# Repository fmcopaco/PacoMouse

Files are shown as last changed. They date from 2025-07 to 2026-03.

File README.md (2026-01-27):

# PacoMouse

Firmware for a throttle on the Arduino Nano or Wemos D1 Mini (ESP8266) platform. 
  * Versions for Loconet, Loconet over TCP/IP, Xpressnet, Xpressnet LAN, ECoS or Z21 protocols
  * Control of Locomotives
  * Control of accesories (turnouts, turntable, etc.)
  * CV and LNCV programming
  * Dispatch and phone lock feature
  * Locking of some features for guest or club use.
  * Automation
  * Games
  * Rotary encoder for loco speed and direction
  * Option for lever switch direction control
  * Keypad for easy numeric input
  * OLED in different sizes
  * Hardware test program included
  * Avaiable in different languages:

  Lang
  
---

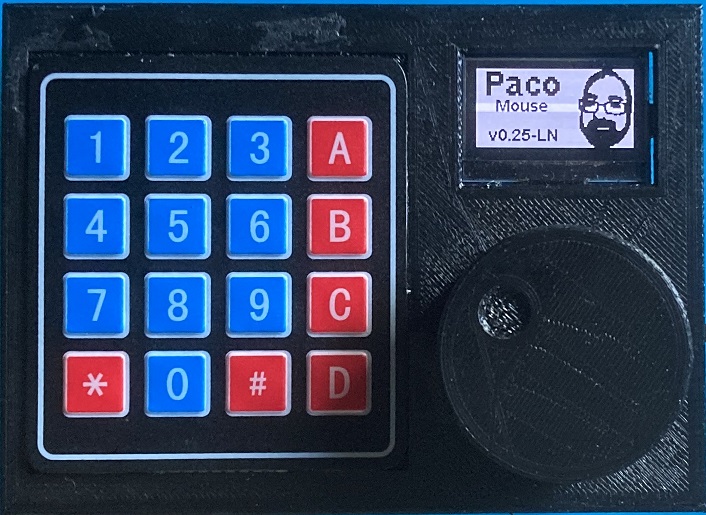
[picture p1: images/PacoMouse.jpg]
FirstVersion
  

  ## Videos

  PacoMouseRun (https://www.youtube.com/watch?v=anvKXDgOZIg)

  PacoMouseAutomation (https://www.youtube.com/watch?v=3rrbmPnA1nU)

  PacoMouseAutomation (https://www.youtube.com/watch?v=WS09ZdihYSQ)

  PacoMouseAutomation (https://www.youtube.com/watch?v=uLCelb744ps)

---

## Copyright
Copyright (c) 2022-2025 Paco Cañada, [The Pows](https://usuaris.tinet.cat/fmco/)   
All rights reserved.

---

## Documentation
- https://usuaris.tinet.cat/fmco/
- https://fmcopaco.github.io/
- Read the [manual](doc/PacoMouse_manual_v0.30.pdf) in the doc directory
- Step-by-step assembly of PacoMouse by [Isaac](https://www.iguadix.es/content/pacomouse-diy)

---

## License
Proprietary.  
Sources are only provided to compile and upload to the device.    
Modifiyng source code or forking/publishing this project ist not allowed.  
Commercial use is forbidden.  

---

## Used Libraries
  * ESP8266WiFi (LGPL)
  * WiFiUdp (LGPL)
  * Wire (LGPL)
  * Keypad (GNU)
  * Keypad_I2C (LGPL)
  * SSD1306Ascii (MIT)
  * SSD1306AsciiAvrI2c (MIT)
  * SSD1306AsciiWire (MIT)
  * LocoNet (LGPL)

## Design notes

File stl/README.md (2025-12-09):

# PacoMouse 3D files

STL files for PacoMouse

## PacoMouse Box

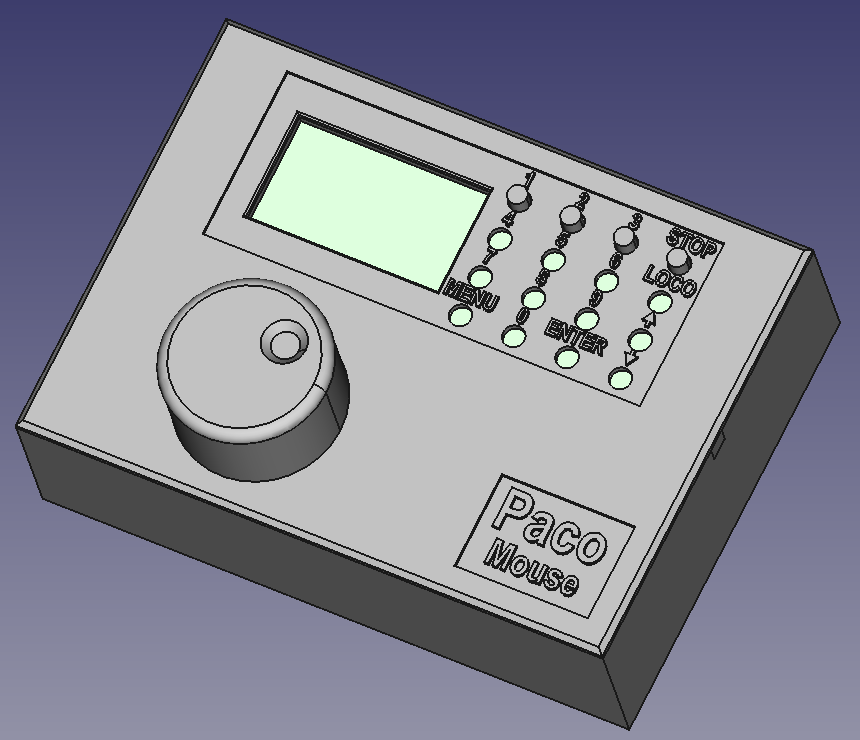
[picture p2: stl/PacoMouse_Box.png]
 

## PacoMouse Console

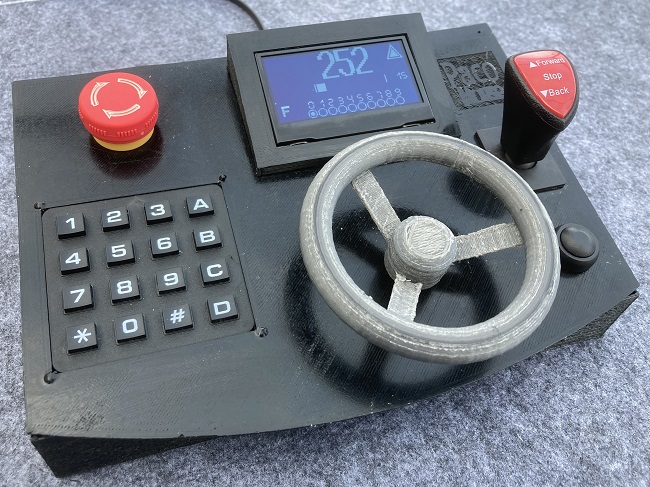
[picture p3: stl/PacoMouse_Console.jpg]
 
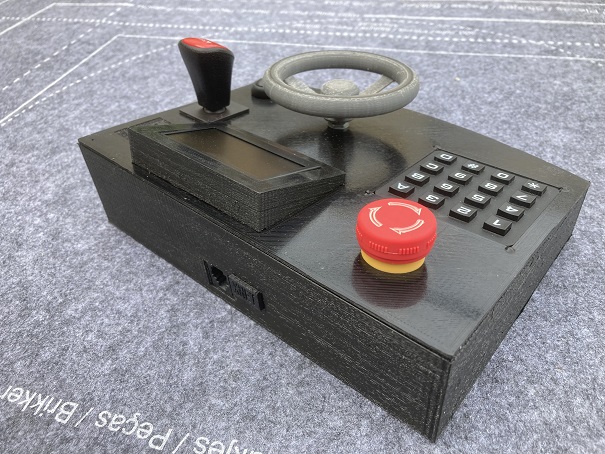
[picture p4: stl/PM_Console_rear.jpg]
 

## Other PacoMouse STL files

Isaac Guadix - https://www.iguadix.es/content/pacomouse-diy

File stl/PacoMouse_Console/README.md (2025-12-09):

# PacoMouse Console 3D files

## Bill of materials (BOM)

* Keypad 4x4
* Encoder EC11
* OLED (SSD1306, SH1106, SSD1309)
* PCB PacoMouse
* KCD4-604-6P (DPDT switch)
* Emergency switch 16mm
* Pushbutton 12mm
* 3 Screws M3x14mm
* 4 Screws M2x4mm
* 4 screws M2x6mm
* 4 Brass threaded insert M2x2
* 3 Brass threaded insert M3x4

## Wiring

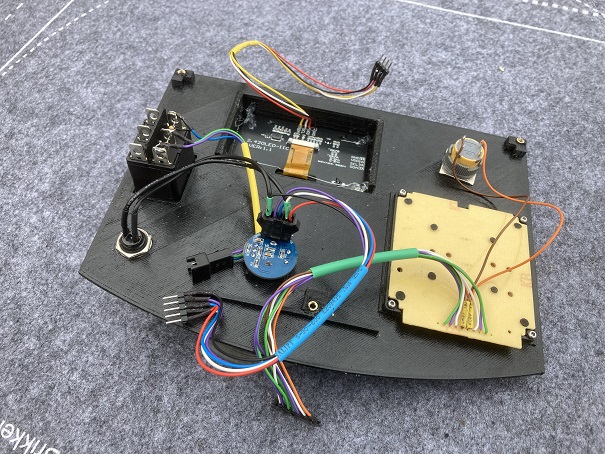
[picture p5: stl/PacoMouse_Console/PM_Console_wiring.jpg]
3dfile


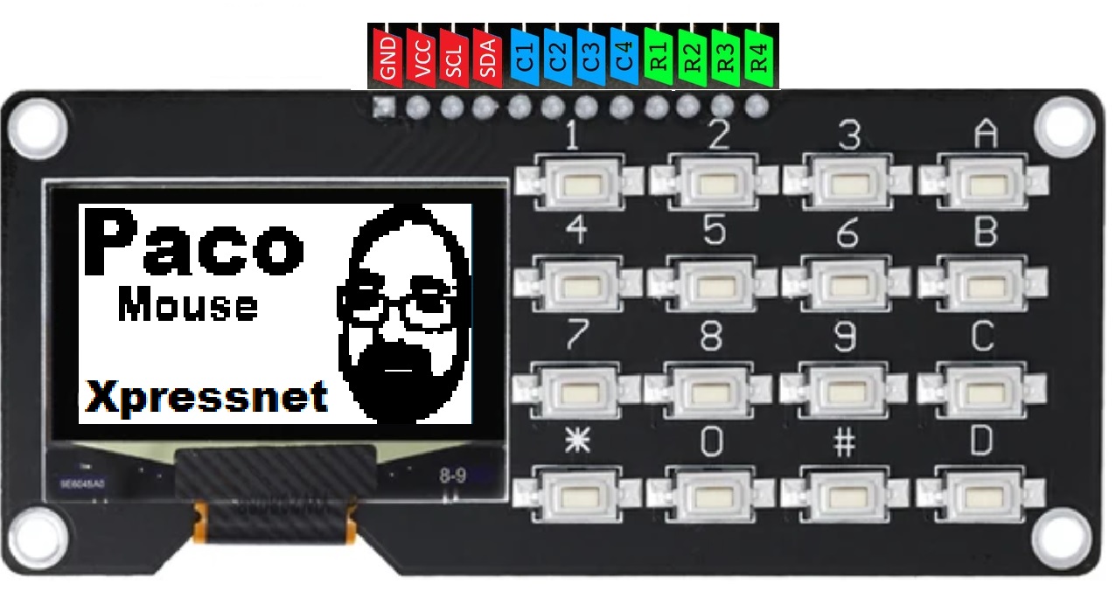
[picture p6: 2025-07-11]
images/oled_keypad4x4_pinout.jpg

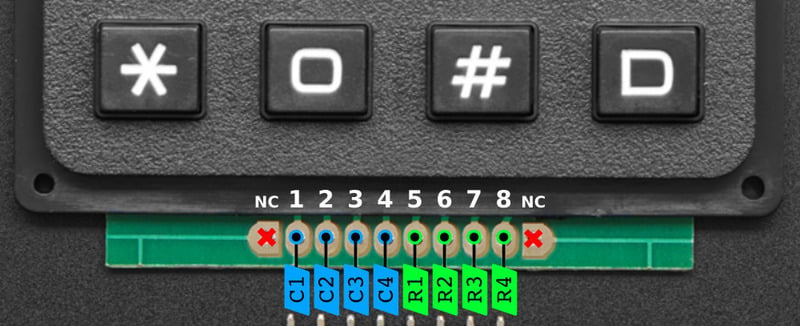
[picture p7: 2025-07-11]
images/keypad4x4_pinout.jpg

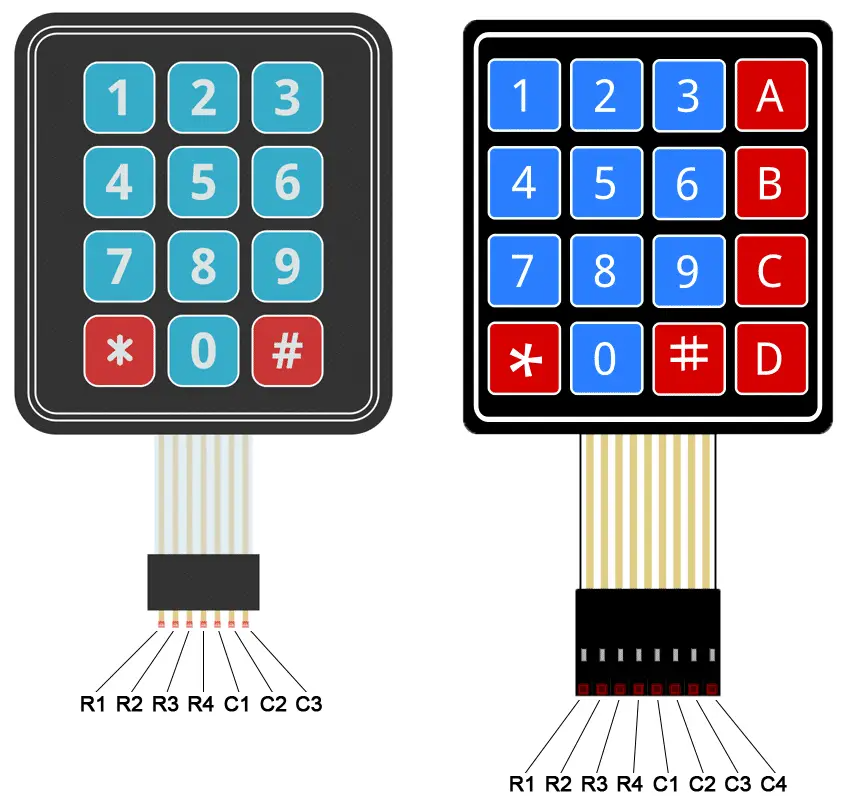
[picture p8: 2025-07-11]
images/keypad-pinout.png

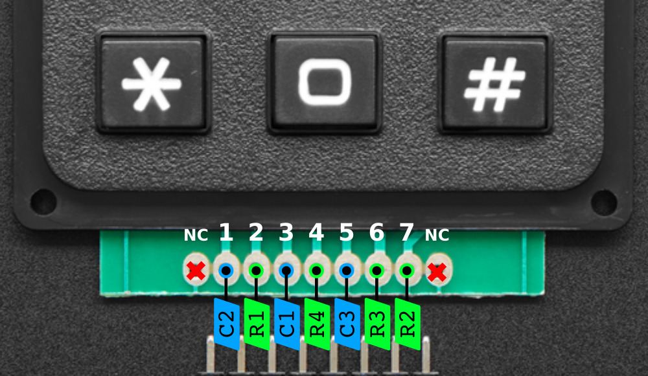
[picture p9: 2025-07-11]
images/keypad3x4_pinout.jpg

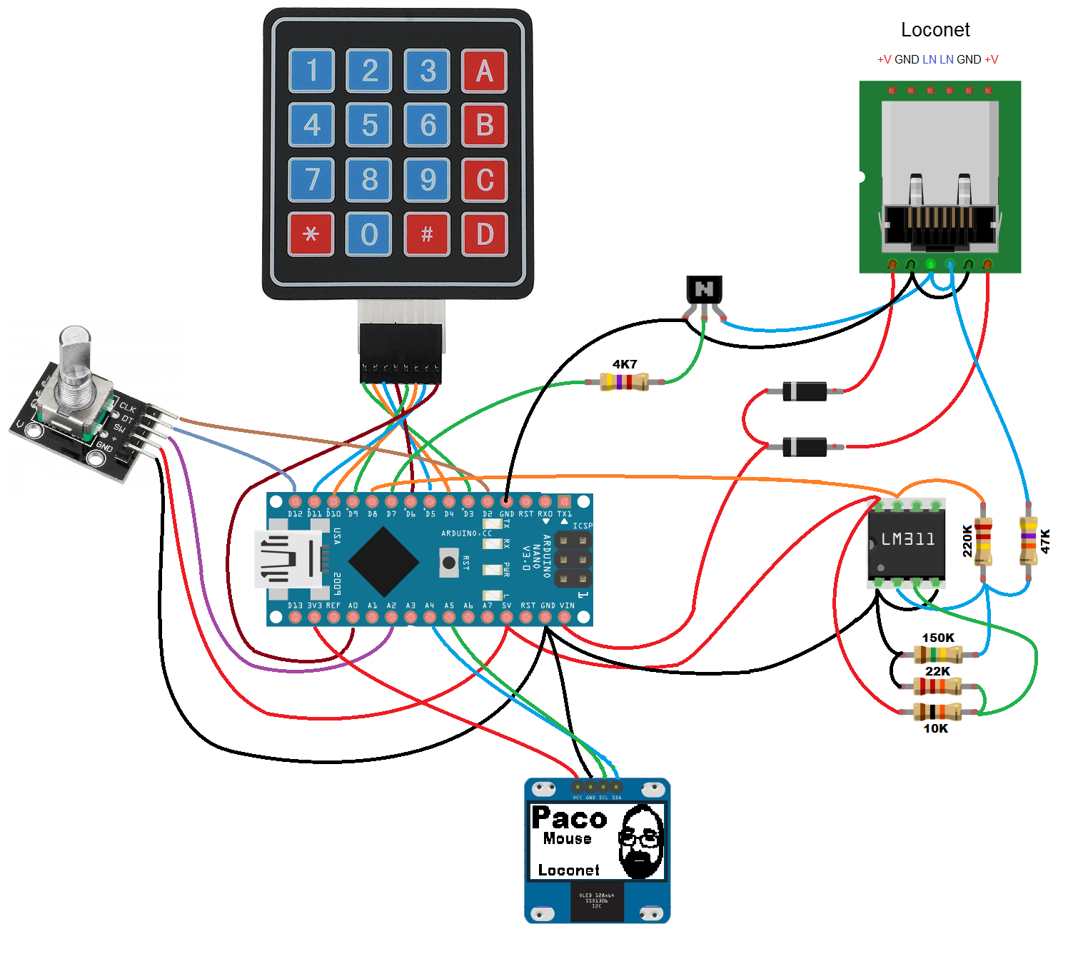
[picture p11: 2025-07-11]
images/PacoMouse_lnet_sch.png

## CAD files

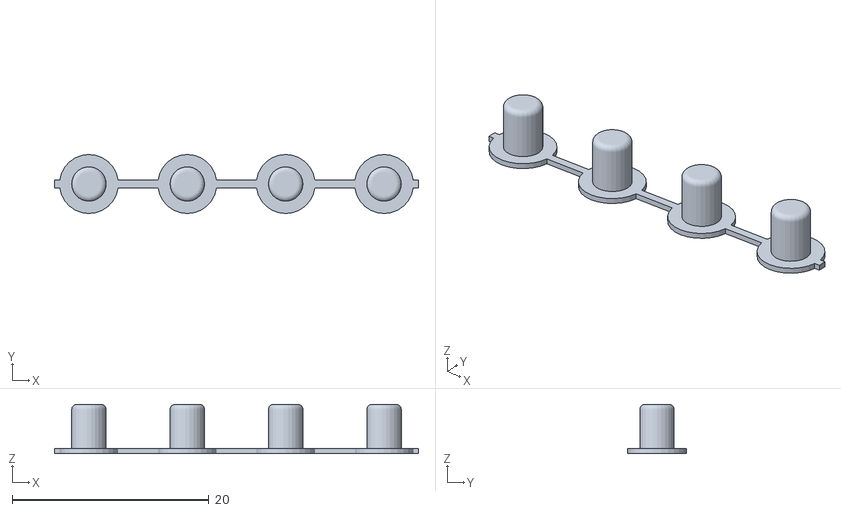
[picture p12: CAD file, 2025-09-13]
stl/PacoMouse_Box/PacoMouse_ConsoleLittle-Botones.stl
37.0 x 6.00 x 5.00

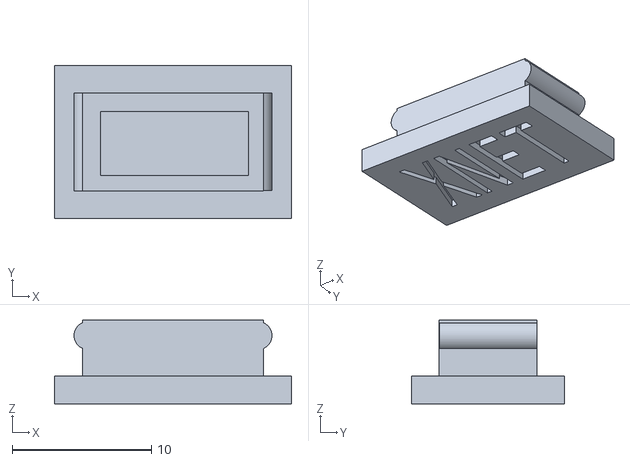
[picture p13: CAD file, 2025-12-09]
stl/PacoMouse_Console/Tapa XNET.stl
17.0 x 11.0 x 6.00

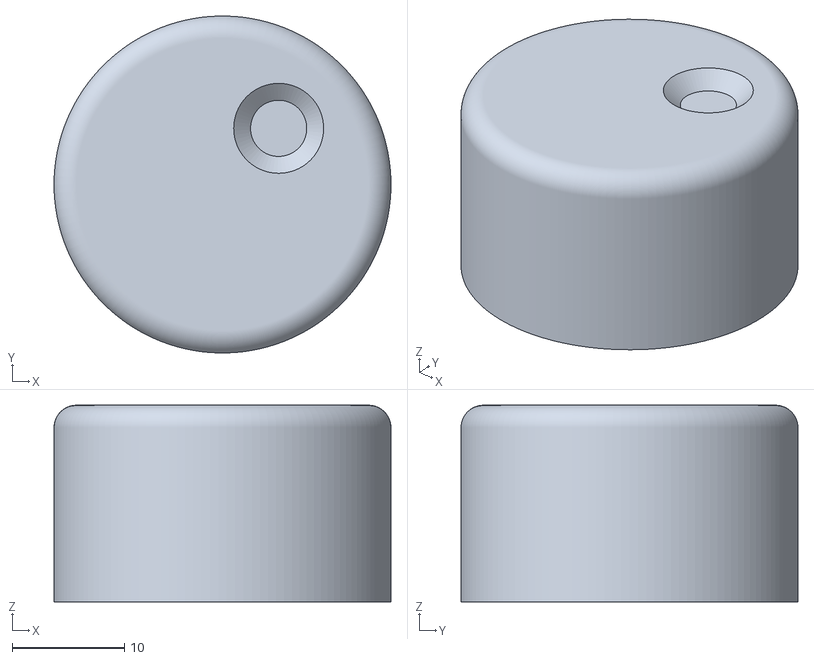
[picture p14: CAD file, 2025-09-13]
stl/PacoMouse_Box/PacoMouse_ConsoleLittle-Knob.stl
30.0 x 30.0 x 17.5

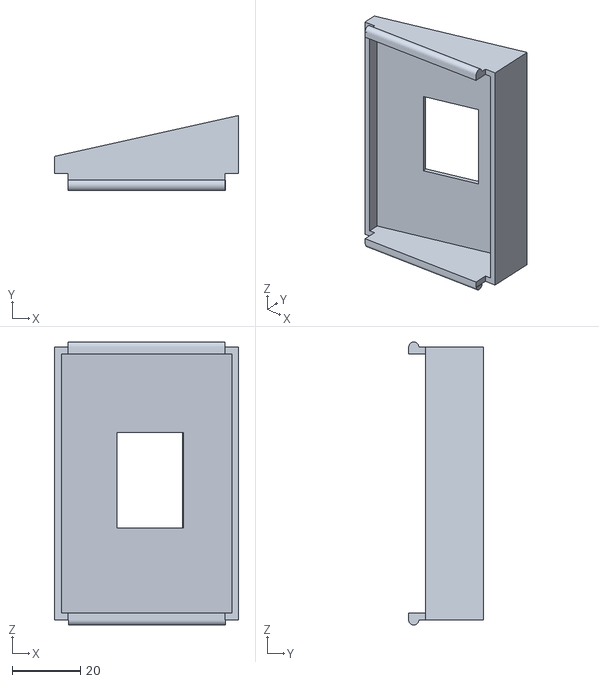
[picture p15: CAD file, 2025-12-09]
stl/PacoMouse_Console/PacoMouse OLED 096.stl
54.0 x 22.0 x 83.0

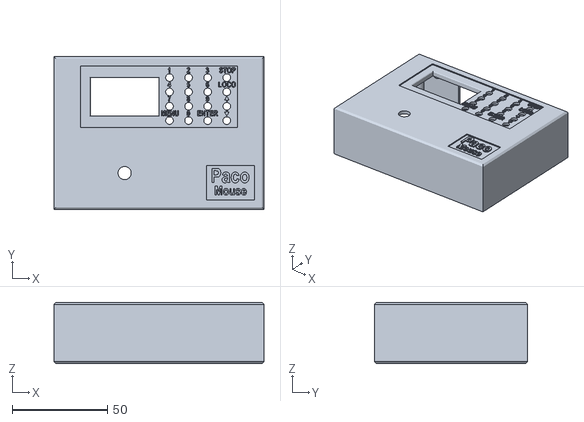
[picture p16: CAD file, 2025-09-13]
stl/PacoMouse_Box/PacoMouse_ConsoleLittle_v2-Top Cover.stl
110.0 x 80.0 x 32.0

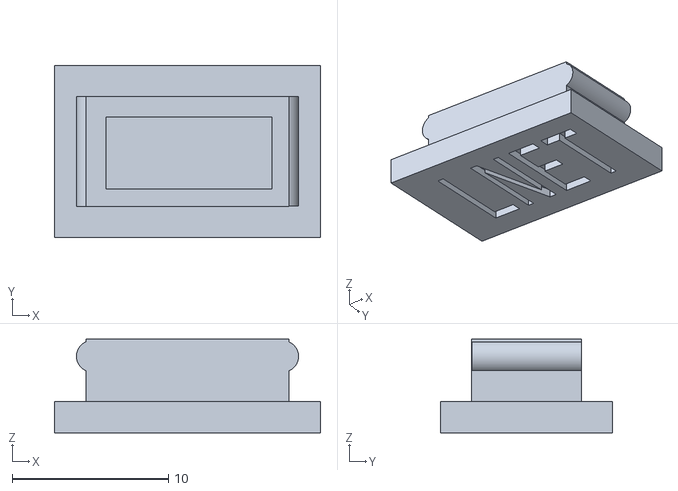
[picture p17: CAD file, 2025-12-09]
stl/PacoMouse_Console/Tapa LNET.stl
17.0 x 11.0 x 6.00

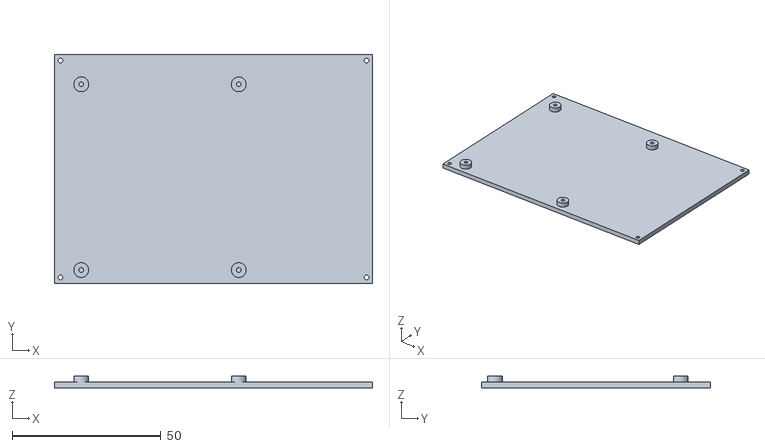
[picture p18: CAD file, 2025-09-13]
stl/PacoMouse_Box/PacoMouse_ConsoleLittle_v2-Bottom Cover.stl
107.0 x 77.0 x 4.00

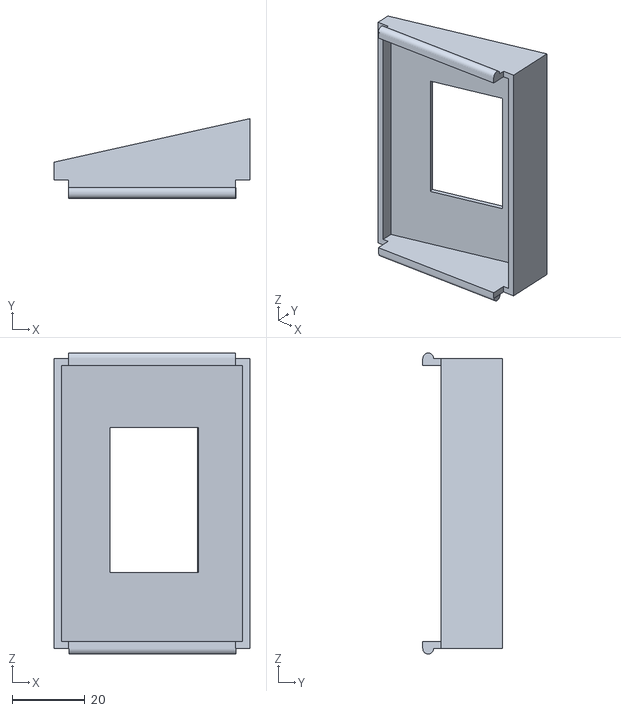
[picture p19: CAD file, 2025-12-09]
stl/PacoMouse_Console/PacoMouse OLED 13.stl
54.0 x 22.0 x 83.0

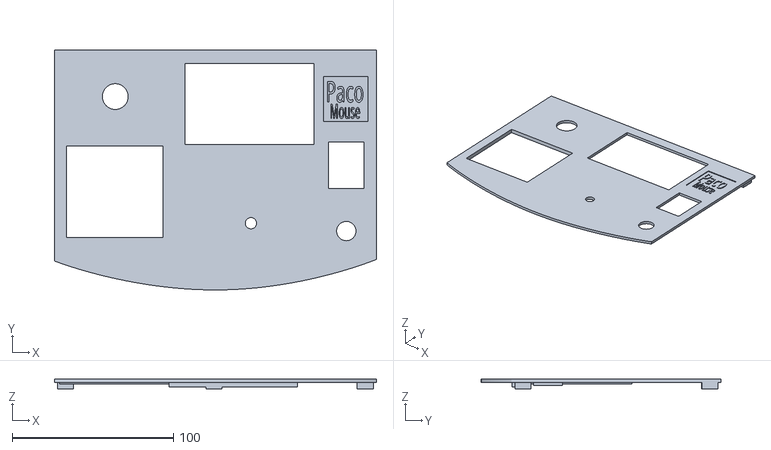
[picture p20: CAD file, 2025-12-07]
stl/PacoMouse_Console/PacoMouse Tapa v2.stl
199.9 x 148.9 x 6.00

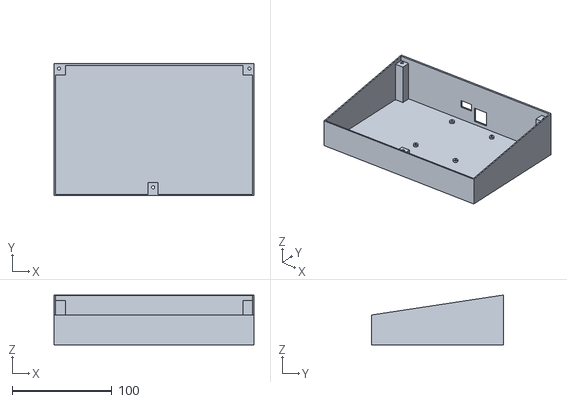
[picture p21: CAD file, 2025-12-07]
stl/PacoMouse_Console/PacoMouse Fondo.stl
200.0 x 131.9 x 50.0

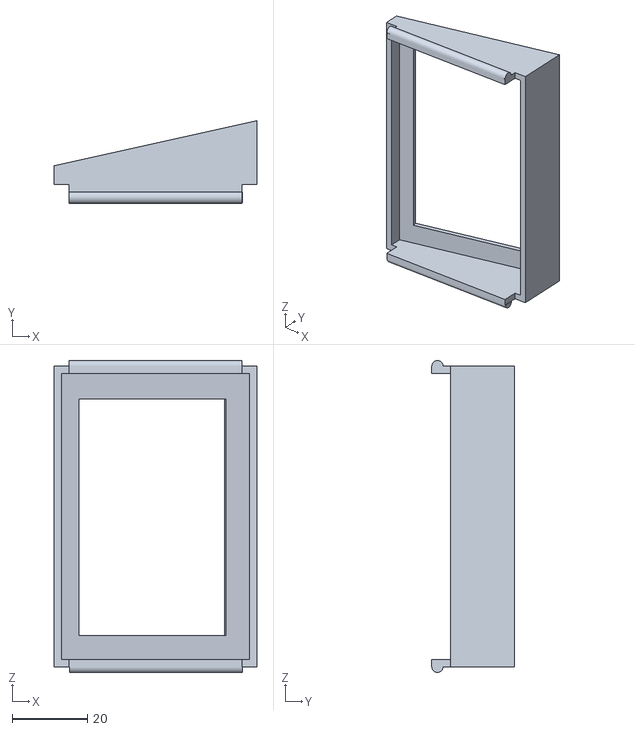
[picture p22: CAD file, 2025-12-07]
stl/PacoMouse_Console/PacoMouse OLED 242.stl
54.0 x 22.0 x 83.0

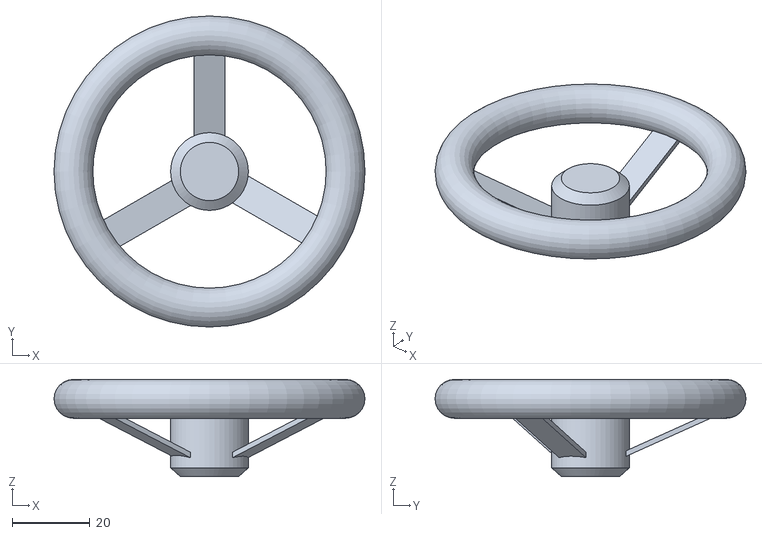
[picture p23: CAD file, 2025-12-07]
stl/PacoMouse_Console/Volante encoder.stl
80.0 x 80.0 x 25.0

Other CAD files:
stl/PacoMouse_Console/PacoMouse OLED 154.stl

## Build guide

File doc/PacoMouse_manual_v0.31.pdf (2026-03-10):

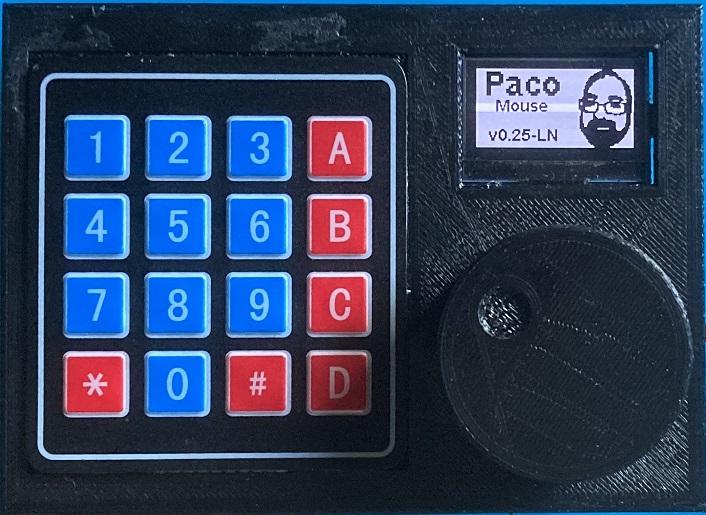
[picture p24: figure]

Paco Cañada | https://usuaris.tinet.cat/fmco/

# Manual de usuario del mando

# PacoMouse by Paco

Si eres de los impacientes o de los que nunca se leen el manual, ve directamente a la última página

v0.31 03/2026

Manual de usuario del mando | PacoMouse | 2

### Índice

El software usa librerías con diferentes licencias, siga todos sus términos incluidos en ellas. Loconet es una marca registrada de Digitrax, Inc. Xpressnet es una marca registrada de Lenz Elektronik GmbH. Z21 es una marca de Modelleisenbahn GmbH. Arduino es una marca registrada de Arduino S.r.l., ECoS es una marca de ESU electronic solutions ulm GmbH & Co. KG, Märklin es una marca registrada de Gebr. Märklin & Cie GmbH

## Introducción

PacoMouse surgió de la necesidad de tener un sencillo mando adicional para el control de locomotoras para un grupo modular como proyecto Do-It-Yourself (DIY). NO está permitida su comercialización.

Hay diferentes versiones de PacoMouse con conexión por bus Loconet o Xpressnet, o bien conexión WiFi con protocolo Z21, ECoS, Xpressnet o Loconet (LBServer o Binary). Monta la más adecuada para tu central:

Cable | WiFi
Central | Loconet | Xpressnet | Z21 | ECoS | Loconet | Xpressnet
Lenz LZV100, LZV200 | | ✓ | | | | (✓*)
DR5000, YD7001 | ✓ | ✓ | ✓ | | ✓ | ✓
Z21 (negra) | ✓ | ✓ | ✓ | | | (✓*)
z21, z21 start (blanca) | | ✓ | ✓
Multimaus | | ✓ | | | | (✓*)
Intellibox I, TwinCenter | ✓
Intellibox II | ✓
Intellibox 2neo | ✓ | | ✓ | | ✓
Daisy II WLAN | ✓ | | ✓ | | ✓
Digitrax | ✓
NanoX-S88 | | ✓ | | | | (✓*)
ECoS, ECoS2, CS1R | | | | ✓
Märklin CS1 (v2.0.4) | | | | ✓
JMRI | | | ✓ | | ✓

(✓*) Necesario un interface Lenz 23151 y un router WiFi

Basado en un Arduino Nano (también Uno o Pro Mini) para las versiones Loconet o Xpressnet por cable o bien un Wemos D1 mini (ESP8266) para las versiones Z21, Loconet, Xpressnet o ECoS por WiFi, dispone de un encoder rotativo tipo EC11 con pulsador, un teclado 3x4 o 4x4 y una pantalla OLED SSD1306, SH1106 o SSD1309 (tamaños 0.96”, 1.3”, 1.54” o 2.42”).

## 1. Instrucciones de seguridad

Este producto no es conveniente para niños menores de 14 años. Como puede ser ingerido por un niño menor de 3 años se debe mantener fuera de su alcance.

Un uso inadecuado puede implicar riesgo de lesiones debido a bordes afilados y puntas que pinchen.

Se recomienda la utilización de un soldador del tipo lápiz con una punta muy fina para evitar daños a los componentes.

## 2. Garantía

Toda la información para la construcción y uso del PacoMouse al ser un diseño "Hazlo tu mismo" (DIY -Do it Yourself) se proporciona "tal cual", sin garantía de ningún tipo, expresa o implícita, incluidos aquellos daños producidos por mala interpretación, montaje, uso o manipulación inadecuada.

## 3. Soporte y Ayuda

La información para la construcción y/o uso del mando PacoMouse se halla disponible en los sitios siguientes dónde es posible, sin estar asegurada ni tener compromiso alguno, obtener ayuda:

https://usuaris.tinet.cat/fmco
https://github.com/fmcopaco/PacoMouse
https://www.iguadix.es/content/pacomouse-diy

## 4. Antes del montaje

El firmware del PacoMouse se puede adaptar para cuatro tipos diferentes de montajes en función del tipo de interface que se monte.

Las versiones Loconet y Xpressnet por cable usan un Arduino Nano (también Uno o Pro Mini) mientras que las versiones Z21, Loconet, Xpressnet y ECoS por WiFi usan un Wemos D1 mini (ESP8266). En los Anexos de este documento encontrará los esquemas para montar cada una de las versiones.

Para su programación se usa el entorno Arduino IDE desde el cual es posible cargar el programa y las librerías necesarias así como adaptar el firmware de PacoMouse modificando el archivo config.h para nuestra placa. En los Anexos de este documento se describe como programar nuestro Arduino para personalizar un PacoMouse adaptado a nuestras necesidades.

## 5. Conexión

Al conectar el PacoMouse a la central mediante el interface correspondiente o dar tensión aparecerá la pantalla de bienvenida durante tres segundos indicando la versión (LN/LNW: Loconet, XPN/XPW: Xpressnet, ECS: ECoS o Z21).

Si anteriormente se había controlado una locomotora se pedirá información a la central sobre el estado actual de la misma y se mostrará la pantalla de Conducción, sino se mostrará la pantalla de Selección de Locomotora.

En las versiones con WiFi primero se intentará conectar a la red WiFi que el usuario haya configurado, sino se consigue conectar se buscarán las redes WiFi disponibles en la ubicación actual y se pedirá que se configure una y su password. Para conectarse a esta nueva red se debe apagar y volver a encender el PacoMouse.

## 6. Menú

En cualquier momento al pulsar la tecla 'MENU' ('*' en el teclado) se mostrará el menú de opciones de PacoMouse:

versión
Loconet

versión
Loconet WiFi

versión
Xpressnet / Z21/ ECoS

Conducir
Sel. Loco
Dispatch
Desvíos
Plataforma
Lanzadera
Prog. CV
Configurar

Conducir
Sel. Loco
Dispatch
Desvíos
Plataforma
Lanzadera
Automatizacion
Prog. CV
Configurar

Conducir
Sel. Loco
Desvíos
Plataforma
Lanzadera
Automatizacion
Prog. CV
Configurar

Girando en encoder rotativo podemos elegir una de las opciones del menú y al pulsar el botón se seleccionará la opción. También podemos usar las teclas '' y '' o bien 'MENU' para elegir la opción y la tecla 'ENTER' ('#' en el teclado) para seleccionarla.

## 6.1 Seleccionar Locomotora

Para seleccionar una locomotora entraremos su número mediante el teclado. El número máximo aceptado es 9999, si se supera se eliminará la primera cifra. Si el número es 0 se mostrará '?'. En la versión ECoS se limita a la lista de las locomotoras de la central por lo que no se puede introducir el número de locomotora, girando el encoder se mostrará el nombre de cada locomotora y su número.

Versión Xpressnet, Loconet, Z21 | Versión ECoS

Selecc. Loco
276
| BIG BOY 4013

78

Con la tecla 'ENTER' o pulsando el botón del encoder se seleccionará la locomotora visualizada y se mostrará la pantalla de Conducción.

La tecla 'LOCO' nos lleva directamente a esta opción del menú cuando se pulsa. Pulsándola de nuevo nos lleva a la opción de desvíos.

Stack de locomotoras

PacoMouse guarda las últimas locomotoras seleccionadas durante una sesión para acceder rápidamente a ellas sin tener que introducir en el teclado su número, para ello al girar el encoder o pulsar las teclas '' y '' se irán mostrando en orden de uso las direcciones de las locomotoras previamente seleccionadas.

Al desconectar el PacoMouse se perderá la lista de las locomotoras usadas de la sesión actual. En la versión ECoS al conectar se pide de nuevo la lista de las locomotoras a la central por lo que inicialmente el orden depende de ella.

## 6.2 Conducir

En la pantalla de conducción se muestra el número de locomotora y su sentido de conducción mediante una flecha ( adelante, atrás).

Mediante un barra horizontal se muestra la velocidad actual, a su lado se muestra el paso de velocidad. En la línea inferior se muestra, según se configure, el estado actual de las funciones de locomotora.

Si el Fast Clock esta activado en la central y se ha transmitido la hora actual, esta se mostrará en la esquina superior izquierda.

Opción BIG | Opción SMALL | Versión ECoS - Opción SMALL

Con el encoder rotatorio se podrá aumentar y disminuir la velocidad de la locomotora. Si se pulsa el botón del encoder estando la locomotora en marcha se detendrá la locomotora. Con la locomotora detenida pulsando el botón del encoder se cambia el sentido de marcha.

Si está activa la función lanzadera se mostrará . En las versiones Xpressnet, ECoS y Z21 si otro mando toma el control de nuestra locomotora se mostrará el símbolo

En la versiones Z21, Loconet WiFi, Xpressnet WiFi y ECoS si no se ha podido establecer conexión con la red WiFi se mostrará en la pantalla, si la batería esta baja se mostrará el símbolo

Con las teclas '' y '' (o la tecla 'ENTER' en el teclado 3x4) se podrá seleccionar las funciones mostradas según se haya establecido su tamaño:

BIG: F0-F4, F5-F8, F9-F12, F13-F16, F17-F20, F21-F24, F25-F28. Mediante el teclado numérico se podrá activar y desactivar las funciones, la tecla '0' siempre activa/desactiva la F0, las teclas '1' a '4' hacen lo mismo con las cuatro funciones restantes mostradas. Además, para un rápido acceso, si se está mostrando F0-F4 (o F0-F8 según se configure) las teclas '5' a '8' controlan las funciones F5 a F8. Con la tecla ‘9’ si esta activo el Fast Clock se podrá visualizar a mayor tamaño, y la dirección de locomotora a un tamaño menor, volviéndola a pulsar se volverá a mostrar a su tamaño original.

SMALL: F0-F9, F10-F19, F20-F28. Mediante el teclado numérico se podrá activar y desactivar las funciones con las teclas '0' a '9'. Cuando se muestra F2 (F20-F28) con la tecla ‘9’ si esta activo el Fast Clock se podrá visualizar a mayor tamaño, y la dirección de locomotora a un tamaño menor, volviéndola a pulsar se volverá a mostrar a su tamaño original.

La tecla 'STOP' al pulsarla deja sin tensión la salida de vías (Emergency Off).

### 6.3 Dispatch (Opción sólo para versiones Loconet)

En Loconet podemos despachar (Dispatch PUT) nuestra locomotora para que pueda tomar el control (Dispatch GET) un mando sin posibilidad de seleccionar locomotoras (Fred, etc.)

DISPATCH
GET Loco
PUT Loco 276
Estacion

Al despachar nuestra locomotora (PUT), esta se coloca en un slot especial de la central para que pueda tomar el control otro mando, por lo que seguidamente se mostrará la pantalla de Selección de locomotora para que podamos seleccionar otra locomotora.

Si no controlamos ninguna locomotora en lugar de 'PUT Loco' aparecerá 'Sel. Loco' para seleccionar una manualmente.

PacoMouse también puede tomar el control de una locomotora previamente despachada por otro mando mediante la opción 'GET Loco'

Mediante el encoder seleccionamos la opción y pulsando el botón del encoder se procede a despachar o tomar el control de una locomotora previamente despachada.

Si no hay locomotora disponible para tomar el control al escoger 'GET Loco' aparecerá la pantalla de espera.

?

PacoMouse dispone de un sistema único de simulación de bloqueo telefónico transferir trenes entre estaciones colaterales cada una equipada con un PacoMouse y haciendo uso de una dirección de accesorios asignada a cada mando y el Dispatch de Loconet.

Disponemos de un listín telefónico (vea 6.8 Configurar) con el número de teléfono (número de accesorio) de nuestra estación (nuestro PacoMouse) y de hasta cuatro estaciones colaterales.

Cuando deseemos transferir la locomotora que controlamos a la estación colateral seleccionamos la opción del menú Dispatch Estacion y nos aparecerá la lista de las cuatro estaciones colaterales de la que elegiremos a la que queremos llamar:

Estacion A
Estacion B
Estacion C
Estacion D

En nuestra pantalla se nos mostrará la llamada en curso. Con la tecla 'MENU' podemos cancelar la llamada.

En la pantalla del PacoMouse al que estamos llamando se mostrará la llamada entrante según su listín telefónico:

Con la tecla 'ENTER' podemos aceptar la llamada y con la tecla 'MENU' podemos rechazarla. En caso de aceptarla automáticamente se nos despachará la locomotora desde el otro PacoMouse y nos aparecerá la pantalla para controlarla:

El PacoMouse de la estación de origen mostrará la pantalla de Selección de locomotora una vez despachada:

Selecc. Loco
?

En caso de haber rechazado la llamada se nos mostrará el menú y en el PacoMouse de la estación de origen mostrará la advertencia de que no envíe el tren:

Si al realizar la llamada la estación de destino ya tiene el teléfono descolgado (su accesorio esta en VERDE ) por otra llamada se nos mostrará que no ha sido posible la comunicación, pulse la tecla 'MENU' para finalizar la llamada:

NOTA: Durante la llamada seguimos controlando la locomotora que tenemos seleccionada con el encoder. Podemos impedir que nos llamen descolgando el teléfono (moviendo el accesorio de nuestra estación a la

posición VERDE ) y volver a permitir las llamadas colgándolo (moviéndolo a posición ROJO ).

## 6.4 Desvíos

Para mover un desvío o accesorio digital introduciremos su número, en el icono de la derecha se mostrará su posición actual según informa la central. Con la tecla 'ENTER' cambiaremos su posición actual de recto a desviado o viceversa. También podemos cambiar el número de desvío con la tecla '' incrementándolo o con la tecla '' decrementándolo.

Selec. Desvío
23
PacoMouse | Loconet | Lenz | Roco

Mediante el encoder podremos continuar controlando la locomotora que tenemos seleccionada. Pulsando la tecla 'LOCO' desde la opción de selección de locomotoras nos lleva a esta opción para mover desvíos.

## 6.5 Plataforma

Con PacoMouse podemos controlar una plataforma giratoria digitalizada con un decodificador compatible con el 7686 de Märklin en la dirección base 209 (Keyboard 14) o 225 (Keyboard 15) o bien con el TurnControl 6915 de Fleischmann en la dirección base 200.

El control básico de la plataforma lo realizaremos desde esta pantalla:

Si usamos el decodificador 7886 o compatible, con la tecla '1' moveremos el puente a la siguiente vía de salida situada en sentido contrario a las agujas del reloj (CCW) y con la tecla '3' lo moveremos a la siguiente vía de salida en sentido horario (CW). Con la tecla '2' realizaremos el giro de 180º del puente.

Si usamos el decodificador 6915 o compatible, con la tecla '1' seleccionaremos el movimiento en sentido contrario a las agujas del reloj (CCW) y con la tecla '3' el sentido horario (CW). Con la tecla '2' realizaremos el giro de 180º del puente.

Con la tecla 'ENTER' pasaremos a la siguiente pantalla donde podremos escoger directamente la vía de destino del movimiento del puente:

2

Via destino

Mediante el teclado introduciremos el número de la vía de destino, y al pulsar 'ENTER' el puente se moverá hacia ella.

En la pantalla se mostrará brevemente el símbolo para indicar el inicio del movimiento del puente.

Si el numero de vía es cero o inválido para el decodificador de plataforma se mostrará un interrogante (?). Si en este momento se pulsa 'ENTER' se volverá a la pantalla de movimiento básico de la plataforma.

Mediante el encoder podremos continuar controlando la locomotora que tenemos seleccionada.

## 6.6 Lanzadera

Podemos dejar a PacoMouse que controle nuestra locomotora como un tren lanzadera entre dos estaciones si estas están dotadas de retrocontactos. Al llegar a una estación y activar su retrocontacto el tren se detendrá y tras un periodo de tiempo invertirá el sentido, tras otro periodo de tiempo igual reiniciará la marcha hacia la otra estación.

Con el encoder controlamos la velocidad y el sentido, las funciones las podemos cambiar desde la pantalla de conducción. El frenado en las estaciones lo hará según lo programado en sus CV.

Con la tecla 'ENTER' se podrán modificar los datos, pasando de uno a otro: La activación de la función lanzadera (con la tecla '1'), los dos retrocontactos y el periodo de tiempo (hasta 255 segundos). Con la tecla 'MENU' se saldrá del modo edición.

En las versiones Loconet se pueden seleccionar los retrocontactos 1 a 2048, en la Xpressnet los RS del 1.1 al 128.8, en la Z21 los retrocontactos R-BUS del 1.1 a 20.8 y en la ECoS los S88 de 1.1 al 32.16.

Si desea cambiar alguno de los valores, así como la activación de la función lanzadera, hágalo cuando la locomotora no esté activando ninguno de los contactos.

ATENCIÓN | Al cambiar de locomotora se desactivará la función lanzadera por lo que esta no se detendrá en las
| estaciones si esta está en marcha.

### 6.7 Automatización (Opción sólo para Xpressnet, Loconet WiFi, Z21 y ECoS)

PacoMouse puede ejecutar pequeñas acciones automáticas para automatizar nuestra maqueta mediante el menú Automatización. Si no hay definida ninguna automatización se mostrará la siguiente pantalla:

Automatizacion
0/ 0

En caso de que ya tengamos definida alguna se mostrará de la siguiente manera:

Automatizacion
2/ 6
IdaVuelta

Girando el encoder podemos mostrar todas las automatizaciones que tengamos definidas. Con la tecla '1' podemos arrancar la automatización mostrada (o detenerla), con la tecla '2' añadimos una nueva automatización y con la tecla '3' podemos editar la automatización mostrada.

Al pulsar la opción de añadir o editar la automatización se mostrará la siguiente pantalla para editar el nombre de la misma:

Nombre:

IdaVuelta

El nombre puede tener un máximo de 13 letras y no puede contener espacios. Con el encoder seleccionaremos el nuevo carácter a añadir y con su botón lo añadiremos. Si el carácter seleccionado es el espacio se borrará el último carácter introducido.

El icono | indica que se pueden editar las acciones que ejecutará esta automatización al pulsar la tecla '3'. Si la
automatización ya existía aparece el icono | y con el botón '1' podemos borrarla completamente después de
confirmarlo en la siguiente pantalla:

Borrar?

IdaVuelta

Con la tecla '2' la borramos definitivamente y con la tecla '3' cancelamos su eliminación.

Cuando se añade una nueva automatización, la única acción definida es la de fin de la automatización:

IdaVuelta
1/ 1

Con la tecla '2' podemos añadir más acciones a la automatización y con la tecla '3' cuando aparece el icono guardamos la automatización. Al pulsar la tecla ‘MENU’ se saldrá de la edición, si no se ha guardado la automatización se perderán todos los cambios realizados.

Las acciones que podemos añadir son las siguientes:

Acción | Descripción
10 10 10 | Mover el accesorio a posición desviado
10 10 10 | Mover el accesorio a posición recto
65.1 Esperar a que el contacto este libre 67.8 Esperar a que el contacto este ocupado 3 Seleccionar la locomotora
20% | Establecer velocidad de la locomotora
21 Desactivar función de la locomotora 0 Activar función de la locomotora
| Establecer el sentido de movimiento hacia adelante
| Establecer el sentido de movimiento hacia atrás
| Cambiar el sentido de movimiento
| Detener la locomotora (Stop Emergencia)
12.0s | Esperar un tiempo (max. 400s)
Ruta | Arrancar otra automatización
| Volver a empezar la automatización
| Fin de la automatización.

Cuando se añade o edita una acción con el encoder podemos seleccionar una de ellas, si la acción necesita un parámetro numérico podemos escribirlo con el teclado.

IdaVuelta
1/ 1
10

La acción necesita el nombre de otra automatización para ello pulse el encoder y ya podrá seleccionar el nombre de otra automatización ya definida.

IdaVuelta
1/ 1
Silbato_y_luz

Con la tecla ‘ENTER’ se saldrá de la edición de la acción y ahora se mostrará incluida en la secuencia:

IdaVuelta
1/ 2
10

Ahora con la tecla ‘3’ podemos editar la acción mostrada, con la tecla ‘2’ podemos añadir otra acción y con la tecla ‘1’ podemos borrar la acción mostrada después de confirmarlo en esta pantalla:

Borrar?

10

Con la tecla '2' la borramos definitivamente y con la tecla '3' cancelamos su eliminación.

No olvide ir hasta la acción | y guardar la automatización | para no perder los cambios.
La acción | reinicia la automatización, las acciones posteriores no se ejecutarán, úsela con
precaución para evitar colapsar el sistema con muchas acciones simultáneas. Para detener la
automatización en la pantalla principal de automatización en lugar del icono | aparece el icono | ,
pulsando la tecla ‘1’ se detendrá.

Tenga en cuenta cuando use la acción que la automatización indicada no se puede ejecutar si ya se está ejecutando. Su ejecución es independiente de la actual por lo que si tiene que esperar a que finalice use la acción si es necesario.

Las acciones relacionadas con la locomotora se aplicarán a la locomotora actualmente seleccionada en
PacoMouse. La acción | cambia la locomotora controlada por el mando. Estas acciones pueden
interferir en el funcionamiento de la función Lanzadera ( | ) si esta activada.

Las acciones sobre accesorios se introducen en una cola para ir enviándolas a la central pero no
ralentizan la ejecución de la automatización, use la acción | si es necesario.
Tenga en cuenta cuando introduzca direcciones de contacto | que algunos valores no son válidos
como la entrada 0 (o 9 en algunos sistemas), PacoMouse intenta corregir el error y muestra una dirección válida, escriba completamente la dirección de contacto si contiene algún dígito conflictivo.

## 6.8 Programación de CV

Podemos programar las CV de nuestros decodificadores tanto en vía de programación (lectura y escritura en modo Direct) como en vía principal (PoM, sólo escritura). En la versión Loconet también las LNCV. Además las principales CV se pueden modificar directamente desde el menú usando la vía de programación:

versiones
Loconet

versión
Xpressnet / Z21 / ECoS

Via Program.
Via Principal
Direcc. Loco
Vel. min.
Vel. media
Vel. max.
Acelerac.
Frenado
Configurac.
Fabricante
Prog. CV bits
LNCV

Via Program.
Via Principal
Direcc. Loco
Vel. min.
Vel. media
Vel. max.
Acelerac.
Frenado
Configurac.
Fabricante
Prog. CV bits

La opción de programar en vía de programación nos permite introducir por el teclado el número de CV a modificar:

Prog

CV 7

En la versión Xpressnet en función del tipo y versión de la central el número máximo de CV es el 256 o el 1024.

Al pulsar 'ENTER' se leerá el valor de la CV y se nos mostrará en pantalla. En la línea inferior se mostrarán los bits activados para ese valor al objeto de facilitar la interpretación de las CV que se usan por bits como la CV29. Si no se ha podido leer la CV se mostrará '???'

Prog

CV7: 36

- - 5 - - 2 - -
Si queremos modificar el valor, introduciremos el nuevo valor mediante el teclado y al pulsar 'ENTER' se escribirá en el decodificador. Si pulsamos 'MENU' podremos escoger otra CV sin modificar el valor de la actual.
Igualmente la opción de programar en vía principal nos permite modificar la CV que introduzcamos por teclado. Se nos muestra la locomotora sobre la que realizaremos la programación, si no es la correcta tendremos que seleccionarla en el menú de Selección de locomotora, podemos pulsar la tecla 'LOCO' para acceder directamente a la opción.

PoM Loco: 771
CV 65

Las principales CV se pueden modificar directamente desde el menú de programación. Al seleccionar la opción se leerá la CV desde la vía de programación y se mostrará su valor en pantalla.
Las principales CV son: La dirección (CV1, CV17, CV18), las velocidades mínima (CV2), media (CV6) y máxima (CV5), la aceleración (CV3), el frenado (CV4), la configuración (CV29) y el fabricante (CV8).

Para la CV8, una vez leída, se nos mostrará también el nombre del fabricante en caso de que sea uno de los más habituales:

Prog | Zimo
CV8: | 145
| 7- - 4 - - - 0

La opción de dirección de la locomotora leerá la dirección actual desde las CV1 o CV17 y CV18 según este programado como dirección corta o larga en la CV29. Además la introducirá en el stack.

Podemos introducir desde el teclado la nueva dirección y al pulsar 'ENTER' se programarán adecuadamente tanto las CV1, o CV17 y CV18 además de la CV29 según el caso por lo que no nos tendremos que preocupar de si es dirección corta o larga.

Prog Direcc. Loco

771

En la opción de programación de los bits de la CV al pulsar los dígitos 0 a 7 se modificarán los bits correspondientes de la CV, facilitando la programación de las CV tipo CV29 que se programan por bits.

NOTAS:

Tenga esto en cuenta si asigna una dirección comprendida entre 100 y 127:

- En los sistemas Loconet la dirección corta comprende las direcciones 1 a 127, mientras que en sistemas Xpressnet comprende las direcciones 1 a 99. En la Z21 se puede escoger en la configuración para que corresponda con lo establecido en la central. La versión de PacoMouse (Z21, Loconet o Xpressnet) tiene en cuenta estas características a la hora de programar las CV de dirección.
- Hay centrales como la Digikeijs DR5000 y la Z21 que permiten indicar el número mayor de dirección corta.
- El protocolo ECoS implementa la programación de CV a partir de la versión 4.1.0 y en vía principal a partir de la versión 4.2.3, en la Märklin CS1 no se pueden programar CV al no permitirlo el protocolo.

LNCV (Opción sólo para Loconet)

En la versión Loconet también se pueden programar las LNCV de los módulos. Primero se tiene que indicar el número de artículo (consulte su manual) y el número de módulo con las teclas numéricas y pulse 'ENTER'

LNCV

Art-num: 5088

Mod-num: 1

Algunos módulos tienen una función de descubrimiento con la que se informa de su número de artículo y módulo, para ello conecte solamente el módulo a programar en el bus e introduzca 65535 como número de artículo, al pulsar 'ENTER' si posee esta función aparecerá su número de artículo, al pulsar nuevamente 'ENTER' aparecerá el numero de módulo.

Ahora podrá programar las LNCV, primero introduzca su número según la que quiera programar (consulte el manual de su módulo) al pulsar 'ENTER' se leerá la LNCV seleccionada.

LNCV 5088-1

LNCV: 217

Si quiere modificar su valor, introduzca mediante el teclado numérico su nuevo valor y pulse 'ENTER', si no desea modificarlo pulse ‘'MENU' para volver a la selección de LNCV.

LNCV 5088-1
217
1000

Si no se ha podido modificar porque no está implementada la LNCV o es de sólo lectura se mostrará ? como valor de la LNCV. Una LNCV no implementada suele mostrar 65535 como valor al leerla.

ATENCIÓN: La LNCV0 contiene el número de módulo, si lo modifica vuelva a leerlo para comprobar que se ha escrito correctamente y el módulo salga correctamente del modo programación.

Si escoge un número de artículo y módulo que no existe o no está conectado al bus las respuestas no serán inmediatas, tardarán unos dos segundos en mostrarse por lo que debe descartarse el valor mostrado ya que es un valor aleatorio.

## 6.9 Configurar

En el apartado Configurar se muestra un menú con las diferentes opciones que el usuario puede escoger para adaptar PacoMouse a sus preferencias:

El cursor muestra si la opción se puede escoger y '>' en caso contrario. Para escoger la opción pulse el botón del encoder o bien la tecla 'ENTER' para salir sin modificar pulse la tecla 'MENU'

versión Loconet WiFi | versión Xpressnet WiFi | versión Z21 | versión ECoS

OPCIONES:
CONTRASTE
20
MODO STOP

Velocidad 0

Stop Emerg.

Maniobras
TIPO CENTRAL

IB II / DR5000

Uhlenbrock

Digitrax
WIFI
SSID
Password
IP
SERVIDOR
Puerto

Binary

LBServer
PLATAFORMA

7686 KB14

7686 KB15

F6915
RELOJ
Ajustar

Pulso Sinc.
BLOQUEAR

Sel. Loco

Desvios

Prog.CV
JUEGO

### 3 en raya

Snake
Flappy Bird
Paku Paku
Pong
LISTIN TELF.
PacoMouse
Estaciones

OPCIONES:
CONTRASTE
20
MODO STOP

Velocidad 0

Stop Emerg.

Maniobras
WIFI
SSID
Password
IP
PLATAFORMA

7686 KB14

7686 KB15

F6915

Dir. Roco
RELOJ
Ajustar
BLOQUEAR

Sel. Loco

Desvios

Prog.CV
JUEGO

### 3 en raya

Snake
Flappy Bird
Paku Paku
Pong

OPCIONES:
CONTRASTE
20
MODO STOP

Velocidad 0

Stop Emerg.

Maniobras
WIFI
SSID
Password
IP
DIR. CORTA

### 1 a 99

### 1 a 127

PLATAFORMA

7686 KB14

7686 KB15

F6915

Dir. Roco
RELOJ
Ajustar
BLOQUEAR

Sel. Loco

Desvios

Prog.CV
JUEGO

### 3 en raya

Snake
Flappy Bird
Paku Paku
Pong

OPCIONES:
CONTRASTE
20
MODO STOP

Velocidad 0

Stop Emerg.

Maniobras
WIFI
SSID
Password
IP
PLATAFORMA

7686 KB14

7686 KB15

F6915
BLOQUEAR

Sel. Loco

Desvios

Prog.CV
JUEGO

### 3 en raya

Snake
Flappy Bird
Paku Paku
Pong

versión Loconet | versión Xpressnet

OPCIONES:
CONTRASTE
20
MODO STOP

Velocidad 0

Stop Emerg.

Maniobras
TIPO CENTRAL

IB II / DR5000

Uhlenbrock

Digitrax
PLATAFORMA

7686 KB14

7686 KB15

F6915
BLOQUEAR

Sel. Loco

Desvios

Prog.CV
LISTIN TELF.
PacoMouse
Estaciones

OPCIONES:
CONTRASTE
20
MODO STOP

Velocidad 0

Stop Emerg.

Maniobras
DIR. XPRESSNET
8
PLATAFORMA

7686 KB14

7686 KB15

F6915

Dir. Roco
BLOQUEAR

Sel. Loco

Desvios

Prog.CV

CONTRASTE

El contraste se puede escoger girando el encoder entre un valor de 0 y 255 (0 y 100 para el SSD1309 debido a su alto consumo). El contraste irá variando según el valor escogido.

MODO STOP

En la conducción de locomotoras cuando se pulsa el botón del encoder si esta está en movimiento se detiene. Se puede escoger si lo hará según lo programado en su CV de frenado al enviar velocidad 0 o hará una parada de emergencia.

Se puede activar el modo maniobras en el que se puede disminuir la velocidad hasta el paso 1 con el encoder. Para detener la locomotora hay que pulsar el botón del encoder. De esta forma se tiene un control más exacto de las paradas cuando se hacen maniobras.

TIPO CENTRAL (Opción sólo para versiones Loconet)

Para las funciones F9 a F28 las órdenes a enviar por Loconet son diferentes según el tipo de central al que se esté conectado. Aquí se puede indicar el tipo de central.

DIR.XPRESSNET (Opción sólo para Xpressnet)

Cada mando Xpressnet necesita una dirección única de bus para una correcta comunicación. Escoja una entre 1 y 31 que no utilice otro mando.

WIFI (Opción sólo para Z21, Loconet WiFi, Xpressnet WiFi y ECoS)

Podemos seleccionar el SSID de la WiFi de nuestra central desde una lista, el Password y su dirección IP (por defecto es la 192.168.0.111).

En la opción SSID con el encoder podemos seleccionar entre los diferentes elementos y con su botón o la tecla 'ENTER' seleccionar esa red.

En la opción Password con el encoder seleccionaremos el nuevo carácter a añadir y con su botón lo añadiremos. Si el carácter seleccionado es el espacio se borrará el último carácter introducido. Con la tecla 'ENTER' guardaremos el nuevo Password.

En la opción IP con el encoder seleccionaremos el valor de cada uno de los cuatro grupos de números entre 0 y 255, con su botón pasaremos al siguiente grupo y con la tecla 'ENTER' guardaremos la nueva IP.

Los cambios se tendrán en cuenta la próxima vez que se reinicie PacoMouse.

SERVIDOR (Opción sólo para versión Loconet WiFi)

Podemos seleccionar el tipo de servidor para el protocolo Loconet over TCP/IP entre LBServer o Binary. Debemos seleccionar correctamente el Puerto para establecer la comunicación, los puertos por defecto suelen ser los mostrados en la tabla pero compruébelo en la configuración de su servidor.

Central | LBServer Port | Binary Port
DR5000 | 5550 | 5550 | Puerto
| 1234 | 5560 | 1234 YD7010
Intellibox2neo | 1234
Daisy II WLAN | 1234
JMRI | 1234

DIR. CORTA (Opción sólo para Z21)

Al programar la dirección de la locomotora en las CV se puede elegir la máxima dirección que es considerada como corta para que se corresponda con la establecida en la Z21.

PLATAFORMA

Se puede escoger si la plataforma giratoria está digitalizada con un decodificador compatible con el 7686 de Märklin en la dirección base 209 (Keyboard 14) o 225 (Keyboard 15) o bien con el TurnControl 6915 de Fleischmann en la dirección base 200.

En las versiones Xpressnet y Z21, se puede marcar la opción 'Dir. Roco' para corregir el desplazamiento de 4 direcciones en sistemas Roco al usar la plataforma.

RELOJ (Opción sólo para Z21, Loconet WiFi y Xpressnet WiFi)

Si el Fast Clock esta soportado en la central con la opción Ajustar se puede establecer tanto la hora como el ratio de aceleración (1:1 corresponde con el tiempo real).

En Loconet se puede activar la opción ‘Pulso Sinc.’ para que PacoMouse envie periódicamente el pulso de sincronización para todos los relojes. Solo debe haber un dispositivo del bus Loconet que envíe este pulso.

BLOQUEAR

En caso de que estemos en un Club o dejemos el PacoMouse a un invitado se pueden bloquear algunas opciones para evitar situaciones indeseadas.

El bloqueo de la Selección de Locomotora evita que nuestro invitado pueda escoger otra locomotora por error. También bloquea la opción Dispatch de la versión Loconet.

El bloqueo de Desvíos evita que se puedan cambiar la posición de los desvíos, también bloquea el movimiento de la Plataforma Giratoria.

El bloqueo de Programación de CV evita que se puedan modificar las CV. Es especialmente útil cuando la central no posee una vía de programación separada ya que todas las locomotoras en la vía podrían recibir la misma programación.

ATENCIÓN

La activación de cualquiera de estos bloqueos desactiva la tecla 'STOP' para evitar dejar sin tensión la vía en toda la maqueta del Club.
También desactiva la posible modificación del resto de opciones de Configuración por lo que si se desean cambiar han de desactivarse las tres opciones de bloqueo antes de modificar cualquier otra opción.

JUEGO (Opción sólo para Z21, Loconet WiFi, Xpressnet WiFi y ECoS)

En las versiones ECoS, Loconet WiFi y Z21, ya que hay suficiente espacio de programa, se han incluido unos entretenimientos. El popular juego Snake de los primeros teléfonos móviles, el 3 en raya, el Flappy Bird, el Pong y el Paku Paku.

En el Snake, pulsando el encoder comenzará el juego y con el mismo encoder podremos guiar a la serpiente a encontrar su comida y evitar que se electrocute con la valla. Cuando haya crecido lo suficiente se pasará a otro nivel con velocidad más rápida.

En el 3 en raya jugamos con las | y PacoMouse con las | . Con el encoder movemos el | para seleccionar la
casilla y pulsándolo pondremos nuestra | . PacoMouse tras pensar su jugada pondrá su | , no lo subestimes.
Con cada nuevo tablero hay cambio de jugador inicial.

En el Flappy Bird pulsando el encoder hacemos que vuele más alto, al soltarlo descenderá planeando. El objetivo es pasar por el mayor número de pilares sin chocar con ellos, cuantos más pilares pases más rápido volarás. En la pantalla inicial se indica la puntuación más alta obtenida en esta serie de partidas.

El Paku Paku es una versión del Pacman unidimensional en el que tiene que ir comiendo puntos mientras huye del enemigo, cuando se come el punto grande tiene un tiempo en el que es más poderoso que el enemigo y se lo puede comer. Paku puede huir por un extremo y aparecer en el otro mientras que los enemigos no pueden pasar. Cuando se come todos los puntos se aumenta un nivel y la velocidad. Paku cambia de dirección pulsando el botón del encoder.

En el Pong jugamos contra PacoMouse. Con el encoder movemos la raqueta derecha. Quien llegue a 11 puntos gana.

Snake | 3 en raya | Flappy Bird | Paku Paku | Pong

LISTIN TELEF. (Opción sólo para Loconet)

Lista de las direcciones de accesorios asignadas a las estaciones colaterales y la estación donde está ubicado el PacoMouse para el Dispatch de locomotoras como si fuera un bloqueo telefónico.

Estacion A
Estacion B
Estacion C
Estacion D

Se puede elegir con el encoder entre los números 701 y 799 para cuatro estaciones y la nuestra, o bien dejarla sin asignar (se muestra 7??).

Estacion A

7??

Si nuestra dirección esta sin asignar no podremos transferir trenes desde nuestro mando o recibirlos con este sistema único de PacoMouse de simulación de bloqueo telefónico.

NOTA: No seleccionar los números ya usados por otros accesorios de la maqueta.

## Anexo I: Esquemas

### Esquema Arduino Nano (Interface Loconet)

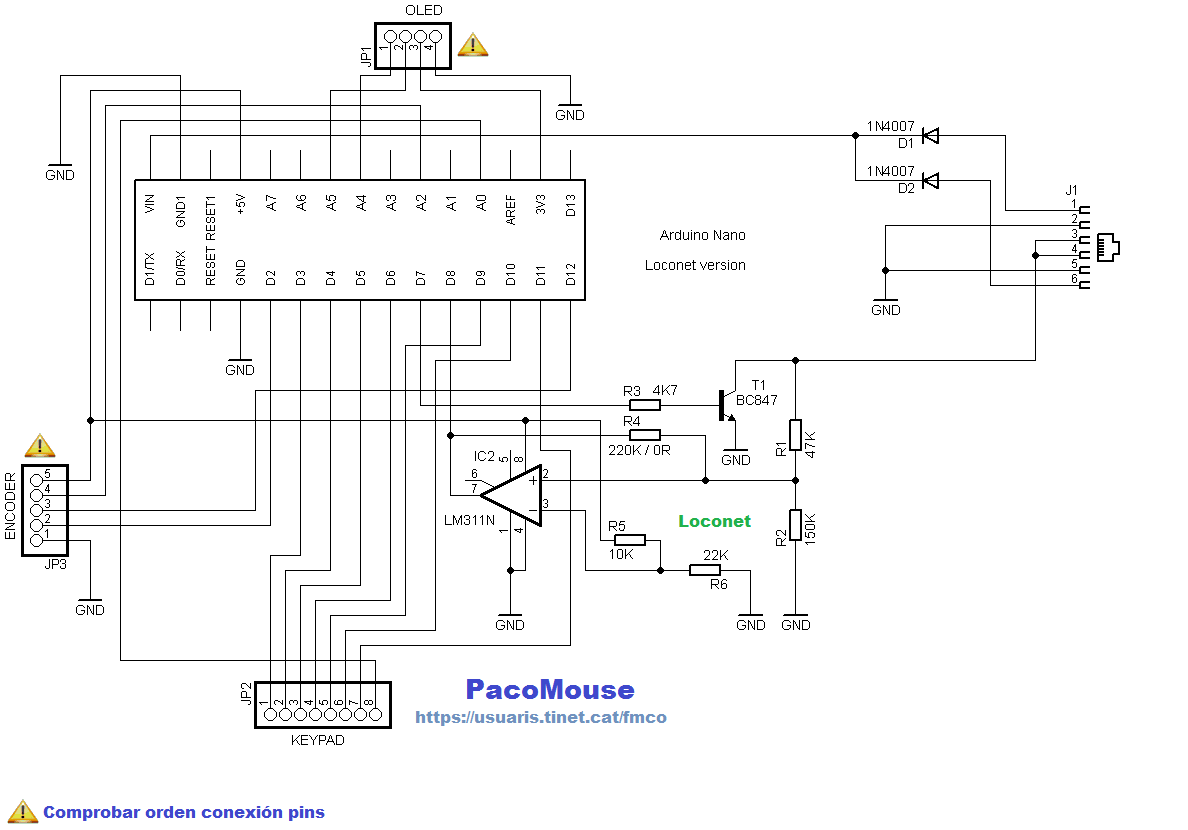
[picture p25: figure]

OLED | Arduino
GND | GND
VCC | 3V3
SCL | A5
SDA | A4
ENCODER | Arduino
GND | GND | GND
S1 | CLK | D12
S2 | DT | D2
Key | SW | A2
5V | + | +5V

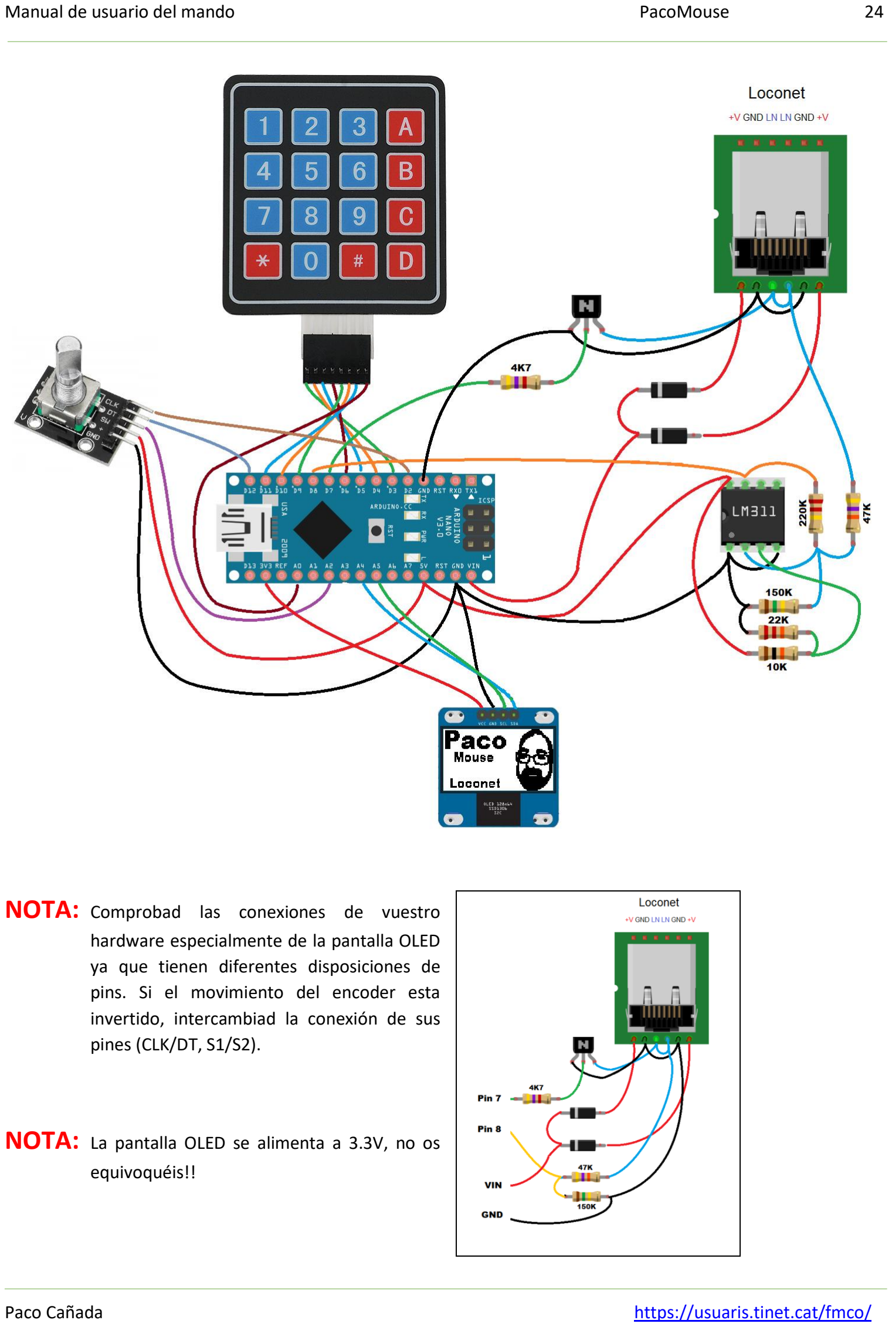
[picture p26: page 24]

NOTA: Comprobad las conexiones de vuestro

hardware especialmente de la pantalla OLED ya que tienen diferentes disposiciones de pins. Si el movimiento del encoder esta invertido, intercambiad la conexión de sus pines (CLK/DT, S1/S2).

NOTA: La pantalla OLED se alimenta a 3.3V, no os

equivoquéis!!

Versión interface Loconet simple

Esquema Arduino Nano (Interface Xpressnet)

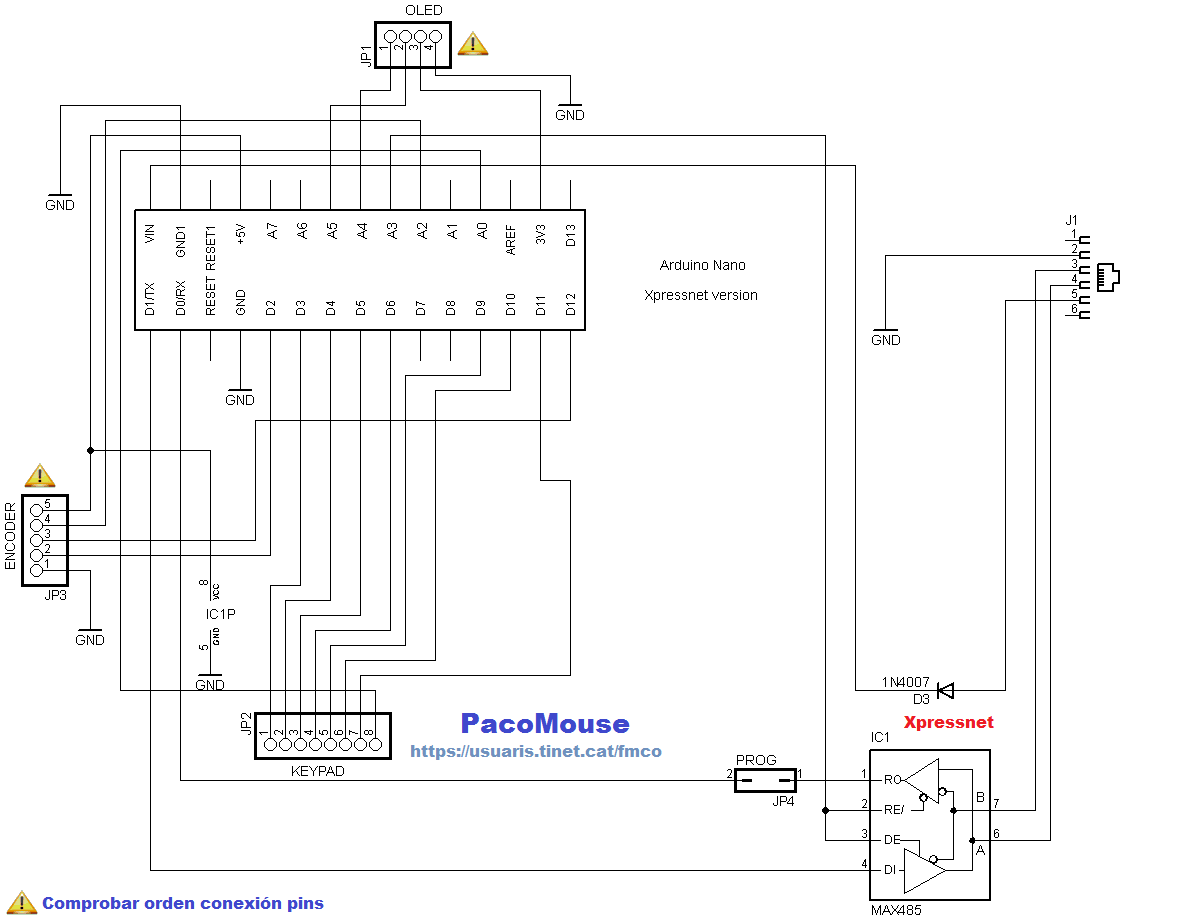
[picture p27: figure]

OLED | Arduino
GND | GND
VCC | 3V3
SCL | A5
SDA | A4
ENCODER | Arduino
GND | GND | GND
S1 | CLK | D12
S2 | DT | D2
Key | SW | A2
5V | + | +5V

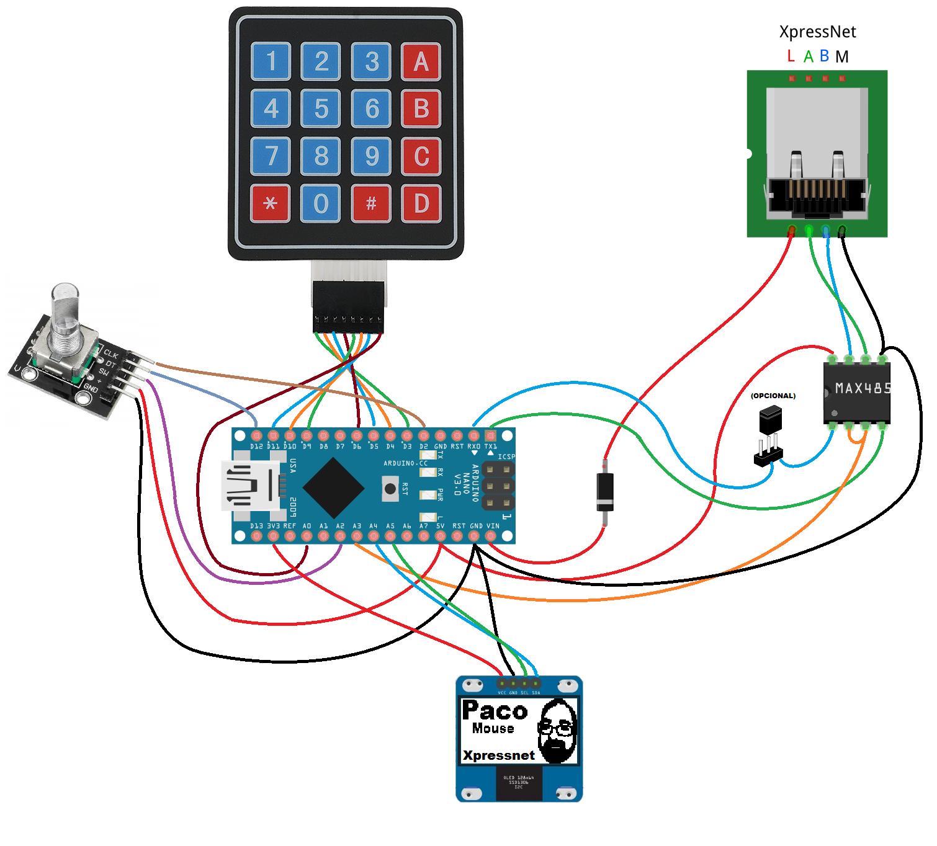
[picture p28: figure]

NOTA: Comprobad las conexiones de vuestro hardware especialmente de la pantalla OLED ya que tienen

diferentes disposiciones de pins. Si el movimiento del encoder esta invertido, intercambiad la conexión de sus pines (CLK/DT, S1/S2).

NOTA: La pantalla OLED se alimenta a 3.3V, no os equivoquéis!!

### Esquema Placa PacoMouse con Arduino Nano (Interface Loconet o Xpressnet)

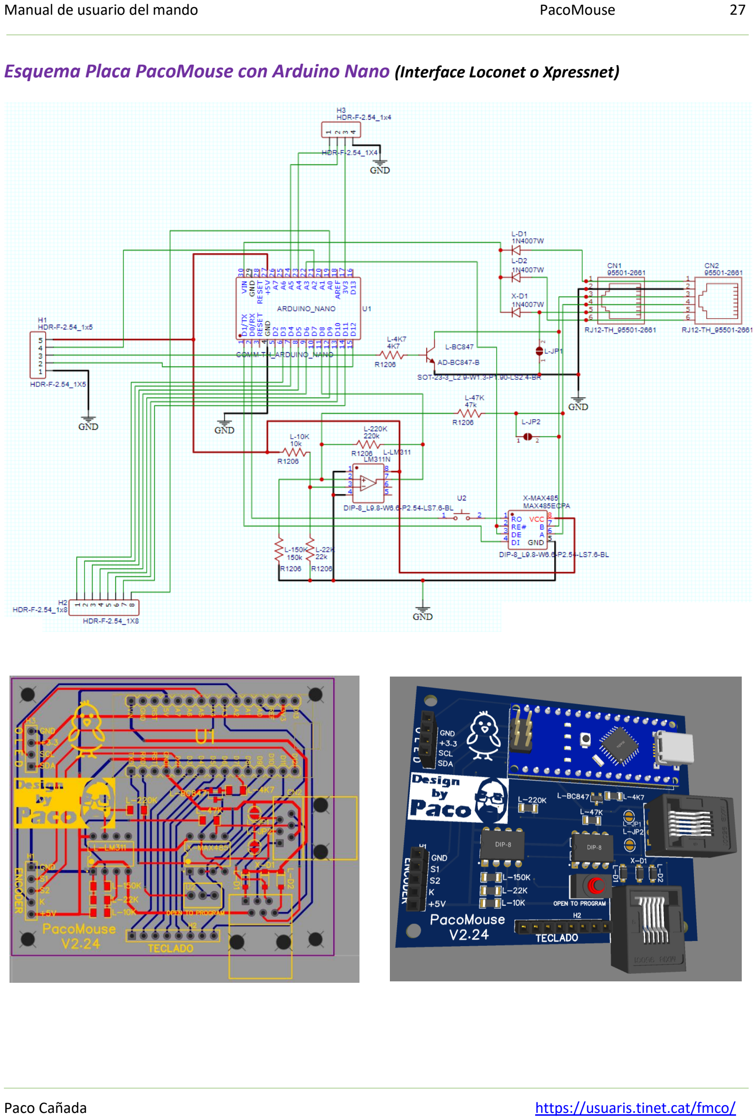
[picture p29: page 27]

### Conexión de componentes

Estas son las conexiones del Arduino Nano con los diferentes elementos por defecto tal como están en el archivo config.h

Arduino Nano | OLED | Teclado Keypad | Teclado Touchpad | Encoder | Observaciones
TX | | | | | Xpressnet: MAX485 pin 1
RX | | | | | Xpressnet: MAX485 pin 4
D2 | | | | S2/DT
D3 | | FILA1
D4 | | FILA2
D5 | | FILA3
D6 | | FILA4
D7 | | | | | Loconet: Resistencia del BC547
D8 | | | | | Loconet: LM311 pin 7
D9 | | COL1 | SDO
D10 | | COL2 | SCL
D11 | | COL3 | GND | | Touchpad: Opción POWER_TOUCH
D12 | | | | S1/CLK
D13
A0 | | COL4 | VCC | | Teclado 3x4: Sin conexión Touchpad: Opción POWER_TOUCH
A1 | | | | | Interruptor dirección opcional
A2 | | | | Key/SW
A3 | | | | | Xpressnet: MAX485 pin 2 y 3
A4 | SDA
A5 | SCL
5V | | | | VCC
3V3 | VDD
GND | GND | | | GND

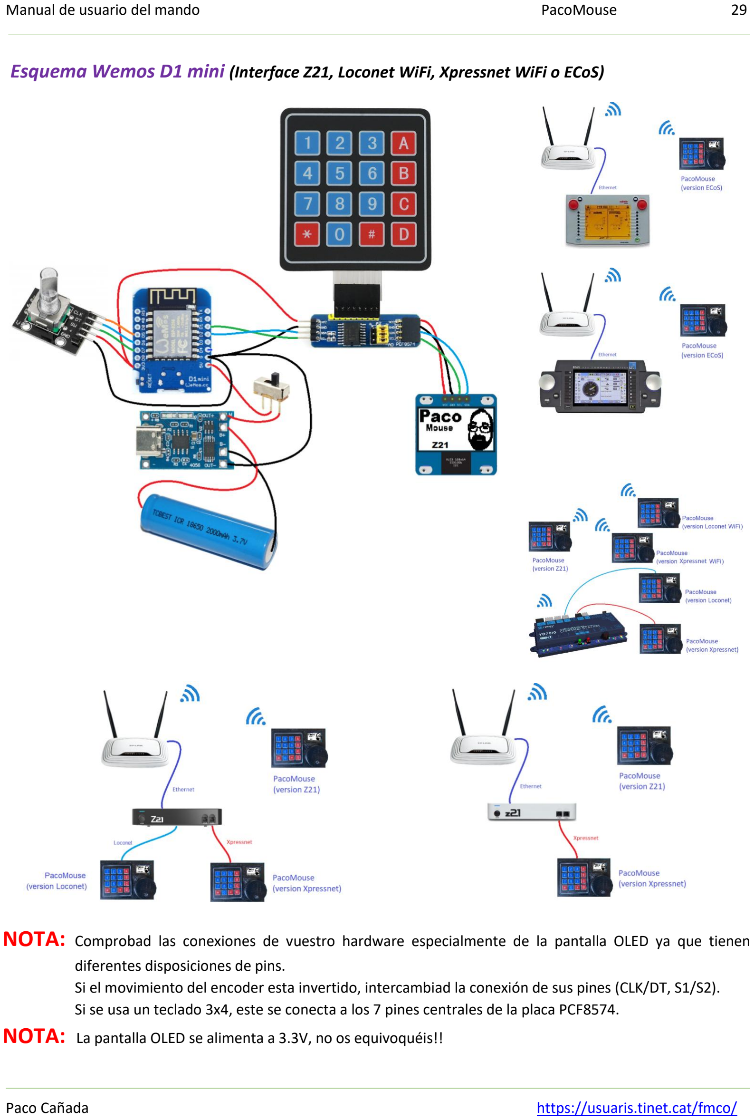
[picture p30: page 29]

Esquema Wemos D1 mini (Interface Z21, Loconet WiFi, Xpressnet WiFi o ECoS)

NOTA: Comprobad las conexiones de vuestro hardware especialmente de la pantalla OLED ya que tienen

diferentes disposiciones de pins.
Si el movimiento del encoder esta invertido, intercambiad la conexión de sus pines (CLK/DT, S1/S2). Si se usa un teclado 3x4, este se conecta a los 7 pines centrales de la placa PCF8574.
NOTA: La pantalla OLED se alimenta a 3.3V, no os equivoquéis!!

Estas son las conexiones del Wemos D1 mini con los diferentes elementos por defecto tal como están en el archivo config.h

Wemos D1 mini | PCF8574 | OLED | Encoder | Teclado Keypad | Teclado Touchpad | Batería / Cargador | Observaciones

TX
RX
D0
D1 | SCL | SCL
D2 | SDA | SDA
D3 | | | | | SCL
D4 | | | | | SDO
D5 | | | S2/DT
D6 | | | S1/CLK
D7 | | | Key/SW
D8
A0 | | | | | | | Interruptor dirección opcional
5V | | | | | | Positivo +
3V3 | VCC | VDD | VCC | | VCC
GND | GND | GND | GND | | GND | Masa
| INT
| 7 | | | FILA1
| 6 | | | FILA2
| 5 | | | FILA3
| 4 | | | FILA4
| 3 | | | COL1
| 2 | | | COL2
| 1 | | | COL3
| 0 | | | COL4 | | | Teclado 3x4: Sin conexión
OLED | Wemos D1 mini
GND | GND
VCC | 3V3
SCL | D1
SDA | D2
ENCODER | Wemos D1 mini
GND | GND | GND
S1 | CLK | D6
S2 | DT | D5
Key | SW | D7
5V | + | 3V3

## Anexo II: Lista de componentes

## Versión PacoMouse

Loconet* | Xpressnet* | WiFi*
Arduino Nano/Pro mini (ATmega328) | X | X
Wemos D1 mini (ESP8266) | | | X
Pantalla OLED: SSD1306 (0.96") SH1106 (1.3") SSD1309 (1.54/2.42”) **** | X* | X* | X*
Teclado: Matricial 3x4 Matricial 4x4 Touchpad TTP229 | X* | X* | X*
PCF8574 | | | X*
Encoder EC11 con pulsador | X | X | X
Transistor: BC547 | X
Resistencias: 150K/47K/4K7 22K/10K/220K | X X**
Diodo: 1N4007 | X (x2) | X
LM311 | X**
RJ12 | X | X
MAX485 | | X
Puente/Jumper | | X***
Cargador batería TP4056 | | | X
Batería 18650 | | | X
Interruptor | | | X
(*) | En el archivo config.h podemos modificar varias opciones de acuerdo al hardware
| que se monte.
(**) | Componentes adicionales para un interface clásico Loconet.
(***) | Para programar el Arduino sin tener que desmontarlo o desmontar el MAX485.
(****) | El consumo de esta pantalla OLED es bastante elevado. (ver Anexo IV)

### Placa PacoMouse

## Versión PacoMouse

Loconet* | Xpressnet* | Serigrafía
Arduino Nano (ATmega328) | X | X | U1
Pantalla OLED: SSD1306 (0.96") SH1106 (1.3") SSD1309 (1.54”/2.42”) *** | X* | X* | H3
Teclado: Matricial 3x4 Matricial 4x4 Touchpad TTP229 | X* | X* | H2
Encoder EC11 con pulsador | X | X | H1
Transistor: BC847 | X | | L-BC847
Resistencias: 150K 22K 10K 220K 4K7 47K | X X X X X X | | L-150K L-22K L-10K L-220K L-4K7 L-47K
Diodo: 1N4007 1N4007 1N4007 | X X | X | L-D1 L-D2 X-D1
LM311 | X | | L-LM311
RJ12 | X | X | CN1
MAX485 | | X | X-MAX485
Puente/Jumper JP1 JP2 U2 | X X | X** | L-JP1 L-JP2 X-H3
(*) | En el archivo config.h podemos modificar varias opciones de acuerdo al hardware
que se monte.
(**) | Para programar el Arduino sin tener que desmontarlo o desmontar el MAX485.
(***) | El consumo de esta pantalla OLED es bastante elevado. (ver Anexo IV)
NOTA: | La placa permite el montaje tanto de la versión Loconet como de la Xpressnet. Monte sólo
los componentes necesarios para la versión escogida.

## Anexo III: Programación con Arduino IDE

### Programa

Se puede usar tanto en un Arduino Nano como un Arduino Nano o un Arduino Pro Mini.

Desde el mismo Arduino IDE (https://www.arduino.cc/en/Main/Software) se carga el programa en la placa Arduino, a través de la conexión USB del mismo.

Previamente tenemos que instalar las librerías SSD1306Ascii.h (v1.3.5) y Keypad.h (v3.1.1) con la opción Programa -> Incluir Librería -> Gestionar Librerías

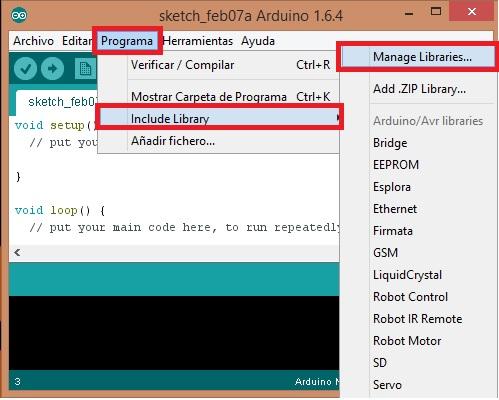
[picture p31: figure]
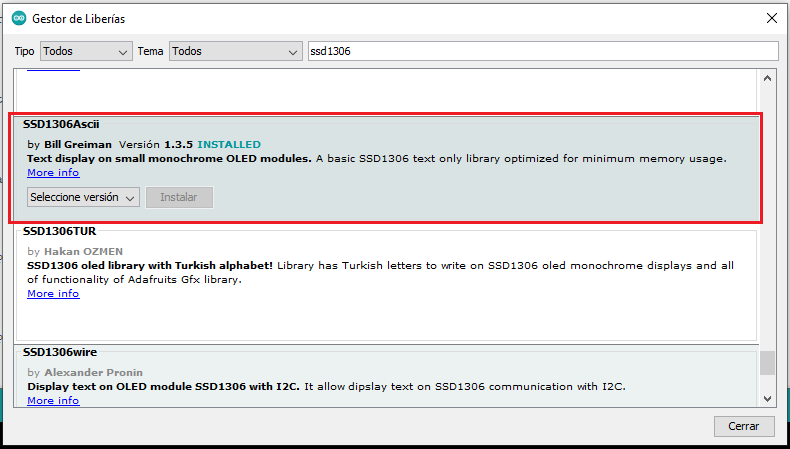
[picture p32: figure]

Para la versiones Z21, Loconet WiFi y ECoS es necesario instalar adicionalmente la librería Keypad_I2C.h (v3.0.0) descargando el archivo .zip desde https://github.com/joeyoung/arduino_keypads y luego usando la opción Programa -> Incluir Librería -> Añadir biblioteca .ZIP...

También es necesario instalar el Arduino Core para el chip ESP8266. En | Archivo > Preferencias en donde
pone Gestor | de | URLs | Adicionales | de | Tarjetas copiamos | el | siguiente | enlace:
http://arduino.esp8266.com/stable/package_esp8266com_index.json

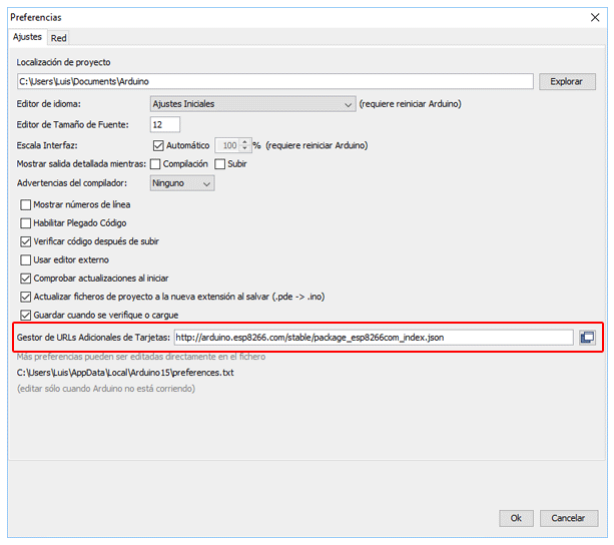
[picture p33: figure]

Ir a Herramientas > Placa: “Arduino UNO” > Gestor de Tarjetas…

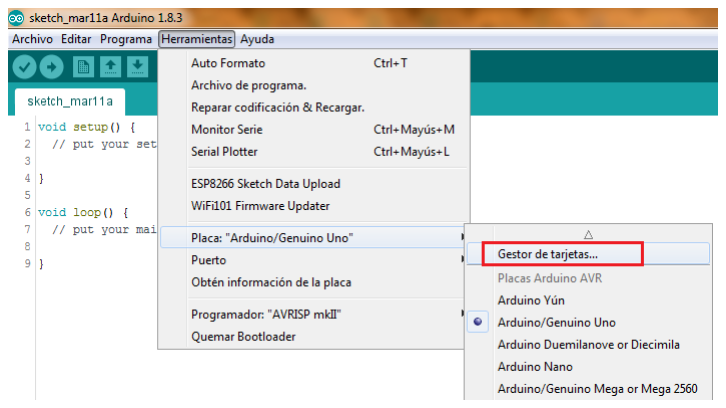
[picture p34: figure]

En el gestor de tarjetas buscar “esp” e instalar el ESP8266 by ESP8266 Community (v3.0.2)

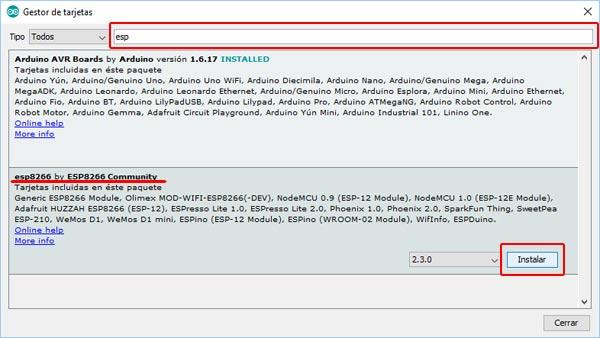
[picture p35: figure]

### Configuración

Hay una serie de configuraciones que se pueden escoger cuando se programa el PacoMouse desde Arduino IDE en función de lo que tengamos montado.

En el archivo config.h podemos modificar varias opciones para adaptar el código a nuestra versión de PacoMouse que hayamos montado.

ATENCIÓN: Modifique únicamente este archivo (config.h) y sólo en la sección de código que empieza con:

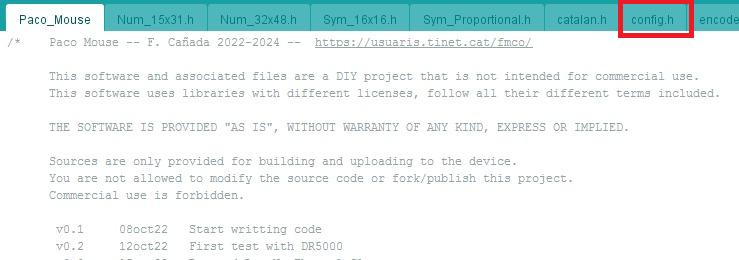
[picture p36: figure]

//////////////////////////////////////////////////////////// // ***** USER OPTIONS ***** ////////////////////////////////////////////////////////////
y finaliza con:

//////////////////////////////////////////////////////////// // ***** END OF USER OPTIONS ***** ////////////////////////////////////////////////////////////

A continuación se indican para cada opción los valores que se pueden modificar en color rojo y los posibles valores en color violeta:

NOTA: | Para descomentar una línea, eliminar los caracteres // al inicio de la misma.

Cuando haya adaptado las opciones a su PacoMouse ya podrá pasar al capítulo siguiente para programar su Arduino.

Este software y los archivos asociados son un proyecto de bricolaje que no está diseñado para uso comercial.

EL SOFTWARE SE PROPORCIONA "TAL CUAL", SIN GARANTÍA DE NINGÚN TIPO, EXPRESA O IMPLÍCITA.

Las fuentes solo se proporcionan para compilar y cargar en el dispositivo.
No se permite modificar ni derivar/publicar el código fuente de este proyecto.

EL USO COMERCIAL ESTÁ PROHIBIDO.

This software and associated files are a DIY project that is not intended for commercial use.

THE SOFTWARE IS PROVIDED "AS IS", WITHOUT WARRANTY OF ANY KIND, EXPRESS OR IMPLIED.

Sources are only provided for building and uploading to the device.
You are not allowed to modify or fork/publish the source code of this project.

COMMERCIAL USE IS FORBIDDEN.

### Opciones comunes

IDIOMA

Se puede escoger el idioma en que queremos que aparezcan los diferentes menús:

// Seleccione el idioma de los menús: ENGLISH / SPANISH / CATALAN / PORTUGUESE / GERMAN / FRENCH / ITALIAN / NEDERLANDS / CZECH
#define LANGUAGE | SPANISH

SENSIBILIDAD ENCODER

Se puede escoger una sensibilidad mayor en el movimiento del encoder para cuando se tienen que alcanzar valores altos (como en la velocidad o selección del contraste) aunque esto puede dificultar el control preciso cuando nos movemos por los menús.

// Descomentar la siguiente linea para mayor sensibilidad del encoder. No recomendado
//#define SENSITIVE | 1

LOCOMOTORAS EN EL STACK

PacoMouse guarda las últimas locomotoras seleccionadas durante una sesión para acceder rápidamente a ellas sin tener que introducir en el teclado su número, aquí podemos seleccionar cuantas podrá guardar en su stack. En la versión ECoS se ha de escoger un número suficiente para albergar todas las locomotoras definidas en la ECoS.

// Max. locomotoras guardadas en stack
#define LOCOS_IN_STACK | 24

PASO ACTUAL DE VELOCIDAD

Se puede seleccionar si se desea mostrar el paso actual al lado de la barra de velocidad (izquierda o derecha) o no.

// Mostrar pasos de velocidad: LEFT/RIGHT/NONE
#define SHOW_STEPS | LEFT

PRESENTACIÓN DE FUNCIONES

Se puede seleccionar si se desea mostrar las funciones a un tamaño grande o pequeño:

// Seleccione tamaño de las funciones a mostrar: BIG/SMALL
#define FUNC_SIZE | BIG

ICONO DE DESVIO

Se puede seleccionar el tipo de icono que se muestra para los desvíos:

ONLY_TURN | TURN_SIGNAL | BUTTON_IB
// Selecciona iconos estado desvio: ONLY_TURN/TURN_SIGNAL/BUTTON_IB
#define TURNOUT_ICON | ONLY_TURN

### Opciones de pantalla OLED

DIRECCION DE LA PANTALLA OLED

PacoMouse muestra la información en una pantalla OLED que se conecta por el bus I2C. Estas pantallas tienen una dirección de bus (0x3C o bien 0x3D) que en algunas se puede modificar cambiando una resistencia de lugar.

NOTA: En algunas pantallas la serigrafía indica una dirección con un valor diferente al que hay que poner en config.h (vea imagen)

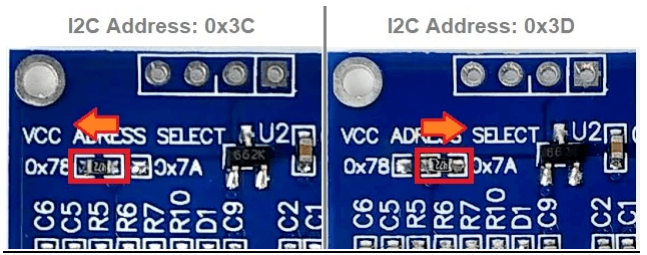
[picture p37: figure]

// Direccion I2C del display OLED - 0x3D: Adafruit I2C OLED, 0x3C: Clone I2C OLED)
#define I2C_ADDRESS_OLED | 0x3C | // Pantalla principal

TIPO DE PANTALLA OLED

Las pantallas OLED usan un controlador específico para manejar la pantalla, este suele ser el SSD1306 en pantallas de 0.96" (tipo Adafruit), el SH1106 en las de 1.3" o el SSD1309 en las de 1.54” y 2.42”. La librería SSD1306Ascii.h soporta los dos primeros controladores de forma nativa pero hemos de indicar en el config.h que tipo lleva nuestra pantalla para una correcta visualización:

// Seleccione el chip controlador del display 128x64 OLED: | SSD1306/SH1106/SSD1309
#define OLED_CHIP | SSD1306

### Opciones de interface

INTERFACE

Dependiendo de la versión de interface que hayamos montado en PacoMouse el programa se compilará para usar uno u otro tipo de interface y procesador. Si hemos montado el interface Loconet o el Xpressnet en PacoMouse debemos usar un Arduino Nano (Uno o Pro Mini), si por el contrario hemos montado la versión WiFi para ECoS, Loconet, Xpressnet o Z21 debemos usar un Wemos D1 mini con el ESP8266. Seleccionar el tipo de versión que hemos montado, Xpressnet (XNET), Loconet (LNET), Z21 o ECOS:

// Selecione la version hardware de: XNET/LNET/Z21/ECOS
#define HW_VERSION | ECOS

### Opciones de teclado

TIPO TECLADO (3x4 o 4x4)

Podemos montar un teclado de 3x4 o uno de 4x4, esta es la distribución de las teclas:

1 | 2 | 3 | 1 | 2 | 3 | STOP
4 | 5 | 6 | 4 | 5 | 6 | LOCO
7 | 8 | 9 | 7 | 8 | 9 |
MENU | 0 | ENTER | MENU | 0 | ENTER |

En el teclado de 3x4 no están disponibles algunas teclas como la de 'STOP' que al pulsarla deja sin tensión las vías por lo que es más adecuado instalarlo si PacoMouse se va a usar como mando adicional o cuando la central tiene su propio botón de STOP.

// Descomentar la siguiente linea si se usa un teclado 4x4
//#define USE_KEYPAD_4x4 | | 1

EXPANSOR I2C PARA TECLADO

El ESP8266 (Wemos D1 mini) no dispone de suficientes pines para controlar el teclado, OLED y encoder por lo que se necesita un expansor I2C con el chip PCF8574 para conectar el teclado. Es necesario indicar la dirección de bus I2C según se haya configurado los puentes en la placa expansora.

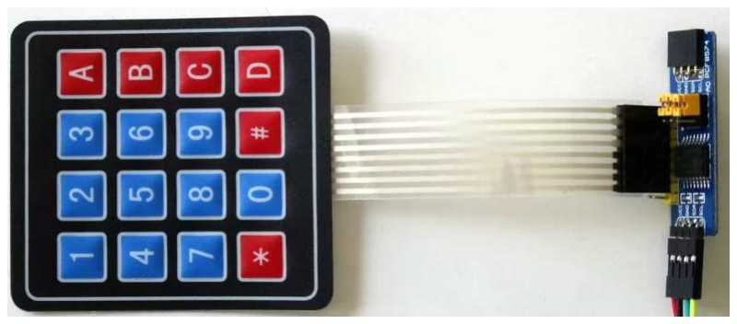
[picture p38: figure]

// Direccion I2C del PCF8574 para el keypad (0x20..0x27)
#define I2C_ADDRESS_KEYPAD | 0x20 | // PCF8574 keypad

TECLADO TÁCTIL

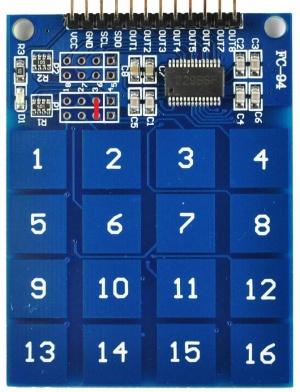
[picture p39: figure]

En lugar de un teclado matricial (keypad) es posible conectar a PacoMouse un teclado táctil (touchpad) con el chip TTP229BSF como el de la figura:

Solo se utilizan las conexiones VCC, GND, SCL y SDO.

IMPORTANTE:

La alimentación VCC se conecta a 5V para Arduino Nano y a 3V3 para Wemos D1 mini.

Soldar un puente de hilo en TP2 como se indica en la imagen (en rojo)

En las versiones con Wemos D1 mini ya no es necesario montar el PCF8574.

### Conexión

Conecte el teclado táctil de la siguiente manera:

TTP229 | Arduino Nano | Wemos D1 mini
VCC | 5V | 3V3
GND | GND | GND
SCL | 10 | D3
SDO | 9 | D4

Si usa la placa PacoMouse es posible alimentar el TTP229 desde los pines del conector de teclado en este caso conéctelos así y active la opción POWER_TOUCH en el archivo config.h:

TTP229 | Arduino Nano (Placa PacoMouse)
VCC | A0
GND | 11
SCL | 10
SDO | 9

No se olvide de soldar un puente de hilo en TP2 ya que sino sólo se reconocerán 8 teclas:

### Configuración

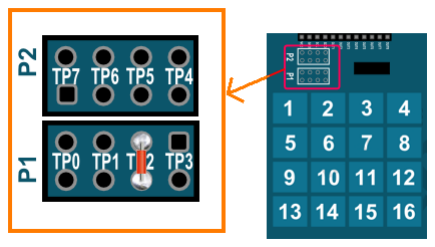
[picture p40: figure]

En el archivo config.h seleccione TOUCHPAD como tipo de teclado:

// Seleccione el tipo de teclado: KEYPAD/TOUCHPAD
#define KEYPAD_TYPE | TOUCHPAD

Aunque tiene menos sensibilidad también se puede usar el teclado táctil por la parte de atrás, descomente la siguiente línea en config.h para esta disposición o déjela comentada para uso frontal:

// Descomentar la siguiente linea si se usa el touchpad TTP229 por detrás:
//#define REAR_TOUCH

1
Si usa la placa PacoMouse y ha conectado la alimentación del TTP229 a los pines del conector de teclado descomente la línea en config.h:

// Descomentar la siguiente linea para alimentar el touchpad desde pines (solo placa PacoMouse) //#define POWER_TOUCH

### Opciones de cambio de dirección

BOTÓN DEL ENCODER

Si se pulsa el botón del encoder estando la locomotora en marcha se detendrá la locomotora. Con la locomotora detenida pulsando el botón del encoder se cambia el sentido de marcha.

INTERRUPTOR DE DIRECCIÓN

Mediante el interruptor de tres posiciones (ON-OFF-ON) podemos seleccionar la dirección de marcha al situarlo en una de las posiciones de los extremos. Moviendo el interruptor a la posición central o pulsando el botón del encoder estando la locomotora en marcha se detendrá la locomotora. Estando el interruptor en la posición central el encoder no cambiará la velocidad.

### Conexión

En caso de usar la opción de interruptor de dirección necesitará un interruptor de tres oposiciones estables (ON-OFF-ON) y dos resistencias de 10K. Conéctelo de la siguiente manera:

SWITCH | Arduino Nano | Wemos D1 mini
VCC | 5V | 3V3
DIR | A1 | A0
GND | GND | GND

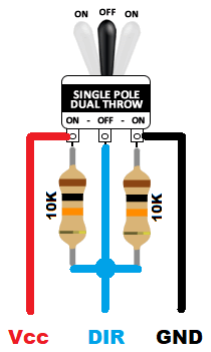
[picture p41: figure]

### Configuración

En el archivo config.h seleccione el tipo de control de dirección que desea usar:

BUTTON_ENC para usar el botón del encoder como cambio de dirección.

SWITCH_3P para usar el interruptor de tres posiciones como cambio de dirección.

// Selecion tipo cambio direccion - Select change direction type: BUTTON_ENC/SWITCH_3P
#define CHANGE_DIR | SWITCH_3P

### Programación del Arduino

Una vez hemos abierto el sketch y actualizado las opciones en el archivo config.h según nuestras preferencias y hardware, en el Arduino IDE comprobamos que hemos seleccionado la placa Arduino que tenemos y el puerto al que está conectada. Quizás necesitemos instalar algún driver previamente para que nos aparezca listado el puerto al que está conectado.

Versión
Loconet / Xpressnet

Versión
Z21 / Loconet WiFi / Xpressnet WiFi /ECoS

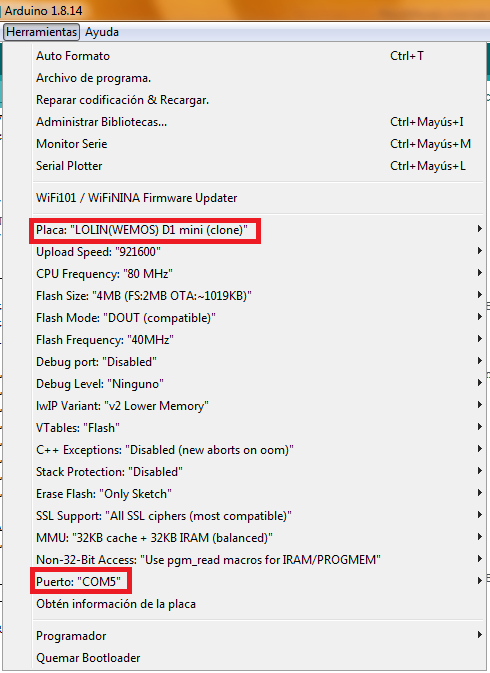
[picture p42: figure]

Dependiendo de la placa Arduino Nano que useis hay que escoger entre ‘ATmega328P’ y ‘ATmega328P (Old Bootloader)’ al programar.

Para cargar el programa pulsaremos sobre el botón de ‘Subir’ programa.

Tras compilar el programa, si todo va bien nos informará de que ha sido subido.

## Anexo IV: Programa de prueba del hardware

Se ha incluido un pequeño programa de test como ayuda para la configuración y detección de problemas del montaje de PacoMouse en la carpeta PacoMouse_HW_Test.

Después de instalar las librerías en el Arduino IDE indicadas en el anexo anterior, suba el programa PacoMouse_HW_Test.ino a su Arduino Nano (con la versión Xpressnet, no colocar el jumper) o Wemos D1, y sin tocar nada más y con sólo el cable USB conectado abra el Monitor Serie del Arduino IDE seleccionado 115200 baudios, aparecerá el siguiente mensaje:

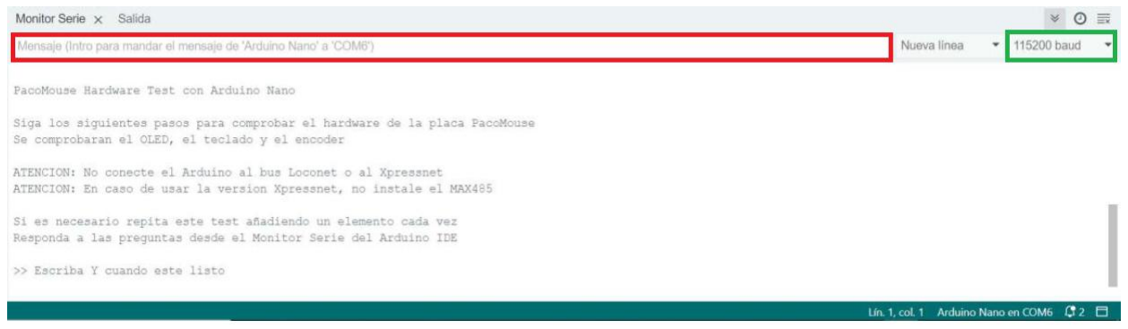
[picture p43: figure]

Ahora siga las instrucciones del Monitor Serie respondiendo Y o N en el recuadro rojo y siga los pasos que se indican para comprobar su montaje.

Se irá comprobando el montaje correcto de la pantalla OLED, el teclado y el encoder y le irá preguntando sobre el resultado de las pruebas.

Visualización correcta (responda Y) | Visualización incorrecta (responda N)

Finalmente le mostrará un resumen de los test e indicaciones para configurar adecuadamente el archivo config.h para su hardware. Ahora ya puede cambiar las diferentes opciones en el config.h y subir el programa de PacoMouse según se explica en el anexo anterior.

Si es la primera vez que programa su PacoMouse o tiene instalada una versión anterior a la v0.28 es conveniente que responda Y a la pregunta de si quiere restaurar la EEPROM a los valores por defecto.

Si es necesario, cambie en las opciones de usuario el tipo de teclado que ha instalado KEYPAD o TOUCHPAD y del idioma ENGLISH o SPANISH antes de subir el programa de test:

////////////////////////////////////////////////////////////
// ***** USER OPTIONS ***** ////////////////////////////////////////////////////////////

// Seleccione el tipo de teclado - Select the type of keypad: KEYPAD/TOUCHPAD
#define KEYPAD_TYPE | KEYPAD

// Seleccione el idioma de los menus - Select menu language: ENGLISH/SPANISH
#define LANGUAGE | SPANISH

## Anexo V: Ejemplos de automatización

PacoMouse puede realizar acciones automáticamente desde el menú Automatización, aquí hay algunos ejemplos:

ARRANQUE DE LOCOMOTORA DE VAPOR

Las locomotoras de vapor tienen todo un proceso para arrancar lo que nos obliga a ir activando funciones con cierto retraso entre ellas para que quede un efecto realista, en este ejemplo se enciende la luz de la locomotora (F0), después de 2 segundos se activan el sonido (F1) y las paladas (F8), tras 6 segundos se oye el silbato (F2) durante 2 segundos y luego se detienen las paladas y el silbato, y la locomotora arranca al 20% de velocidad. Si no
se incluye la acción | se podrá usar para cualquier locomotora que tengamos seleccionada en PacoMouse.
LocoVapor | 0 | 2.0s | 1 | 8 | 6.0s | 2 | 2.0s
| 2 | 8 | 20%

RUTA DE ESTACIÓN A ESTACIÓN

Para establecer una ruta se han de mover los desvíos a la posición correcta, hacerlo desde el menú de desvíos nos obliga a recordar los números de cada desvío para moverlos. Lo podemos automatizar y además darle un nombre significativo para facilitar su uso. Vamos a establecer la ruta de la estación 1 vía 2 a la estación 2 vía 1 moviendo los desvíos de salida 5 y 7 de la estación 1 y el desvío 21 entrada a la estación 2, finalmente pondremos la señal 10 de salida en verde después de un tiempo para simular el tiempo necesario para que los guardagujas hagan su trabajo.

E1V2->E2V1 | 5 | 7 | 21 | 3.0s | 10

FUNCION LANZADERA CON PARADA INTERMEDIA

Aunque en el menú Lanzadera tenemos esta opción entre dos puntos muy bien implementada echamos de menos la función de realizar una o varias paradas intermedias, con el menú Automatización lo podemos implementar:

Lanzadera | 65.1 | 0% | 10.0s | 10.0s | 50% | 65.2
0% | 6.0s | 50% | 65.3 | 0% | 10.0s
10.0s | 50% | 65.2 | 0% | 6.0s | 50%

Para iniciar la automatización dirigiremos la locomotora a la estación con el contacto 65.1 cuando esté funcionando la automatización, al dar ocupación automáticamente se detendrá, esperará 10 segundos cambiará de sentido y tras 10 segundos se dirigirá a la estación intermedia con el contacto 65.2, cuando llegue detendrá la locomotora y tras 6 segundos arrancará de nuevo hacia la estación con el contacto 65.3, allí parará y tras 10 segundos cambiará de sentido y tras 10 segundos se dirigirá de nuevo a la estación intermedia donde se detendrá 6 segundos antes de continuar, luego la secuencia se reiniciará de nuevo así que cuando llegue a la primera estación, se repetirá la secuencia.

Podemos ampliar el número de paradas intermedias añadiendo acciones, incluso cambiando algún desvío para cambiar la ruta, esto lleva a tener automatizaciones muy largas aunque también se puede realizar con automatizaciones más cortas ya que como hemos visto se repiten acciones.

Aquí tenemos dos paradas intermedias y dos paradas de fin de línea, cuando se llega a una parada de final de línea se ejecutan el frenado, cambio de sentido y arranque, y al llegar a una parada intermedia se detiene durante un tiempo. También se establece la ruta para pasar una vez por la parada intermedia con el contacto 65.2 en un sentido y por la parada intermedia con el contacto 65.4 en el otro sentido.

FinalLinea | 0% | 10.0s | | 10.0s | 50%
EstMedio | 0% | 6.0s | 50%
Lanzadera | 65.1 | FinalLinea | 1 | 2 | 65.2 | EstMedio | 65.3
| FinalLinea | 1 | 2 | 65.4 | EstMedio

Cuando se arranca una automatización dentro de otra esta se ejecuta de forma independiente por lo que no se espera a que finalice, así que en este ejemplo cuando se active el contacto 65.1 se verá que enseguida se mueven los desvíos 1 y 2 por lo que si no es el efecto deseado puede incluir un tiempo de espera antes de mover los desvíos.

También podemos usar conjuntamente el menú Lanzadera con una acción para detener la locomotora en una estación intermedia, esto tiene la ventaja de que podemos hacer que no pare en la estación intermedia simplemente parando la automatización.

StopMedio | 65.2 | 0% | 6.0s | 50% | 4.0s

El tiempo después de arrancar es necesario añadirlo para que el tren tenga tiempo de salir del contacto de la estación.

## Anexo VI: Consejos

CONFIGURACIÓN Y PRUEBA DEL HARDWARE

Se ha incluido un pequeño programa de test como ayuda para la configuración y detección de problemas del montaje de PacoMouse. Suba el programa PacoMouse_HW_Test.ino a su Arduino Nano o Wemos D1, abra el Monitor Serie del Arduino IDE seleccionado 115200 baudios (con la versión Xpressnet, no colocar el jumper) y siga las instrucciones del Monitor Serie para comprobar su montaje.

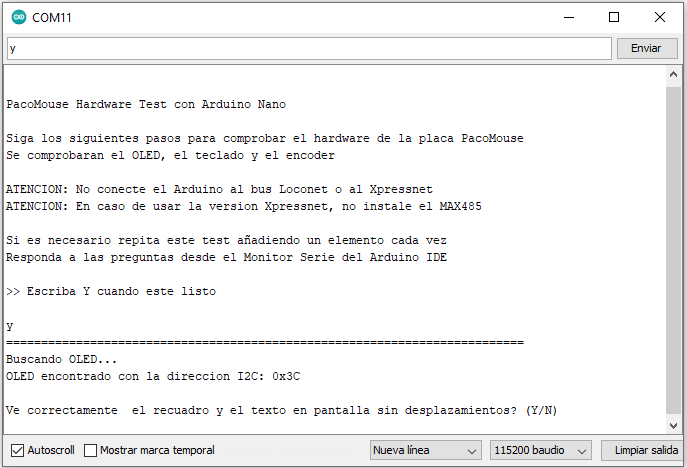
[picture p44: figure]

AL CONECTAR POR PRIMERA VEZ

PacoMouse guarda las diferentes opciones escogidas por el usuario en la memoria EEPROM del controlador. La primera vez que se conecte PacoMouse la memoria EEPROM contendrá valores indeterminados por lo que es posible que algunas opciones no estén disponibles o no sean las preferidas por el usuario. Para solucionarlo pulse la tecla 'MENU' ('*' en el teclado) y seleccione Configuración, adapte las diferentes opciones según sus necesidades. También puede subir el programa de test PacoMouse_HW_Test.ino y seleccionar restaurar la memoria EEPROM a valores por defecto.

CONSUMOS DE LA PANTALLA OLED

Las pantallas OLED usan un controlador específico para manejar la pantalla, este suele ser el SSD1306 en pantallas de 0.96" (tipo Adafruit), el SH1106 en las de 1.3" o el SSD1309 en las de 1.54” y 2.42”. A mayor tamaño, mayor consumo, lo que puede hacer que el bus empleado (Loconet/Xpressnet) no asuma ese consumo para varios mandos por lo que se tendría que prever la conexión en conectores autoalimentados para el bus. En las versiones Z21 y ECoS impacta directamente en la duración de la batería. Bajando el contraste se reduce algo el consumo.

Tipo pantalla | Consumo medio (Contraste: 20) | Consumo medio (Contraste: 100) | Consumo máximo
SSD1306 (0.96") | 4 mA | 5 mA | 15 mA
SH1106 (1.3") | 6 mA | 8 mA | 24 mA
SSD1309 (1.54”) | 18 mA | 26 mA | 75 mA
SSD1309 (2.42”) | 28 mA | 35 mA | 104 mA

ENCODER

Los encoder de bajo precio suelen ser bastante erráticos, el mejor es el modelo que ya incorpora resistencias y condensadores para evitar los rebotes. Se puede mejorar aún más su funcionamiento añadiendo un par de condensadores de 100nF directamente en los pines del encoder. (Entre GND y la salida)

IDIOMA

Si entre las opciones de idioma en el archivo config.h de PacoMouse no aparece el suyo o contiene errores puede usar uno de los existentes como plantilla para adaptarlo. Cada idioma tiene un archivo con extensión .h donde se encuentran todos los textos que se pueden mostrar. Tenga en cuenta que se usa la fuente Arial_bold_14 de la librería SSD1306Ascii por lo que solo están disponibles los caracteres ASCII del 32 al 127. Cambie únicamente los textos entre “ y no sobrepase la longitud máxima de 14 caracteres. Envíe una copia a Paco (https://usuaris.tinet.cat/fmco) para su inclusión en una nueva versión.

FAST CLOCK

El Fast Clock se muestra si esta activado en la central. En la versión Xpressnet sólo esta soportado si se conecta a una LZV200 v4 o a la Z21 con FW1.43. En la versión Z21 sólo cuando se conecta a una Z21 con FW1.43. En la versión Loconet se muestra si la central soporta el Fast Clock en el slot 123 (Intellibox II, DR5000, etc.). En la versión ECoS no está soportado.

ESTADO ACCESORIOS DEL LISTIN TELEFONICO

La central Fleischmann Twin Center v1.100 no guarda el estado de los accesorios a no ser que estén dados de alta por lo que el funcionamiento del listín telefónico del menú Dispatch puede verse afectado. Hay que dar de alta todos los números del listín telefónico de cada PacoMouse. Para ello entre en la configuración de la Twin Center pulsando menu y luego mode, busque con la flecha la opción Acess.Setting, entre en la opción y seleccione Virtual Addrs y de de alta todos los accesorios del listín telefónico.

Por ejemplo, para el número 701:

VAdd DAdd Out DF

.701 | 175 | 2 | D

DAdd = VAdd / 4

Out = VAdd - (DAdd * 4) + 1

RECIBIR LLAMADAS DESDE TWIN CENTER

La central Fleischmann Twin Center v1.100 no guarda el estado de los accesorios ni se muestra el cambio en la pantalla sino están dados de alta en la central por lo que no se puede llamar de PacoMouse a TwinCenter o a otro PacoMouse con la opción de llamadas del menú Dispatch.

No obstante se podrían recibir llamadas desde TwinCenter pero de forma manual, es un proceso a ciegas ya que no hay notificación de que se haya aceptado o rechazado la llamada.

Teléfono PacoMouse: | 701
Teléfono Estación A: | 702

Twin Center controla loco 276.

Transferir locomotora 276 de Twin Center a PacoMouse mediante llamada y aceptarla.

TWIN CENTER | PacoMouse
Acción usuario | Descripción | Acción usuario | Acción automática
Accesorio 702 VERDE | Descolgar teléfono estación A
Accesorio 701 VERDE | Llamar a PacoMouse
ENTER (Aceptar llamada) | Accesorio 702 ROJO

?

#lok C #lok | Dispatch PUT locomotora 276

Accesorio 701 ROJO | Finalizar llamada
Dispatch GET

Rechazar llamada

TWIN CENTER | PacoMouse
Acción usuario | Descripción | Acción usuario | Acción automática
Accesorio 702 VERDE | Descolgar teléfono estación A
Accesorio 701 VERDE | Llamar a PacoMouse
MENU (Rechazar llamada) | Accesorio 701 ROJO
Conducir
Sel. Loco
Dispatch
Desvíos
Accesorio 702 ROJO | Colgar teléfono estación A

CONEXIÓN AL LOKMAUS2

La versión Xpressnet de PacoMouse por cable también se puede usar junto a la central Roco Lokmaus2 con el booster 10761 o 10764.

Tenga en cuenta que debido a las limitaciones de la central solo se podrán seleccionar las locomotoras 1 a 99, las funciones F0 a F4, los accesorios 1 a 256 y la programación de CV se verá limitada a las CV1 a CV256 en vía de programación no siendo posible su lectura.

El Lokmaus2 se ha de conectar a la conexión Master y el PacoMouse a la conexión Slave.

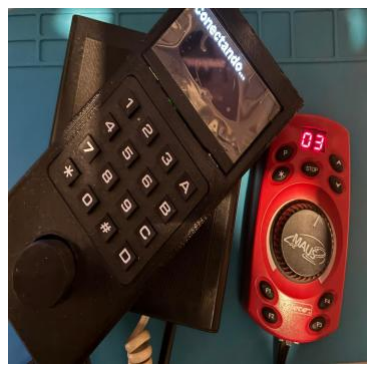
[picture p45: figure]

Si al conectar el PacoMouse sólo aparece en la pantalla ‘Conectando..’
puede deberse a que el Lokmaus2 no está explorando todos los dispositivos
Xpressnet del bus, para corregirlo siga estos pasos:
- Desconecte el Lokmaus2 y el PacoMouse.
- | Pulse la tecla | del Lokmaus2 mientras lo vuelve a conectar en
| el conector Master.
- Aparecerá la opción C0 en la pantalla.
- | Con las flechas | seleccione la opción C8 en la pantalla del
| Lokmaus2.
- | Pulse la tecla | del Lokmaus2
- | Con las flechas | seleccione el valor 28 en la pantalla del
| Lokmaus2.
- | Pulse la tecla | del Lokmaus2 y aparecerá C8 de nuevo en la
pantalla del Lokmaus2.
- Desconecte el Lokmaus2
- Vuelva a conectar el Lokmaus2 en el conector Master.
- Ahora ya puede conectar el PacoMouse en el conector Slave.

Si lo desea o nota que el Lokmaus2 responde más lento puede cambiar la dirección Xpressnet de PacoMouse en el menú Configuración – Dir. Xpressnet a un valor entre 1 y 5 y retornar la opción C8 del Lokmaus2 al valor 05 original.

CONEXIÓN AL MULTIMAUS

La versión Xpressnet de PacoMouse por cable también se puede usar junto a la central Roco Multimaus con el booster 10761 o 10764.

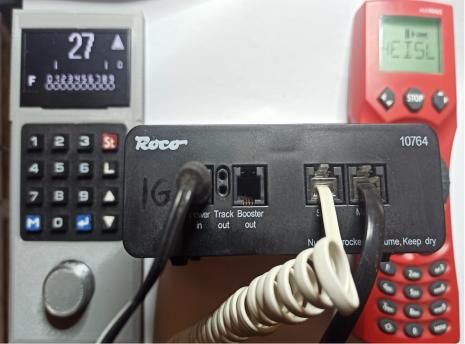
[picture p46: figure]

El Multimaus se ha de conectar a la conexión Master y el
PacoMouse a la conexión Slave.

Tenga en cuenta que debido a las limitaciones de la central la programación de CV se verá limitada a en vía de programación no siendo posible su lectura.

Anexo VII: Para los impacientes (RTFM: Read The Fucking Manual – Lea El Jodido Manual)

Si has empezado el manual por aquí seguramente has montado el PacoMouse, le has cargado el programa, lo has enchufado a tu central y no funciona como esperas. Aquí hay respuestas a alguna de tus preguntas, esta explicado en el manual pero aquí te lo resumo. Leer el Anexo VI: Consejos también sería conveniente.

SOLO FUNCIONAN ALGUNOS MENÚS

Parece que funciona pero algunas teclas no van y solo puedo entrar en algunos menús, como el de Conducción y el de Configuración.

Pulsa la tecla 'MENU' ('*' en el teclado) y selecciona Configuración, con el encoder busca la opción BLOQUEAR y pulsa el encoder, ahora selecciona una de las opciones marcadas con el encoder y desmárcala pulsando el encoder. Repite hasta tener las tres opciones desmarcadas.

NO ME DEJA CAMBIAR LAS OPCIONES EN LA CONFIGURACION

Comprueba que no esté activada ninguna opción de BLOQUEAR, si es así sigue paso a paso la pregunta anterior. El cursor grande te indica que la opción la puedes seleccionar, si sale el cursor pequeño selecciona primero su apartado que está en mayúsculas y ya tendrás el cursor grande para cambiar la opción.

LA VELOCIDAD NO BAJA A CERO Y LA LOCOMOTORA SIGUE A MARCHA MUY LENTA

Pulsando el encoder se detendrá, si se pulsa nuevamente se cambia de dirección. Estás en modo maniobras.

Pulsa la tecla 'MENU' ('*' en el teclado) y selecciona Configuración, con el encoder busca la opción MODO STOP y pulsa el encoder, ahora selecciona la opción Maniobras y desmárcala pulsando el encoder.

EL ENCODER FUNCIONA AL REVES

Hay muchos tipos de encoder y puede que no estén cableados igual, intercambia los cables S1/CLK y S2/DT.

LAS TECLAS NO ESTAN EN SU SITIO

Hay muchos tipos de teclado y puede que no estén cableados igual, PacoMouse está pensado para este orden de pines:

Pin teclado | Teclas | Pin Arduino
R1: Fila 1 | 1 2 3 A | D3
R2: Fila 2 | 4 5 6 B | D4
R3: Fila 3 | 7 8 9 C | D5
R4: Fila 4 | * 0 # D | D6
C1: Columna 1 | 1 4 7 * | D9
C2: Columna 2 | 2 5 8 0 | D10
C3: Columna 3 | 3 6 9 # | D11
C4: Columna 4 | A B C D | A0

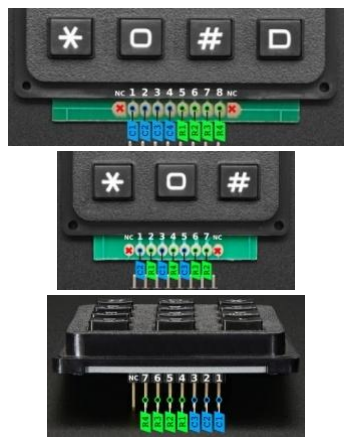
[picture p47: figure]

Cablea tu teclado para este orden de pines, puedes ayudarte del programa PacoMouse_HW_Test.ino que está en la carpeta del proyecto o modifica la definición de pines en el archivo config.h si sabes lo que estás haciendo.

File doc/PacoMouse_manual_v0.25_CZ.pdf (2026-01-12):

Návod k použití ovladače
PacoMouse od Paco

v0.25 05/2024

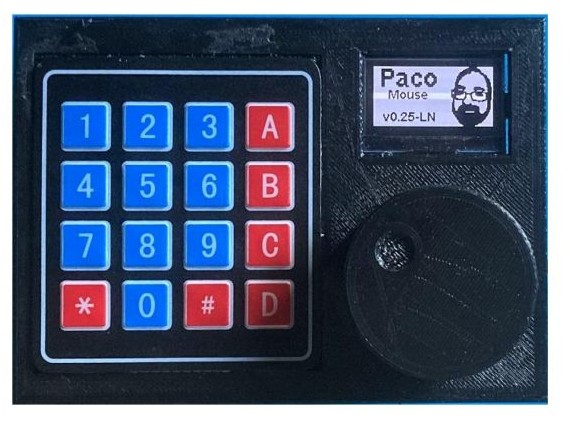
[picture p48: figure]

Pokud patříte k těm netrpělivým nebo k těm, kteří manuál nikdy nečetli, přejděte přímo na poslední stránku

Paco Canada https://usuaris.tinet.cat/fmco/

Index

Software používá knihovny s různými licencemi, dodržujte všechny jejich podmínky v nich obsažené. Loconet je registrovaná ochranná známka společnosti Digitrax, Inc. Xpressnet je registrovaná ochranná známka společnosti Lenz Elektronik GmbH. Z21 je značka Modelleisenbahn GmbH. Arduino je registrovaná ochranná známka společnosti Arduino Srl

Úvod

PacoMouse vznikl z potřeby mít jednoduchý přídavný ovladač pro ovládání lokomotiv pro modulární skupinu jako projekt udělej-si-sám (DIY). Jeho komercializace NENÍ povolena .

Existují různé verze PacoMouse s připojením na sběrnici Loconet, Xpressnet nebo připojení WiFi s protokolem Z21. Sestavte si ten nejvhodnější pro vaši centrálu:

Centrála | Loconet | Xpressnet | Z21
Lenz LZV100, LZV200 | | X
DR5000, YD7001 | X | X | X
Z21 (černá) | X | X | X
z21, z21 start (bílá) | | X | X
Multimaus | | X
Intellibox I, TwinCenter | X
Intellibox II | X
Digitrax | X
NanoX-S88 | | X

Ovladač je založen na Arduinu Nano (také Uno nebo Pro Mini) pro verzi Loconet nebo XpressNet nebo Wemos D1 mini (esp8266) pro verzi Z21, má rotační kodér EC11 s tlačítkem, 3x4 nebo 4x4 klávesnici a displej OLED SSD1306, SH1106 nebo SSD1309 (velikosti 0,96”, 1,3” nebo 2,42”).

### 1. Bezpečnostní pokyny

Tento výrobek není vhodný pro děti do 14 let. Protože jej může spolknout dítě mladší 3 let, měl by být uchováván mimo dosah.
Nesprávné použití může představovat riziko zranění v důsledku ostrých hran a výstupků. Doporučuje se používat tužkovou páječku s velmi jemným hrotem, aby nedošlo k poškození součástek.

### 2. Záruka

Všechny informace pro konstrukci a použití myši PacoMouse , protože se jedná o návrh „Udělej si sám“ (DIY) a je poskytován „tak jak je“, jsou bez záruky jakéhokoli druhu, výslovné nebo předpokládané, včetně škod způsobených nesprávnou interpretací, montáží, použitím nebo nesprávným zacházením.

### 3. Podpora a nápověda

Informace pro konstrukci a/nebo použití ovladače PacoMouse jsou k dispozici na následujících místech, kde je možné bez záruky nebo závazku získat pomoc:

https://usuaris.tinet.cat/fmco

### 4. Před montáží

Firmware PacoMouse lze přizpůsobit pro tři různé typy připojovaného rozhraní.

Verze Loconet a Xpressnet používají Arduino Nano (také Uno nebo Pro Mini), zatímco verze Z21 používá Wemos D1 mini (ESP8266). V přílohách tohoto dokumentu naleznete schémata pro sestavení každé z verzí.

Pro programování je použito prostředí Arduino IDE, ze kterého je možné načíst program a potřebné knihovny i přizpůsobit firmware PacoMouse úpravou souboru config.h pro naši desku.

Přílohy k tomuto dokumentu popisují, jak naprogramovat naše Arduino tak, aby přizpůsobilo myš PacoMouse našim potřebám.

### 5. Připojení

Když připojíte PacoMouse k řídící jednotce přes odpovídající rozhraní nebo zapnete napájení, na tři sekundy se objeví uvítací obrazovka s uvedením verze (Loconet, Xpressnet nebo Z21).

Pokud již byla lokomotiva dříve řízena, bude z řídicí centrály požadována informace o jejím aktuálním stavu a zobrazí se obrazovka „Jízdy“, v opačném případě se zobrazí obrazovka „Výběru lokomotivy“ .

Ve verzi Z21 se nejprve pokusí připojit k WiFi síti, kterou si uživatel nastavil, pokud se připojení nepodaří, vyhledá dostupné WiFi sítě v aktuálním umístění a po výběru vás požádá o konfiguraci a heslo. Chcete-li se připojit k této nové síti, musíte myš PacoMouse vypnout a znovu zapnout .

### 6. Menu

Kdykoli stisknutím klávesy 'MENU' ('*' na klávesnici) zobrazíte nabídku možností PacoMouse
verze | verze
Loconet | Xpressnet / Z21
Jízda | Jízda
Vybrat lokomotivu | Vybrat lokomotivu
Odeslání | Výhybky
Výhybky | Točna
Točna | Kyvadlová doprava
Kyvadlová doprava | Prog. CV
Prog. CV | Konfigurace
Konfigurace

Otáčením otočného kodéru můžeme zvolit jednu z možností nabídky a stisknutím tlačítka volbu vybereme. Můžeme také použít klávesy „C“ (↑) a „D“ (↓) nebo „MENU“ pro výběr možnosti a klávesu „ENTER“ ( na klávesnici „#“ ).

### 6.1 Výběr Lokomotivy

Pro výběr lokomotivy zadáme její číslo pomocí klávesnice. Maximální povolený počet je 9999, pokud je překročen, první číslice bude odstraněna. Pokud je číslo 0, zobrazí se '?'

Pomocí tlačítka 'ENTER' nebo stisknutím tlačítka kodéru se vybere zobrazené číslo lokomotivy a zobrazí se obrazovka „Jízdy“ (Řízení).

Klávesa 'LOCO' nás po stisknutí přenese přímo do této možnosti nabídky.

Uložení lokomotivy

PacoMouse ukládá lokomotivy vybrané během poslední relace, aby k nim bylo možné rychle přistupovat, aniž byste museli zadávat jejich číslo na klávesnici, otočením kodéru nebo stisknutím kláves „C“ (↑) a „D“ (↓) zobrazíte adresy dříve vybraných lokomotiv v pořadí použití.

Odpojením PacoMouse ztratíte seznam lokomotiv v aktuální relaci.

Návod k použití ovladače
https://usuaris.tinet.cat/fmco/

### 6.2 Jízda

Na obrazovce řízení (jízdy) se zobrazuje číslo lokomotivy a pomocí šipky (vpřed ▲, vzad ▼) její směr jízdy.

Vodorovný pruh ukazuje aktuální rychlost, vedle něj je zobrazen rychlostní krok. Spodní řádek zobrazuje aktuální stav funkcí lokomotivy, podle toho, jak bylo nakonfigurováno.

Pokud jsou v centrále aktivovány rychlé hodiny a byl přenesen aktuální čas, zobrazí se v levém horním rohu.

Otočným kodérem lze rychlost lokomotivy zvýšit a snížit. Stisknutím tlačítka kodéru za jízdy lokomotivy se lokomotiva zastaví. Při zastavené lokomotivě se stisknutím tlačítka kodéru změní směr jízdy.

Pokud je aktivní funkce kyvadlové dopravy, zobrazí se . Pokud ve verzích Xpressnet a Z21 převezme řízení naší lokomotivy jiný ovladač, zobrazí se symbol

Pokud se ve verzi Z21 nepodařilo navázat připojení k WiFi síti, na obrazovce se
zobrazí , pokud je baterie slabá, zobrazí se symbol

Pomocí kláves „C“ (↑) a „D“ (↓) (nebo klávesy „ENTER“ na klávesnici 3x4) můžete vybrat funkce podle jejich zobrazené velikosti:

VELKÉ: F0-F4, F5-F8, F9-F12, F13-F16, F17-F20, F21-F24, F25-F28. Pomocí numerické klávesnice můžete aktivovat a deaktivovat funkce, klávesa „0“ vždy aktivuje/deaktivuje F0, klávesy „1“ až „4“ dělají totéž se čtyřmi zbývajícími zobrazenými funkcemi. Pokud se zobrazuje F0-F4 (nebo F0-F8 podle konfigurace), pro rychlý přístup klávesy „5“ až „8“ ovládají funkce F5 až F8. Pokud jsou „zrychlené hodiny“ aktivní, můžou být klávesou '9' zobrazeny ve větší velikosti a adresa lokomotivy v menší, dalším stiskem ji znovu zobrazíte v původní velikosti.

MALÉ: F0-F9, F10-F19, F20-F28. Pomocí numerické klávesnice můžete aktivovat a deaktivovat funkce pomocí kláves „0“ až „9“. Pokud je zobrazeno F2 (F20-F28), a jsou aktivní „zrychlené hodiny“, můžou být klávesou '9' zobrazeny ve větší velikosti a adresa lokomotivy v menší velikosti, opětovným stisknutím se opět zobrazí ve své původní velikosti.

Když stisknete tlačítko 'STOP' , výstup do kolejí je deaktivován (nouzově vypnutý).

### 6.3 Odeslání (volba pouze pro Loconet)

V Loconetu můžeme odeslat (Dispatch PUT) naši lokomotivu tak, aby řízení mohl převzít ovladač bez možnosti výběru lokomotiv (Fred atd.) příkazem převzít (Dispatch GET).

Při odeslání (PUT) je naše lokomotiva umístěna do speciálního slotu v centrální jednotce, aby mohl řízení převzít jiný příkaz, takže se nám zobrazí obrazovka „Výběr lokomotivy“, abychom mohli vybrat jinou lokomotivu.

Pokud není řízena žádná lokomotiva, místo 'PUT Loco' , se zobrazí 'Sel. Loco', ručně jednu vyberte.

Pomocí volby 'GET Loco' může PacoMouse také převzít kontrolu nad lokomotivou dříve odeslanou jiným příkazem.

Pomocí kodéru vybereme volbu a stisknutím tlačítka kodéru přistoupíme k odeslání nebo převzetí řízení již dříve odeslané lokomotivy.

Pokud není k dispozici žádná lokomotiva, pro kterou lze převzít řízení, volba 'GET Loco' vyvolá čekací obrazovku.

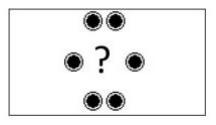
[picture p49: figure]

PacoMouse má jedinečný systém simulace telefonního zámku pro přesun vlaků mezi vedlejšími stanicemi, z nichž každá je vybavena PacoMouse a využívá adresy příslušenství přiřazené každému příkazu Dispatch Loconetu.

Máme telefonní seznam (viz 6.8 Konfigurace) s telefonním číslem (číslem příslušenství) naší stanice (naše PacoMouse) a až čtyřmi doplňkovými stanicemi.

Když chceme lokomotivu, kterou řídíme, přemístit do vedlejší stanice, vybereme v menu volbu Odeslat stanice. Objeví se seznam čtyř vedlejších stanic, ze kterých vybereme tu, kterou chceme volat:

Probíhající hovor se zobrazí na naší obrazovce. Pomocí tlačítka 'MENU' můžeme hovor zrušit.

Příchozí hovor se zobrazí na obrazovce myši PacoMouse, které voláme, podle telefonního seznamu:

Tlačítkem 'ENTER' můžeme hovor přijmout a tlačítkem 'MENU' jej můžeme odmítnout. Pokud jej přijmete, lokomotiva nám bude automaticky odeslána z druhé myši PacoMouse a objeví se obrazovka pro její ovládání:

Po odeslání zobrazí myš PacoMouse ve výchozí stanici obrazovku výběru lokomotivy:

Pokud jsme hovor odmítli, zobrazí se „Menu“ a myš PacoMouse na výchozí stanici zobrazí varování „zastavte vlak“:

Pokud má cílová stanice pro další hovor při volání již vyvěšený telefon (jeho příslušenství je ZELENÉ ), ukáže nám, že komunikace nebyla možná, pro ukončení hovoru stiskněte klávesu 'MENU'.

POZNÁMKA: V ovládání lokomotivy, kterou jsme zvolili, pokračujeme během hovoru enkodérem. Zabránit v tom, aby nám volali, můžeme zvednutím telefonu (přepnutím příslušenství naší stanice do ZELENÉ polohy) a hovory znovu povolit zavěšením (přepnutím do ČERVENÉ polohy).

### 6.4 Výhybky

Pro přesun výhybky nebo digitálního příslušenství zadáme jeho číslo, ikona vpravo ukáže jeho aktuální pozici, jak je hlášena centrální jednotkou. Klávesou 'ENTER' změníme jeho aktuální polohu z přímé na odbočku nebo naopak. Číslo výhybky můžeme také změnit pomocí tlačítka „C“ (↑), jeho zvýšením nebo pomocí tlačítka „D “ (↓) jeho snížením.

Pomocí kodéru můžeme pokračovat v ovládání lokomotivy, kterou jsme si vybrali.

### 6.5 Točna

S PacoMouse můžeme ovládat digitalizovanou točnu pomocí dekodéru kompatibilního s Märklin 7686 se základní adresou 209 (klávesnice 14) nebo 225 (klávesnice 15) nebo s Fleischmann TurnControl 6915 se základní adresou 200.

Základní ovládání točny provedeme z této obrazovky:

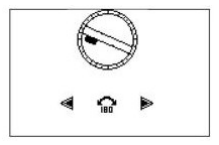
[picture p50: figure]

Pokud použijeme dekodér 7886 nebo kompatibilní, klávesou „1“ přesuneme most na další výjezdovou cestu umístěnou proti směru hodinových ručiček (CCW) a klávesou „3“ ji přesuneme na další výjezdovou cestu ve směru hodinových ručiček (CW). Pomocí klávesy '2' otočíme most o 180º.

Pokud použijeme dekodér 6915 nebo kompatibilní, klávesou '1' zvolíme pohyb proti směru hodinových ručiček (CCW) a klávesou '3' ve směru hodinových ručiček (CW). Pomocí klávesy '2' otočíme most o 180º.

Klávesou 'ENTER' přejdeme na další obrazovku, kde můžeme přímo zvolit cílový výjezd pro pohyb mostu:

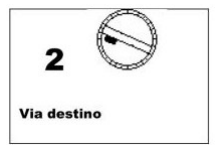
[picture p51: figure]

Pomocí klávesnice zadáme číslo cílového výjezdu a stisknutím 'ENTER' se most přesune směrem k němu.

Na obrazovce se krátce objeví symbol označující začátek pohybu mostu.

Pokud je číslo výjezdu pro dekodér točny nulové nebo neplatné, zobrazí se otazník (?). Pokud v tomto okamžiku stisknete 'ENTER', vrátíte se na základní obrazovku pohybu točny.

Pomocí enkodéru můžeme pokračovat v ovládání lokomotivy, kterou jsme si vybrali.

### 6.6 Kyvadlová doprava (Shuttle)

Můžeme nechat PacoMouse ovládat naši lokomotivu jako kyvadlový vlak mezi dvěma stanicemi, pokud jsou vybaveny hlášením zpětné vazby. Po dojezdu do stanice a aktivaci detektoru obsazení se vlak zastaví a po určité době změní směr, po další době se opět rozjede směrem ke druhé stanici.

Pomocí kodéru ovládáme rychlost a směr, funkce lze měnit z obrazovky jízdy. Brzdění na stanicích bude probíhat tak, jak je naprogramováno ve vašem CV.

Pomocí tlačítka 'ENTER' můžete měnit data, přecházet z jednoho do druhého: Aktivace funkce Shuttle (pomocí tlačítka '1'), dva kontakty zpětné vazby a časový interval (až 255 sekund). Stisknutím tlačítka 'MENU' ukončíte režim úprav.

Ve verzi Loconet si můžete vybrat detektory zpětné vazby od 1 do 2048, v Xpressnetu RS od 1.1 do 128.8 a ve verzi Z21 zpětnou vazbu R-BUS od 1.1 do 20.8.

Pokud chcete změnit některou z hodnot a také aktivovat funkci kyvadlové dopravy, udělejte to v době, kdy lokomotivou není aktivován žádný z kontaktů.

POZOR: Při výměně lokomotiv bude funkce kyvadlové dopravy deaktivována, takže pokud je v pohybu, ve stanici nezastaví.

### 6.7 Programování CV

CV našich dekodérů můžeme programovat jak na programovací koleji (čtení a zápis v režimu Direct), tak na hlavní koleji (PoM, pouze zápis). Ve verzi Loconet také LNCV.

Kromě toho lze hlavní CV upravovat přímo z nabídky pomocí programovací cesty:
verze LocoNet | verze XpressNet
Programovací kolej | Programovací kolej
Hlavní kolej (PoM) | Hlavní kolej (PoM)
Adresa lokomotivy | Adresa lokomotivy
Rychlost minimální | Rychlost minimální
Rychlost střední | Rychlost střední
Rychlost maximální | Rychlost maximální
Zrychlení | Zrychlení
Brzdění | Brzdění
Konfigurace | Konfigurace
Výrobce | Výrobce
LCNV

Možnost programování na programovací koleji nám umožňuje zadat číslo CV, které lze upravit pomocí klávesnice:

Ve verzi Xpressnet je v závislosti na typu a verzi centrály maximální číslo CV 256 nebo 1024.

Stisknutím tlačítka „ENTER“ se hodnota CV načte a zobrazí se na displeji. Aby se usnadnila interpretace CV, na spodním řádku se zobrazí bity, které jsou pro tuto hodnotu aktivní. Pokud CV nelze přečíst, zobrazí se '???' .

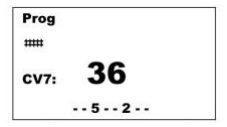
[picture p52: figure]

Pokud chceme hodnotu upravit, zadáme pomocí klávesnice novou hodnotu a stisknutím 'ENTER' ji zapíšeme do dekodéru. Pokud stiskneme 'MENU', můžeme si vybrat jiný CV bez úpravy hodnoty aktuálního. Stejně tak možnost programování na hlavní koleji nám umožňuje upravovat CV, které zadáváme pomocí klávesnice. Zobrazí se nám lokomotiva, kterou budeme programovat, pokud není správná, budeme ji muset vybrat v menu „Výběr lokomotivy“, pro přímý přístup k této volbě můžeme stisknout klávesu 'LOCO'.

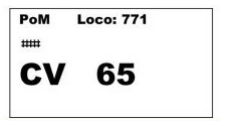
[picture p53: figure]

Základní CV lze upravit přímo z programovacího menu. Při výběru možnosti se CV načte z programovací koleje a jeho hodnota se zobrazí na displeji.
Základní CV jsou: Adresa (CV1, CV17, CV18), minimální (CV2), střední (CV6) a maximální (CV5) rychlost, zrychlení (CV3), brzdění (CV4), konfigurace (CV29) a výrobce (CV8) .

U CV8 se po přečtení zobrazí také jméno výrobce, pokud je jedním z nejběžnějších:

Volba adresy lokomotivy načte aktuální adresu z CV1 nebo CV17 a CV18 podle toho, zda je v CV29 naprogramována jako krátká nebo dlouhá adresa. Navíc bude zavedena do zásobníku.

Novou adresu můžeme zadat z klávesnice a stiskem 'ENTER' se správně naprogramují jak CV1, tak CV17 a CV18 i CV29, takže se nebudeme muset starat o to, zda se jedná o krátkou resp. dlouhou adresu.

Poznámka:
Mějte to na paměti, pokud přiřazujete adresy mezi 100 a 127:
- V systémech Loconet obsahuje krátká adresa adresy 1 až 127, zatímco v systémech Xpressnet obsahuje adresy 1 až 99. U Z21 lze v konfiguraci nastavit, aby odpovídala tomu, co je nastaveno v centrále. Verze PacoMouse (Z21, Loconet nebo Xpressnet) bere tyto vlastnosti v úvahu při programování konfiguračních CV.
- Existují řídící jednotky, jako je Digikeijs DR5000 a Z21, které umožňují zadat nejvyšší číslo krátké adresy.

LNCV (volba pouze pro Loconet)

Ve verzi Loconet lze také programovat LNCV modulů. Nejprve musíte zadat číslo výrobku (nahlédněte do manuálu) a číslo modulu pomocí číselných tlačítek a stisknout 'ENTER'

Některé moduly mají funkci zjišťování, pomocí které je hlášeno jejich číslo výrobku a modulu. Chcete-li to provést, připojte ke sběrnici pouze modul, který má být programován, a zadejte číslo výrobku 65535, pokud má tuto funkci, tak se po stisku 'ENTER' zobrazí číslo výrobku, když znovu stisknete 'ENTER', objeví se číslo modulu.

Nyní můžete programovat LNCV, nejprve zadejte číslo podle toho, které chcete programovat (viz manuál vašeho modulu), stisknutím 'ENTER' se vybrané LNCV načte.

Pokud chcete upravit jeho hodnotu, zadejte svou novou hodnotu pomocí numerické klávesnice a stiskněte 'ENTER', pokud ji nechcete měnit, stiskněte 'MENU' pro návrat do výběru LNCV.

Pokud jej nelze upravit, protože LNCV není implementováno nebo je pouze pro čtení, jako hodnota LNCV se zobrazí ?. Neimplementovaná LNCV obvykle při čtení zobrazuje hodnotu 65535.

POZOR: LNCV0 obsahuje číslo modulu, pokud jej upravíte, znovu si jej přečtěte, abyste ověřili, že bylo správně zapsáno. Modul správně opustí programovací režim.

Pokud zvolíte číslo výrobku a modulu, které neexistuje nebo není připojeno ke sběrnici, odpovědi nebudou okamžité, jejich zobrazení bude trvat asi dvě sekundy, takže zobrazenou hodnotu je třeba zahodit, protože se jedná o náhodnou hodnotu.

### 6.8 Konfigurace

V části konfigurace se zobrazí nabídka s různými možnostmi, které si uživatel může vybrat, aby přizpůsobil PacoMouse svým preferencím:

Verze Loconet | Verze Xpressnet | Verze Z21
Možnosti: | Možnosti: | Možnosti:
►Kontrast | ►Kontrast | ►Kontrast
20 | 20 | 20
STOP | STOP | STOP
- Rychlost 0 | ○ Rychlost 0 | ○ Rychlost 0
- Havarijní zastavení | ● Havarijní zastavení | ● Havarijní zastavení
□ Posun | □ Posun | □ Posun
Typ centrály | Adresa XpressNet | WiFi
- IB II/ DR5000 | 8 | SSID
- Uhlenbrock | Točna | Heslo
- Digitrax | ○ 7686KB14 | IP
Točna | ● 7686KB15 | Krátká adresa
- 7686KB14 | ○ F6915 | ● 1 až 99
- 7686KB15 | □ Adresa RoCo | ○ 1 až 127
- F6915 | Zámek | Točna
Zámek | □ Nastavení lokomotivy | ○ 7686KB14
□ Nastavení lokomotivy | □ Výhybky | ● 7686KB15
□ Výhybky | □ Prog. CV | ○ F6915
□ Prog. CV | Hry | □ Adresa RoCo
Telefonní seznam | Piškvorky | Zámek
PacoMouse | Had | □ Nastavení lokomotivy
Stanice | Flappy bird | □ Výhybky
| Paku paku | □ Prog. CV
| | Hry
| | Piškvorky
| | Had
| | Flappy bird
| | Paku paku

Kurzor ► ukazuje, že lze volbu vybrat, a kurzor '>', pokud ne. Chcete-li možnost vybrat, stiskněte tlačítko kodéru nebo klávesu 'ENTER', pro ukončení bez úprav stiskněte klávesu 'MENU'

KONTRAST

Kontrast lze zvolit otočením enkodéru mezi hodnotou 0 a 255 (0 a 100 u SSD1309 kvůli jeho vysoké spotřebě). Kontrast se bude lišit v závislosti na zvolené hodnotě.

REŽIM STOP

Když při jízdě stisknete tlačítko kodéru a lokomotiva je v pohybu, zastaví se. Můžete si vybrat, zda to udělá tak, jak má naprogramováno ve svém brzdícím CV při vyslání rychlosti 0, nebo nouzově zastaví.
Lze aktivovat režim posunu, ve kterém lze pomocí enkodéru rychlost snížit na krok 1. Pro zastavení lokomotivy musíte stisknout tlačítko kodéru. Tímto způsobem máte při provádění posunu přesnější kontrolu zastavení.

TYP CENTRÁLY (Volba pouze pro Loconet)

U funkcí F9 až F28 se příkazy, které má Loconet odeslat, liší podle typu centrály, ke které je ovladač připojen. Zde můžete určit typ centrály.

XPRESSNET ADRESA (volba pouze pro Xpressnet)

Každý ovladač Xpressnet vyžaduje pro správnou komunikaci jedinečnou adresu sběrnice. Vyberte adresu mezi 1 a 31, kterou nepoužívá jiný ovladač.

WIFI (volba pouze pro Z21)

Můžeme vybrat WiFi SSID naší centrály ze seznamu, heslo a jeho IP adresu (ve výchozím nastavení je 192.168.0.111).

Pomocí enkodéru můžeme ve volbě „SSID“ vybrat mezi různými prvky a tlačítkem nebo klávesou 'ENTER' vybrat zvolenou síť.

Ve volbě „Heslo“ vybereme nový znak k přidání pomocí enkodéru a jeho tlačítkem jej přidáme. Pokud je vybraným znakem mezera, vymažeme poslední zadaný znak. Pomocí klávesy 'ENTER' nové heslo uložíme.

Ve volbě IP vybereme enkodérem hodnotu každé ze čtyř skupin čísel mezi 0 a 255, jeho tlačítkem přejdeme na další skupinu a klávesou 'ENTER' novou IP uložíme.

Změny budou zohledněny při příštím restartu PacoMouse.

KRÁTKÁ ADRESA (Volba pouze pro Z21)

Při programování CV adresy lokomotivy můžete zvolit maximální adresu, která je považována za krátkou, aby odpovídala adrese stanovené v Z21.

TOČNA

Můžete si vybrat, zda je točna digitalizována pomocí dekodéru kompatibilního s Märklin 7686 na základní adrese 209 (klávesnice 14) nebo 225 (klávesnice 15) nebo pomocí Fleischmann TurnControl 6915 na základní adrese 200.

Ve verzích Xpressnet a Z21 můžete zkontrolovat 'adresy Roco' pro opravu posunu adres na systémech Roco při používání točny.

ZÁMEK (BLOKOVÁNÍ)

Aby se předešlo nechtěným situacím, pokud jsme v klubu, nebo necháváme PacoMouse hostům, lze některé možnosti zablokovat.

Zámek výběru lokomotivy zabrání našemu hostu, aby si omylem vybral jinou lokomotivu. Ve verzi Loconet blokuje také možnost „Dispatch“.

Zámek výhybky zabraňuje změně polohy výhybek a také blokuje pohyb točny.

Zámek programování CV zabraňuje úpravám CV. To je zvláště užitečné, když centrála nemá samostatnou programovací kolej, protože všechny lokomotivy na koleji mohou přijímat stejné programování.

POZOR: Aktivace kteréhokoli z těchto zámků deaktivuje klávesu 'STOP' , aby se zabránilo stavu trati bez napětí v celém kolejišti klubu.
Deaktivuje také možnou úpravu zbývajících možností konfigurace , takže pokud je chcete změnit, musíte před úpravou jakékoli jiné možnosti deaktivovat tyto tři možnosti zámku.

HRY (volba pouze pro Z21 a Xpressnet)

Protože je ve verzích Xpressnet a Z21 dostatek programového prostoru, byla přidána také nějaká zábava. Populární hra Snake z prvních mobilních telefonů, piškvorky, Flappy Bird a Paku Paku.

Ve hře Snake stisknutím enkodéru spustíte hru a stejným enkodérem můžeme navést hada, aby našel potravu a zabránil tomu, aby byl zasažen elektrickým proudem oplocení. Když dostatečně vyroste, přepne se na další úroveň s vyšší rychlostí.

V piškvorkách (3 v řadě) hrajeme s X a PacoMouse s ○. Pomocí enkodéru přesuneme kurzor ● pro výběr našeho kvadrantu a stisknutím vložíme X. PacoMouse poté, co se zamyslí nad svým tahem, umístí svoje ○, nepodceňujte ho. S každou novou šachovnicí dojde ke změně začínajícího hráče.

Ve Flappy Bird stisknutím enkodéru vyletíte výš, když jej uvolníte, budete klouzavě klesat. Cílem je proletět co největším počtem sloupů, aniž byste se s nimi srazily, čím více sloupů minete, tím rychleji poletíte. Nejvyšší skóre získané v této sérii her je uvedeno na úvodní obrazovce.

Paku Paku je verze jednorozměrného Pacmana, ve kterém musí jíst tečky při útěku před nepřítelem. Když sní velkou tečku, má časové období, ve kterém je silnější než nepřítel a může jej sníst. Paku může uprchnout na jednom konci a objevit se na druhém, zatímco nepřátelé projít nemohou.

Když sníte všechny body, zvýšíte jednu úroveň a rychlost. Paku změní směr stisknutím tlačítka kodéru.

Had | Piškvorky | Flappy Bird | Pacman

TELEFONNÍ SEZNAM (Volba pouze pro Loconet)

Seznam adres příslušenství přiřazených vedlejším stanicím a stanici, kde se PacoMouse nachází, jako by to byl telefonní zámek pro Lokomotivní dispečink .

Pomocí kodéru si můžete vybrat mezi čísly 701 a 799 pro čtyři stanice a naši, nebo jej nechat nepřiřazené (zobrazí se 7??).

Pokud naše adresa nebude přidělena, nebudeme moci z našeho velení vlaky odesílat ani je přijímat pomocí tohoto jedinečného systému simulace telefoního zámku PacoMouse .

POZNÁMKA: Nevybírejte čísla, která již používá jiné příslušenství na modelu.

Příloha I : Schémata

Schéma Arduino Nano (Loconet Interface)

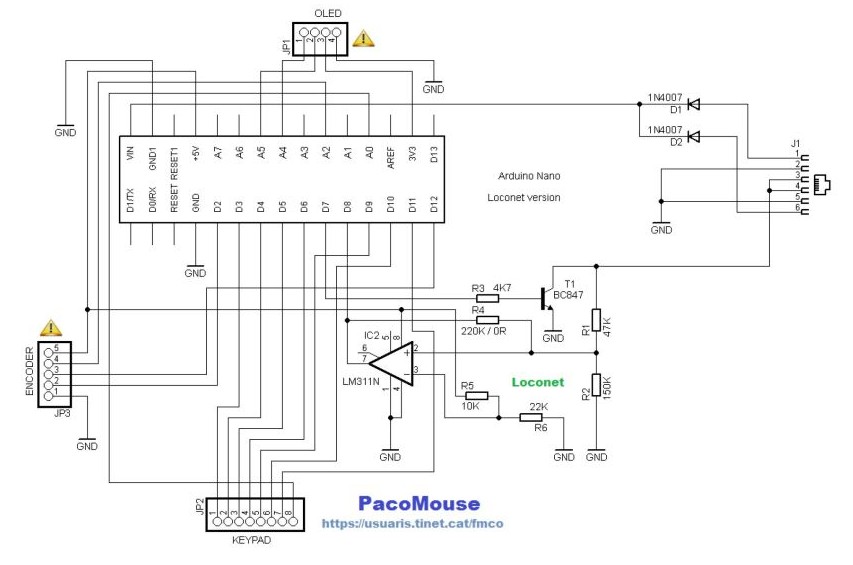
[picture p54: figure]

POZNÁMKA: Zkontrolujte připojení vašeho hardware, zejména OLED displeje, protože mají různé uspořádání pinů. Pokud je pohyb enkodéru obrácený, změňte připojení jeho pinů (CLK/DT, S1/S2).
POZNÁMKA: Displej OLED je napájena 3,3V, nenechte se mýlit!!

Schéma Arduino Nano (rozhraní Xpressnet)

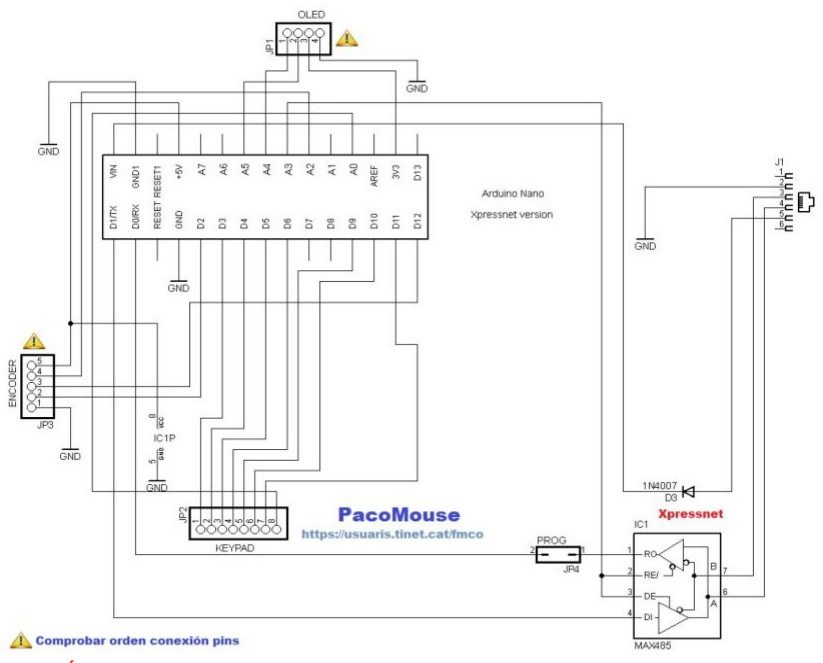
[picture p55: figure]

POZNÁMKA: Zkontrolujte připojení hardwaru, zejména OLED displeje, protože mají různé uspořádání pinů. Pokud je pohyb enkodéru obrácený, změňte připojení jeho pinů (CLK/DT, S1/S2).

POZNÁMKA: Displej OLED je napájen 3,3V, nenechte se mýlit!

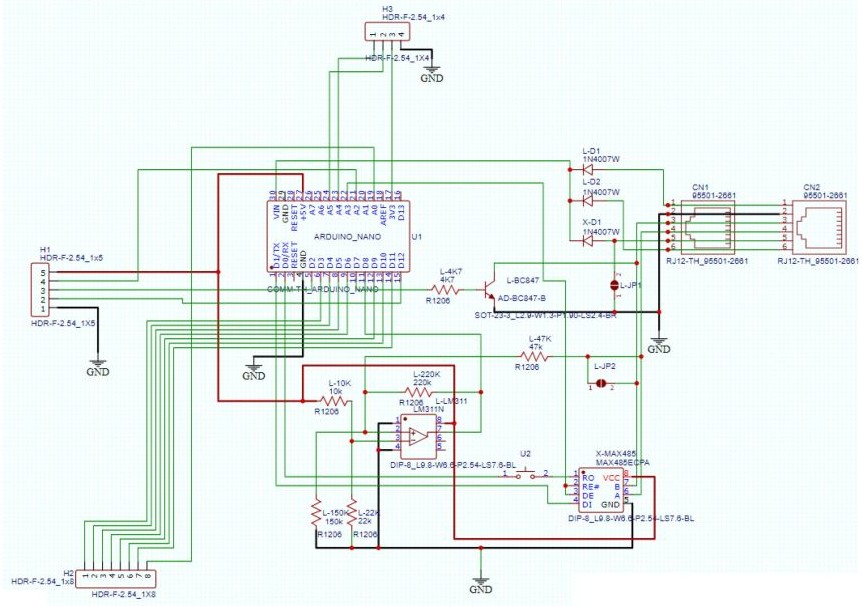
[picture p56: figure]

Schéma desky PacoMouse s Arduino Nano (rozhraní Loconet nebo Xpressnet)

Připojení komponent

Toto jsou připojení Arduino Nano s různými součástkami ve výchozím nastavení tak, jak jsou definovány v souboru config.h

Arduino Nano | OLED | Klávesnice | Encoder | Poznámka
TX | | | | XpressNet: MAX485 pin 1
RX | | | | XpressNet: MAX485 pin 4
D2 | | | S2/DT
D3 | | 1 řádek
D4 | | 2 řádek
D5 | | 3 řádek
D6 | | 4 řádek
D7 | | | | LocoNet: výstup přes rezistor na BC547
D8 | | | | LocoNet: vstup z LM311 pin 7
D9 | | 1 sloupec
D10 | | 2 sloupec
D11 | | 3 sloupec
D12 | | | S1/CLK
D13
A0 | | 4 sloupec | | U klávesnice 3x4: nepřipojen
A1
A2 | | | KEY/SW
A3 | | | | XpressNet: MAX485 pin 2 a 3
A4 | SDA
A5 | SCL
5V | | | VCC
3V3 | VDD
GND | GND | | GND

Schéma Wemos D1 mini (rozhraní Z21)

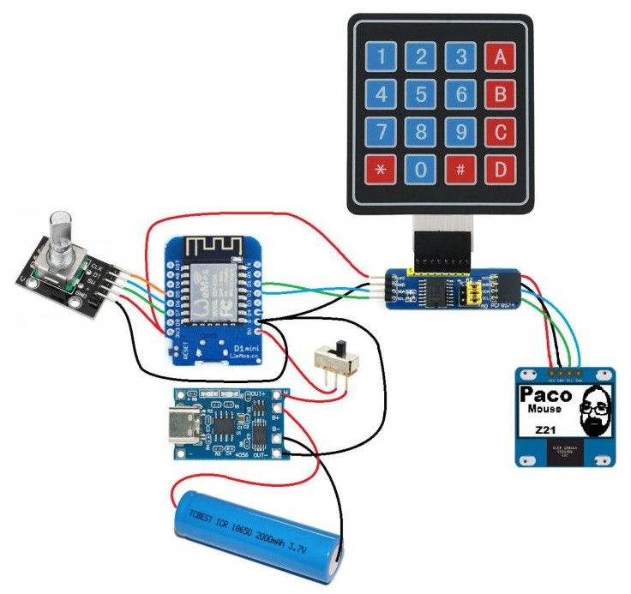
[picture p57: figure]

POZNÁMKA: Zkontrolujte připojení hardwaru, zejména OLED displeje, protože mají různé uspořádání pinů.

Pokud je pohyb enkodéru obrácený, zaměňte připojení jeho pinů (CLK/DT, S1/S2).

Pokud je použita klávesnice 3x4, připojuje se k 7 pinům ve středu desky PCF8574.

POZNÁMKA: Displej OLED je napájen 3,3V, nenechte se mýlit!

Toto jsou připojení Wemos D1 mini s různými součástkami ve výchozím nastavení tak, jak jsou definovány v souboru config.h

Wemos D1 Mini | PCF8574 | OLED | Klávesnice | Enkodér | Baterie/ nabíječka | Poznámka

TX
RX
D0
D1 | SCL | SCL
D2 | SDA | SDA
D3
D4
D5 | | | | S2/DT
D6 | | | | S1/CLK
D7 | | | | Key/SW
D8
A0
5V | | | | | +
3V3 | VCC | VDD | | VCC
GND | GND | GND | | GND | GND
| INT
| 7 1 řádek
| 6 2 řádek
| 5 3 řádek
| 4 4 řádek
| 3 1 sloupec
| 2 2 sloupec
| 1 3 sloupec
| 0 | | 4 sloupec | | | U klávesnice 3x4: nepřipojen

Příloha II: Seznam součástek

Verze PacoMouse | Loconet* | XpressNet* | Z21*
Arduino Nano/ProMini (ATmega328) | X | X
Wemos D1 mini (ESP8266) | | | X
OLED displej: SSD1306 (0.96“) / SH1106 (1.3“) / SSD1309 (2.42“)**** | X* | X* | X*
Klávesnice: maticová 3x4 / maticová 4x4 | X* | X* | X*
PCF8574 | | | X*
Enkodér EC11 s tlačítkem | X | X | X
Tranzistor: BC547 | X
Rezistory: 150K / 47K / 4K7 / 22K / 10K / 220K | X X**
Dioda: 1N4007 | X (2x) | X
LM311 | X**
RJ12 | X | X
MAX485 | | X
Propojka / jumper | | X***
Nabíječka baterií TP4056 | | | X
Baterie 18650 | | | X
Vypínač | | | X

(*) V souboru config.h můžeme (*) podle použitého hardware upravit několik možností (**) Další komponenty pro klasické rozhraní Loconet.
(***) Chcete-li naprogramovat Arduino, aniž byste jej museli rozebírat nebo odpojovat MAX485 (****) Spotřeba tohoto OLED displeje je poměrně vysoká. (viz příloha IV)

Deska PacoMouse

POZNÁMKA: Deska umožňuje montáž verze Loconet i Xpressnet. Osaďte pouze komponenty potřebné pro zvolenou verzi.

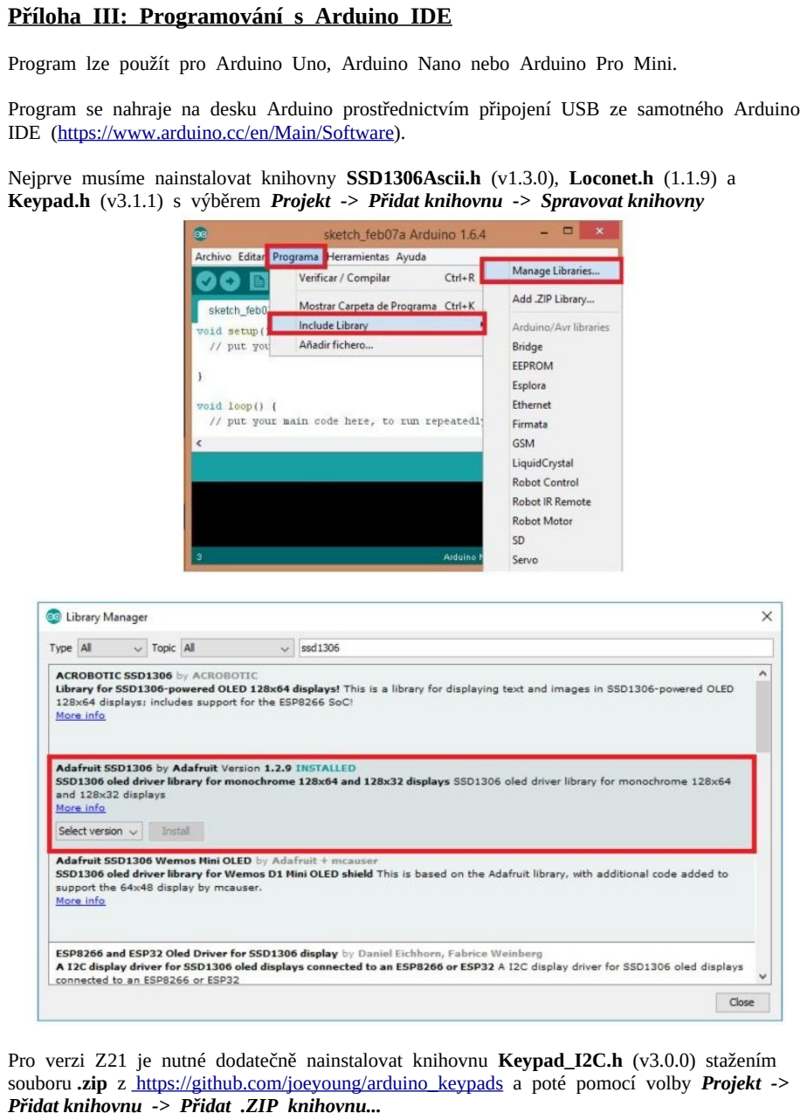
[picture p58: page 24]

Příloha III: Programování s Arduino IDE

Program lze použít pro Arduino Uno, Arduino Nano nebo Arduino Pro Mini.

Program se nahraje na desku Arduino prostřednictvím připojení USB ze samotného Arduino IDE (https://www.arduino.cc/en/Main/Software).

Nejprve musíme nainstalovat knihovny SSD1306Ascii.h (v1.3.0), Loconet.h (1.1.9) a Keypad.h (v3.1.1) s výběrem Projekt -> Přidat knihovnu -> Spravovat knihovny

Pro verzi Z21 je nutné dodatečně nainstalovat knihovnu Keypad_I2C.h (v3.0.0) stažením souboru .zip z https://github.com/joeyoung/arduino_keypads a poté pomocí volby Projekt -> Přidat knihovnu -> Přidat .ZIP knihovnu...

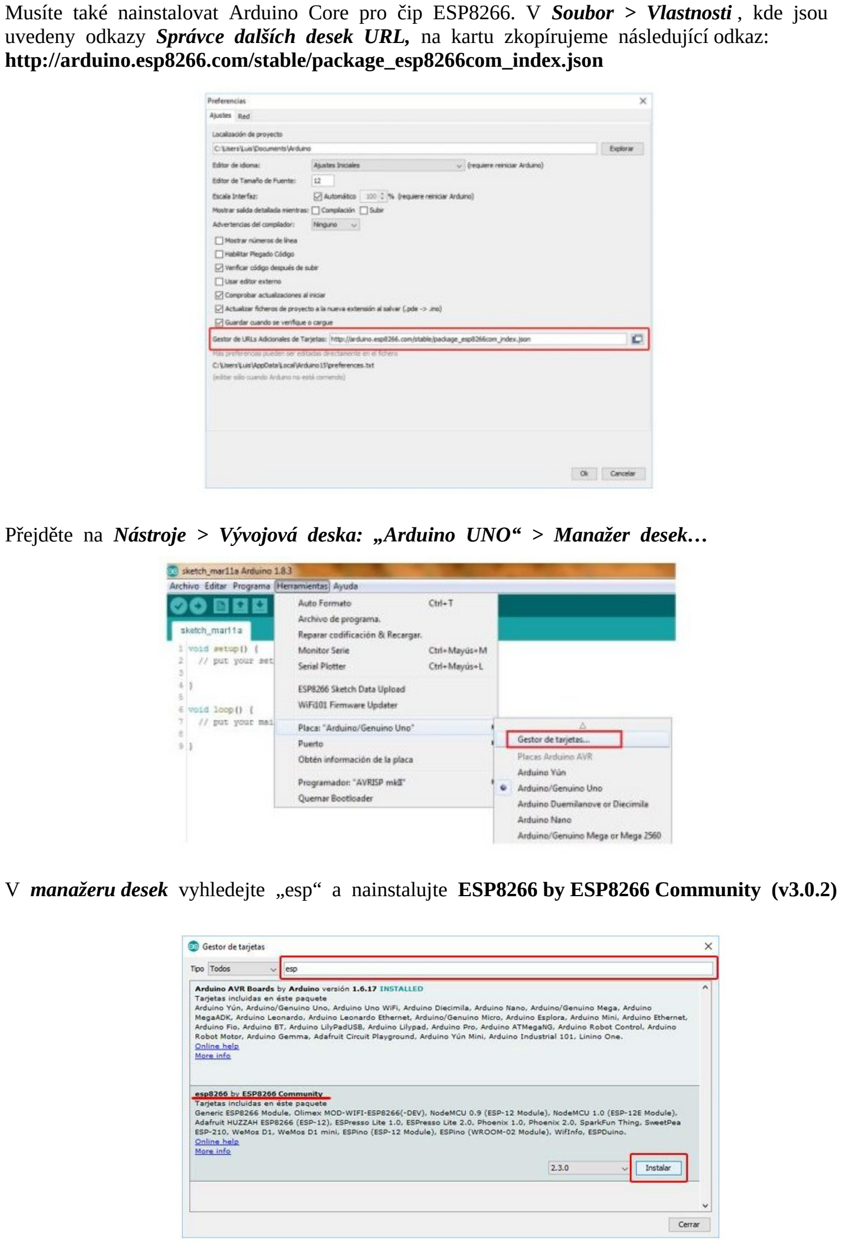
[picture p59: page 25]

Musíte také nainstalovat Arduino Core pro čip ESP8266. V Soubor > Vlastnosti , kde jsou uvedeny odkazy Správce dalších desek URL, na kartu zkopírujeme následující odkaz: http://arduino.esp8266.com/stable/package_esp8266com_index.json

Přejděte na Nástroje > Vývojová deska: „Arduino UNO“ > Manažer desek…

V manažeru desek vyhledejte „esp“ a nainstalujte ESP8266 by ESP8266 Community (v3.0.2)

Nastavení

Existuje řada konfigurací, které lze v závislosti na tom, co jsme nainstalovali, zvolit při programování PacoMouse v Arduino IDE.

V souboru config.h můžeme upravit několik možností pro přizpůsobení kódu naši verzi PacoMouse, kterou jsme sestavili.

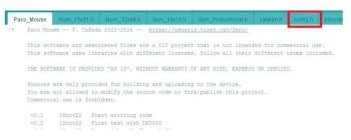
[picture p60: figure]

POZOR: Upravte pouze tento soubor (config.h)
a pouze v části kódu, která začíná:

//////////////////////////////////////////// //////////
// ***** USER OPTION ***** //////////////////////////////////////////// //////////
a končí:

//////////////////////////////////////////////////// //////////
// ***** END OF USER OPTION ***** //////////////////////////////////////////////////// //////////

Níže jsou pro každou možnost uvedeny hodnoty, které lze upravit červeně a možné hodnoty fialově:

POZNÁMKA: Chcete-li odkomentovat řádek, odstraňte znaky // na jeho začátku.

Jakmile přizpůsobíte možnosti vaší PacoMouse , můžete přejít k další kapitole a programovat vaše Arduino.

Tento software a související soubory jsou DIY projektem, který není určen pro komerční použití.

SOFTWARE JE POSKYTOVÁN „TAK, JAK JE“, BEZ ZÁRUKY JAKÉHOKOLI DRUHU, VÝSLOVNÉ NEBO PŘEDPOKLÁDANÉ.

Zdroje jsou poskytovány pouze pro kompilaci a nahrání do zařízení.
Nejste oprávněni upravovat nebo odvozovat/publikovat zdrojový kód tohoto projektu.

KOMERČNÍ POUŽITÍ JE ZAKÁZÁNO.

This software and associated files are a DIY project that is not intended for commercial use.

THE SOFTWARE IS PROVIDED "AS IS", WITHOUT WARRANTY OF ANY KIND, EXPRESS OR IMPLIED.

Sources are only provided for building and uploading to the device.
You are not allowed to modify or fork/publish the source code of this project.

COMMERCIAL USE IS FORBIDDEN.

Běžná nastavení

JAZYK

Můžete si vybrat jazyk, ve kterém se mají nabídky zobrazovat:

// Vyberte jazyk nabídky: ENGLISH/ SPANISH/ CATALAN/ PORTUGUESE/ GERMAN/ FRENCH/ ITALIAN/ NEDERLANDS
#define LANGUAGE | SPANISH

TYP KLÁVESNICE (3x4 nebo 4x4)

Můžeme osadit klávesnici 3x4 nebo 4x4, toto je rozložení kláves:

1 | 2 | 3 | 1 | 2 | 3 | STOP
4 | 5 | 6 | 4 | 5 | 6 | LOCO
7 | 8 | 9 | 7 | 8 | 9 | ↑
MENU | 0 | ENTER | MENU | 0 | ENTER | ↓

Na klávesnici 3x4 nejsou k dispozici některé klávesy, například klávesa 'STOP', která po stisknutí vypne napájení kolejí, takže pokud má být PacoMouse používána jako doplňkové ovládání, nebo když centrála má vlastní STOP tlačítko, je vhodnější ji nainstalovat.

// Pokud používáte klávesnici 4x4, odkomentujte následující řádek
//#define USE_KEYPAD_4x4

CITLIVOST ENKODÉRU

Můžete zvolit vyšší citlivost při pohybu enkodéru, když je třeba dosáhnout vysokých hodnot (jako je výběr rychlosti nebo kontrastu), i když to může ztížit přesné ovládání při pohybu v nabídkách.

// Pro větší citlivost kodéru odkomentujte následující řádek. Nedoporučeno
//#define SENSITIVE | 1

LOKOMOTIVY V ZÁSOBNÍKU

PacoMouse ukládá poslední lokomotivy vybrané během relace, abyste k nim měli rychlý přístup, aniž byste museli zadávat jejich číslo na klávesnici. Zde můžeme vybrat, kolik jich můžete uložit do svého zásobníku.

// Max. počet lokomotiv uložených v zásobníku
#define LOCOS_IN_STACK 24

AKTUÁLNÍ RYCHLOSTNÍ KROK

Můžete si vybrat, zda chcete zobrazit aktuální krok rychlosti vedle ukazatele (vlevo nebo vpravo) nebo Ne.

// Zobrazit rychlostní kroky: LEFT/RIGHT/NONE
#define SHOW_STEPS LEFT

ZOBRAZENÍ FUNKCÍ

Můžete si vybrat, zda chcete funkce zobrazit ve velké nebo malé velikosti: // Vyberte velikost funkcí, které se mají zobrazit: BIG/SMALL
#define FUNC_SIZE | BIG

IKONA VÝHYBKY

Pro zobrazení stavu výhybky si můžete vybrat typ ikony :
// Vybere ikony stavu výhybek: ONLY_TURN/TURN_SIGNAL/BUTTON_IB #define TURNOUT_ICON ONLY_TURN

Možnosti OLED displeje

ŘÍZENÍ OLED DISPLEJE

PacoMouse zobrazuje informace na OLED displeji, který je připojen přes I2C sběrnici. Tyto displeje mají adresu sběrnice (0x3C nebo 0x3D), kterou lze u některých změnit přesunutím odporu.

POZNÁMKA: Na některých displejích sítotisk ukazuje adresu s jinou hodnotou, než kterou je potřeba zadat do config.h (viz obrázek)

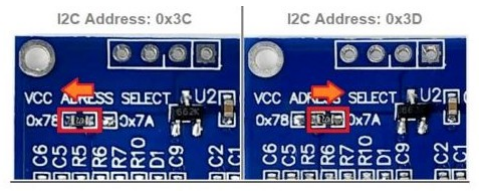
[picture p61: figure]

// I2C adresa OLED displeje (OLED I2C adresa - 0x3D: Adafruit I2C OLED, 0x3C: Clone I2C OLED)
#define I2C_ADDRESS_OLED | 0x3C | // výchozí adresa

TYP OLED DISPLEJE

Displeje OLED používají k provozu specifický řadič, obvykle je to SSD1306 na 0,96" displejích (typ Adafruit), SH1106 na 1,3" displejích nebo SSD1309 na 2,42" displejích. Knihovna SSD1306Ascii.h podporuje první dva ovladače nativně, ale pro správné zobrazení musíme v config.h uvést, jaký typ má náš displej. Různé možnosti by měly vypadat takto:

OLED s ovladačem SSD1306:
// Typ obrazovky 128x64 OLED. Odkomentujte jeden řádek podle vaší obrazovky
#define USE_SSD1306 | 1 | // OLED 0,96"

//#define USE_SH1106 | 1 | // OLED 1,3"
//#define USE_SSD1309 | 1 | // OLED 2,42"

OLED s ovladačem SH1106:
// Typ obrazovky 128x64 OLED. Odkomentujte jeden řádek podle vaší obrazovky
//#define USE_SSD1306 | 1 | // OLED 0,96"
#define USE_SH1106 | 1 | // OLED 1,3"

#define USE_SSD1309 | 1 | // OLED 2,42"

OLED s ovladačem SSD1309:
// Typ obrazovky 128x64 OLED. Odkomentujte jeden řádek podle vaší obrazovky
//#define USE_SSD1306 | 1 | // OLED 0,96"
//#define USE_SH1106 | 1 | // OLED 1,3"
#define USE_SSD1309 | 1 | // OLED 2,42"

Možnosti rozhraní

Rozhraní Loconet
Pokud jsme PacoMouse vyrobili s rozhraním Loconet s Arduino Nano (Uno nebo Pro Mini), musíme tuto možnost vybrat a odkomentovat pouze řádek odpovídající rozhraní Loconet. Není možné používat rozhraní Loconet a Xpressnet současně, ani vybrat Z21, protože používá jinou desku. Různé možnosti by měly vypadat takto:

// Odkomentujte jeden řádek podle použitého rozhraní
#define USE_LOCONET 1 | // Loconet - Arduino Nano

//#define USE_XPRESSNET | 1 | // Xpressnet - Arduino Nano
//#define USE_Z21 | 1 | // Z21 - ESP8266 Wemos D1 mini

Rozhraní Xpressnet
Pokud jsme PacoMouse vyrobili s rozhraním Xpressnet s Arduino Nano (Uno nebo Pro Mini), musíme tuto možnost vybrat a odkomentovat pouze řádek odpovídající rozhraní Xpressnet. Není možné používat rozhraní Loconet a Xpressnet současně, ani vybrat Z21, protože používá jinou desku.
//#define USE_LOCONET | 1 | // Loconet - Arduino Nano
#define USE_XPRESSNET | 1 | // Xpressnet - Arduino Nano

//#define USE_Z21 | 1 | // Z21 - ESP8266 Wemos D1 mini

Rozhraní Z21
Pokud místo Arduino Nano (Uno nebo Pro mini) používáme Wemos D1 mini s ESP8266, který má WiFi připojení pro PacoMouse, musíme tuto možnost vybrat a odkomentovat pouze řádek odpovídající rozhraní Z21. Není možné použít rozhraní Loconet a Xpressnet, protože používají jinou desku.
//#define USE_LOCONET | 1 | // Loconet - Arduino Nano
//#define USE_XPRESSNET | 1 | // Xpressnet - Arduino Nano
#define USE_Z21 | 1 | // Z21 - ESP8266 Wemos D1 mini

I2C EXPANDÉR PRO KLÁVESNICE
ESP8266 (Wemos D1 mini) nemá dostatek pinů pro ovládání klávesnice, OLED a enkodéru, proto je pro připojení klávesnice potřeba I2C expandér s čipem PCF8574. Je nutné uvést adresu I2C sběrnice v závislosti na tom, jak byly nakonfigurovány propojky na desce expandéru.

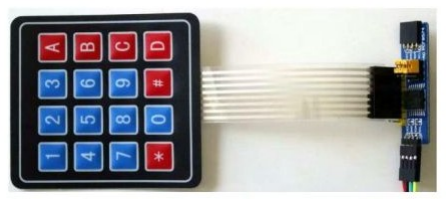
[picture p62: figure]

// I2C adresa PCF8574 pro klávesnici (0x20..0x27)
#define I2C_ADDRESS_KEYPAD | 0x20 | // Klávesnice PCF8574

Programování Arduina

Jakmile jsme otevřeli skicu a aktualizovali možnosti v souboru config.h podle našich preferencí a hardwaru, v Arduino IDE zkontrolujeme, že jsme vybrali desku Arduino, kterou máme, a port, ke kterému je připojena. Možná budeme muset nejdříve nainstalovat ovladač, aby se port, ke kterému je připojen, objevil v seznamu.

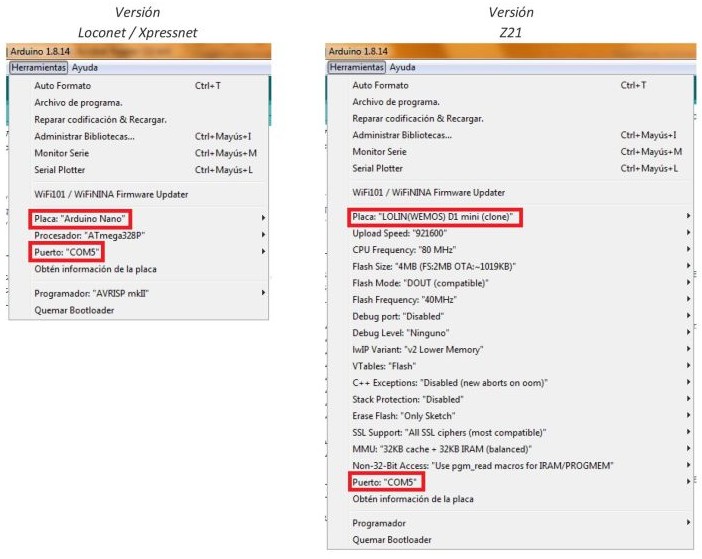
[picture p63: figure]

Pro načtení programu klikneme na tlačítko 'Nahrát' program.


Po zkompilování nám program, pokud vše proběhne v pořádku, oznámí, že byl nahrán.


Příloha IV: Tipy

HARDWAROVÁ KONFIGURACE A TESTOVÁNÍ

Byl přidán malý testovací program, který pomáhá konfigurovat a detekovat problémy se sestavou PacoMouse. Nahrajte program PacoMouse_HW_Test.ino do svého Arduino Nano nebo Wemos D1, otevřete sériový monitor Arduino IDE, vyberte rychlost 115200 baudů a podle výpisů sériového monitoru zkontrolujte jeho sestavení.


PŘI PRVNÍM PŘIPOJENÍ

PacoMouse ukládá různé možnosti zvolené uživatelem do paměti EEPROM ovladače. Při prvním připojení PacoMouse bude paměť EEPROM obsahovat blíže neurčené hodnoty, takže je možné, že některé možnosti nebudou dostupné nebo nebudou použity. Chcete-li to vyřešit, stiskněte klávesu 'MENU' ( na klávesnici '*' ) a vyberte Nastavení, upravte různé možnosti podle svých potřeb. Můžete také nahrát testovací program
PacoMouse_HW_Test.ino a vybrat obnovení paměti EEPROM na výchozí hodnoty.

SPOTŘEBA OLED DISPLEJE

Displeje OLED používají k provozu specifický řadič, obvykle je to SSD1306 na 0,96" displeji (typ Adafruit), SH1106 na 1,3" displeji nebo SSD1309 na 2,42" displeji. Čím větší velikost, tím větší spotřeba. Použitá sběrnice (Loconet/Xpressnet) nepředpokládá spotřebu pro větší množství ovládacích prvků, při vyšší spotřebě by muselo být zajištěno připojení samostatného napájení ke konektorům pro sběrnici. Ve verzi Z21 spotřeba přímo ovlivňuje výdrž baterie. Snížením kontrastu se spotřeba poněkud sníží.

Typ displeje | Průměrná spotřeba (Kontrast: 20) | Průměrná spotřeba (Kontrast: 100) | Maximální spotřeba
SSD1306 (0,96") | 4 mA | 5 mA | 15 mA
SH1106 (1,3") | 6 mA | 8 mA | 24 mA
SSD1309 (2,42") | 28 mA | 35 mA | 104 mA

ENKODÉR

Levné enkodéry bývají poměrně nevyzpytatelné, nejlepší je modul, který již obsahuje odpory a kondenzátory, aby nedocházelo k překmitům. Jeho spolehlivost můžete dále zlepšit přidáním dvojice 100nF kondenzátorů přímo na piny kodéru. (Mezi GND a výstupy)

JAZYK

Pokud se váš jazyk neobjeví mezi možnostmi jazyka v souboru config.h PacoMouse nebo obsahuje chyby, můžete použít jeden ze stávajících jako šablonu pro jeho přizpůsobení. Každý jazyk má soubor s příponou .h, kde se nacházejí všechny texty, které lze zobrazit. Upozorňujeme, že je použito písmo Arial_bold_14 z knihovny SSD1306Ascii , takže jsou k dispozici pouze znaky ASCII 32 až 127. Změňte pouze ty a nepřekračujte maximální délku 14 znaků. Pošlete kopii textů Pacovi (https://usuaris.tinet.cat/fmco) pro zařazení mezi nové verze.

RYCHLÉ HODINY

Rychlé hodiny se zobrazí, pokud jsou v centrále aktivovány. Ve verzi Xpressnet jsou podporovány pouze v případě, že se připojíte k LZV200 v4 nebo Z21 s FW1.43. Ve verzi Z21 pouze při připojení k Z21 s FW1.43. Ve verzi Loconet se zobrazí, pokud centrála podporuje rychlé hodiny ve slotu 123 (Intellibox II, DR5000 atd.).

STAV PŘÍSLUŠENSTVÍ TELEFONNÍHO SEZNAMU

Centrála Fleischmann Twin Center v1.100 neukládá stav příslušenství, pokud není registrováno, takže může být ovlivněna činnost telefonního seznamu v nabídce Dispatch (Odeslání). Všechna čísla musí být zaregistrována v telefonním seznamu každé myši PacoMouse. Chcete-li to provést, zadejte konfiguraci Twin Center stisknutím menu a poté mode, pomocí šipky vyhledejte možnost Acess.Setting, zadejte možnost a vyberte Virtuální adresy a zaregistrujte veškeré příslušenství z telefonního seznamu.

Například pro číslo 701:

VAdd | DAdd | Out | DF
.701 | 175 | 2 | D

DAdd = VAdd / 4
Out = VAdd - (DAdd * 4) + 1

PŘIJÍMEJTE HOVORY Z TWIN CENTER

Centrála Fleischmann Twin Center v1.100 stav příslušenství neukládá a změna se ani nezobrazí na displeji, pokud nejsou v centrále registrovány, takže nemůžete volat z PacoMouse do TwinCenter nebo jiné PacoMouse s možností volání z nabídky Dispatch (Odeslání).

Hovory z TwinCenter však lze přijímat, ale pouze ručně, jde o slepý proces, protože neexistuje žádné upozornění, že hovor byl přijat nebo odmítnut.

Telefon PacoMouse : | 701
Telefonní stanice A: | 702
Twin Center řídí lokomotivu | 276

Přeneste lokomotivu 276 z Twin Center do PacoMouse prostřednictvím volání a přijměte ji.
TWIN CENTER | PacoMouse
Akce uživatele | Popis | Akce uživatele | Automatická akce
Příslušenství 702 ZELENÁ | Zvedněte telefonní stanici A
Příslušenství 701 ZELENÁ | Zavolejte PacoMouse
ENTER(Přijmout hovor) | Příslušenství 702 ČERVENÁ
#lok C #lok | Odeslání PUT lokomotivy 276

Příslušenství 701 ČERVENÁ | Ukončit hovor

Odmítnout hovor


TWIN CENTER | PacoMouse
Akce uživatele | Popis | Akce uživatele | Automatická akce
Příslušenství 702 ZELENÁ | Zvedněte telefonní stanici A
Příslušenství 701 ZELENÁ | Zavolejte PacoMouse
MENU (Odmítnout hovor) | Příslušenství 701
ČERVENÁ
Řídit
Vybrat lokomotivu
Odeslání
Výhybky
Příslušenství 702 ČERVENÁ Zavěste telefonní stanici A

Příloha V: Pro netrpělivé (RTFM: Read The Fucking Manual)

Pokud jste návod spustili zde, jistě jste PacoMouse sestavili, nahráli program, zapojili k centrále a nefunguje tak, jak očekáváte. Zde jsou odpovědi na některé vaše otázky, vše je již vysvětleno v návodu, ale zde je shrnutí. Doporučuji také, přečíst si přílohu IV: Tipy.

FUNGUJÍ JEN NĚKTERÁ MENU

Zdá se, že je vše funkční, ale některé klávesy nefungují a mohu vstoupit pouze do některých nabídek, jako je jízda a nastavení.

Stiskněte klávesu 'MENU' ( na klávesnici '*') a vyberte Nastavení, enkodérem vyhledejte možnost LOCK a stiskněte enkodér, nyní vyberte jednu z možností označených enkodérem a zrušte zaškrtnutí stisknutím enkodéru. Opakujte, dokud nezrušíte zaškrtnutí všech tří možností.

NENÍ MOŽNOST ZMĚNY V NASTAVENÍ

Zkontrolujte, zda není aktivována žádná možnost LOCK, pokud ano, postupujte krok za krokem podle předchozí otázky. Velký kurzor vám říká, že volbu můžete vybrat, pokud se objeví malý kurzor, vyberte nejprve nadřazenou část, která je napsána velkými písmeny a pak budete mít velký kurzor pro změnu možnosti.

RYCHLOST NEJDE K NULE A LOKOMOTIVA JEDE VELMI POMALU

Je zvolen režim posunu. Stisknutím enkodéru lokomotivu zastavíte, dalším stisknutím změníte směr.

Stiskněte klávesu 'MENU' ('*' na klávesnici) a vyberte Konfigurace, enkodérem vyhledejte možnost STOP MODE a stiskněte enkodér, nyní vyberte možnost Posun (Shunting) a zrušte zaškrtnutí stisknutím enkodéru.

KODÉR FUNGUJE OPAČNĚ

Existuje mnoho typů kodérů a nemusí být zapojeny stejně, zaměňte vodiče S1/CLK a S2/DT.

KLÁVESY NEJSOU NA SVÉM MÍSTĚ

Klávesnice PIN | Klávesy | Arduino PIN
R1: Řada 1 | 1 2 3 A | D3
R2: Řada 2 | 4 5 6 B | D4
R3: Řada 3 | 7 8 9 C | D5
R4: Řada 4 | * 0 # D | D6
C1: Sloupec 1 | 1 4 7 * | D9
C2: Sloupec 2 | 2 5 8 0 | D10
C3: Sloupec 3 | 3 6 9 # | D11
C4: Sloupec 4 | A B C D | A0


Podle tohoto přiřazení pinů připojte klávesnici, můžete použít program PacoMouse_HW_Test.ino ve složce projektu nebo pokud víte, co děláte, upravit definici pinů v souboru config.h.

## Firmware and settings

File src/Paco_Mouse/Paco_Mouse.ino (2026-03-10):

/*    Paco Mouse -- F. Cañada 2022-2025 --  https://usuaris.tinet.cat/fmco/

      This software and associated files are a DIY project that is not intended for commercial use.
      This software uses libraries with different licenses, follow all their different terms included.

      THE SOFTWARE IS PROVIDED "AS IS", WITHOUT WARRANTY OF ANY KIND, EXPRESS OR IMPLIED.

      Sources are only provided for building and uploading to the device.
      You are not allowed to modify the source code or fork/publish this project.
      Commercial use is forbidden.

       v0.1     08oct22   Start writting code
       v0.2     12oct22   First test with DR5000
       v0.3     15oct22   Removed LocoNetThrottleClass use
       v0.4     16oct22   Loco operations working
       v0.5     17oct22   Added fast clock catch & loco stack
       v0.6     21oct22   Added Dispatching
       v0.7     23oct22   Added Config options & turnouts
       v0.8     28oct22   Added secondary OLED (Accesibility).Modified turnout input, minor updates in Loconet
       v0.9     30oct22   Added turntable
       v0.10    06nov22   Added Program/Read CV & Language text files.
       v0.11    27nov22   Added shunting mode & Xpressnet version
       v0.12    04dec22   Added Z21 version with Wemos D1 mini (ESP8266)
       v0.13    11dec22   Added Lock loco selection, turnouts & prog options (Club Mode)
       v0.14    27dec22   Up to 28 functions
       v0.15    06jan23   Z21 max short address & Games
       v0.16    10jan23   Added shuttle train
       v0.17    26oct23   Added Fast Clock for Z21 FW 1.43 & big clock display. Added SSD1309 OLED support. Removed secondary OLED (Use 2.4" OLED for accesibility).
       v0.18    27oct23   Added PhoneBook for Loconet
       v0.19    01nov23   Added LNCV programming. Corrected minor bugs.
       v0.20b   05nov23   Withrottle version. Doesn't works as expected. Removed
       v0.21    03feb24   Option IB2 programming packets. Screen update IB function change. Correct F13..F20 for MM. Changed ISR.      Not implemented: Virtual PBX for Loconet.Transfer of library in Multimaus. Detect Loconet command station.
       v0.22    12mar24   Improvements on menu displacement and encoder reading
       v0.23    23mar24   Change arrows behaviour in turnout menu. Added game Paku Paku. Corrected bug that affects menu when updating speed. Push readed loco address in stack
       v0.24    28apr24   Added show speed step. Option to show F0-F8 instead of F0-F4
       v0.25    09may24   Change options to show Big or Small functions and turnout icon. Correct bug in Loconet driving 14 steps. Added OPC_IMM_PACKET function decoding. Correct bug in xpressnet shuttle contacts reading.
       v0.26    20jul24   Added support for ECoS and Märklin CS1. Added support for touchpad with TTP229BSF. Added Pong game. Added Loco button double press goes to turnouts. Corrected minor bugs.
       v0.27    20dec24   Added EEPROM disk. Added Automation. Added CV bits programming. Corrected minor bugs.
       v0.28    26jan25   Using modified and retailed version of Loconet.h library to reduce 0.5K the memory size to support Uhlenbrock programming (30488+678 to 29962+710). Added WiFi version with Loconet over TCP/IP (LBserver & Binary).
       v0.29    18feb25   Added support for Xpressnet WiFi. Added set fast clock option.
       v0.30    30jun25   Corrected bugs in saving automation, Loconet & Z21. Improved support of SSD1309 OLED and Daisy II WLAN.Added support for direction switch 3 positions: FWD(ON)-(OFF)-(ON)REV. Added Czech language.
       v0.31    08mar26   Corrected bug using 3 position switch on ESP8266 that doesn't overides battery voltage read function.
*/

// Paco Mouse program version
#define VER_H "0"
#define VER_L "31"


//#define DEBUG                                               // Descomentar para mensajes de depuracion

#define ENGLISH       1                                     // Idiomas
#define SPANISH       2
#define CATALAN       3
#define PORTUGUESE    4
#define GERMAN        5
#define FRENCH        6
#define ITALIAN       7
#define NEDERLANDS    8
#define CZECH         9

#define NONE          0                                     // Posicion pasos
#define LEFT          1
#define RIGHT         2

#define BIG           0                                     // Tamaño funciones
#define SMALL         1

#define ONLY_TURN     0                                     // Estado desvios
#define TURN_SIGNAL   1
#define BUTTON_IB     2

#define XNET          0                                     // Version hardware de PacoMouse
#define LNET          1
#define Z21           2
#define ECOS          3

#define SSD1306       0                                     // Tipo de controlador de pantalla OLED
#define SH1106        1
#define SSD1309       2

#define KEYPAD        0                                     // Tipo de teclado, normal o tactil
#define TOUCHPAD      1

#define BUTTON_ENC    0                                     // Cambio direccion con boton encoder o conmutador 3 posiciones (ON-OFF-ON)
#define SWITCH_3P     1

// Libraries

#include "config.h"                                         // Paco Mouse config file
#ifdef USE_Z21
#include <ESP8266WiFi.h>                                    // Arduino ESP8266 core                         v3.1.2
#include <WiFiUdp.h>
#include <Wire.h>
#ifndef USE_TTP229
#include <Keypad_I2C.h>                                     // https://github.com/joeyoung/arduino_keypads  v3.0.0
#endif
#endif
#ifdef USE_ECOS
#include <ESP8266WiFi.h>                                    // Arduino ESP8266 core                         v3.0.2
#include <Wire.h>
#ifndef USE_TTP229
#include <Keypad_I2C.h>                                     // https://github.com/joeyoung/arduino_keypads  v3.0.0
#endif
#endif
#ifdef USE_LOCONET
#include "lnet.h"
#ifdef USE_LNWIFI
#include <ESP8266WiFi.h>                                    // Arduino ESP8266 core                         v3.1.2
#include <Wire.h>
#ifndef USE_TTP229
#include <Keypad_I2C.h>                                     // https://github.com/joeyoung/arduino_keypads  v3.0.0
#endif
#endif
#ifdef USE_LNWIRE
#include <avr/io.h>
#include <avr/interrupt.h>
#endif
#endif
#ifdef USE_XPRESSNET
#ifdef USE_XNWIRE
#include <avr/interrupt.h>
#endif
#ifdef USE_XNWIFI
#include <ESP8266WiFi.h>                                    // Arduino ESP8266 core                         v3.1.2
#include <Wire.h>
#ifndef USE_TTP229
#include <Keypad_I2C.h>                                     // https://github.com/joeyoung/arduino_keypads  v3.0.0
#endif
#endif
#endif
#ifdef USE_TTP229
#include "keypadTTP229.h"
#else
#include <Keypad.h>                                         // https://github.com/Chris--A/Keypad           v3.1.1
#endif
#include <SSD1306Ascii.h>                                   // https://github.com/greiman/SSD1306Ascii      v1.3.5
#if defined(USE_LNWIRE) || defined(USE_XNWIRE)
#include <SSD1306AsciiAvrI2c.h>
#endif
#if defined(USE_Z21) || defined(USE_ECOS) || defined(USE_LNWIFI) || defined(USE_XNWIFI)
#include "SSD1306AsciiWire.h"
#endif
#include <EEPROM.h>


#include "Sym_16x16.h"                                      // Paco Mouse fonts
#include "Sym_Proportional.h"
#include "Num_15x31.h"
#include "Num_32x48.h"
#if  (LANGUAGE == ENGLISH)                                  // Paco Mouse language
#include "english.h"
#endif
#if  (LANGUAGE == SPANISH)
#include "spanish.h"
#endif
#if  (LANGUAGE == CATALAN)
#include "catalan.h"
#endif
#if  (LANGUAGE == PORTUGUESE)
#include "portuguese.h"
#endif
#if  (LANGUAGE == GERMAN)
#include "german.h"
#endif
#if  (LANGUAGE == FRENCH)
#include "french.h"
#endif
#if  (LANGUAGE == ITALIAN)
#include "italian.h"
#endif
#if  (LANGUAGE == NEDERLANDS)
#include "nederlands.h"
#endif
#if  (LANGUAGE == CZECH)
#include "czech.h"
#endif

#ifdef DEBUG
char output[80];

#define DEBUG_MSG(...)  snprintf(output,80, __VA_ARGS__ );   \
  Serial.println(output);
#else
#define DEBUG_MSG(...)
#endif


////////////////////////////////////////////////////////////
// ***** TECLADO *****
////////////////////////////////////////////////////////////

enum teclas {K_NONE, K_NUM0, K_NUM1, K_NUM2, K_NUM3, K_NUM4, K_NUM5, K_NUM6, K_NUM7, K_NUM8, K_NUM9, K_MENU, K_ENTER, K_A, K_B, K_C, K_D};

#define FILAS 4                                             // Filas y Columnas de la matriz del teclado

#ifdef  USE_TTP229

#ifdef REAR_TOUCH
char keys[16] = {K_A, K_NUM3, K_NUM2, K_NUM1, K_B, K_NUM6, K_NUM5, K_NUM4, K_C, K_NUM9, K_NUM8, K_NUM7, K_D, K_ENTER, K_NUM0, K_MENU};
#else
char keys[16] = {K_NUM1, K_NUM2, K_NUM3, K_A, K_NUM4, K_NUM5, K_NUM6, K_B, K_NUM7, K_NUM8, K_NUM9, K_C, K_MENU, K_NUM0, K_ENTER, K_D};
#endif

Keypad_TTP229 keypad (keys, pinTOUCH_SCL, pinTOUCH_SDO);

#else

#ifdef USE_KEYPAD_4x4
#define COLUMNAS 4

char keys[FILAS][COLUMNAS] = {                              // Disposicion de las teclas
  {K_NUM1, K_NUM2, K_NUM3, K_A},
  {K_NUM4, K_NUM5, K_NUM6, K_B},
  {K_NUM7, K_NUM8, K_NUM9, K_C},
  {K_MENU, K_NUM0, K_ENTER, K_D}
};

byte filaPins[FILAS]   = {pinFILA1, pinFILA2, pinFILA3, pinFILA4};                // pins de las filas del teclado
byte colPins[COLUMNAS] = {pinCOLUMNA1, pinCOLUMNA2, pinCOLUMNA3, pinCOLUMNA4};    // pins de las columnas del teclado
#else
#define COLUMNAS 3

char keys[FILAS][COLUMNAS] = {                              // Disposicion de las teclas
  {K_NUM1, K_NUM2, K_NUM3},
  {K_NUM4, K_NUM5, K_NUM6},
  {K_NUM7, K_NUM8, K_NUM9},
  {K_MENU, K_NUM0, K_ENTER}
};

byte filaPins[FILAS]   = {pinFILA1, pinFILA2, pinFILA3, pinFILA4};                // pins de las filas del teclado
byte colPins[COLUMNAS] = {pinCOLUMNA1, pinCOLUMNA2, pinCOLUMNA3};                 // pins de las columnas del teclado
#endif

#if defined(USE_LNWIRE) || defined(USE_XNWIRE)
Keypad keypad = Keypad( makeKeymap(keys), filaPins, colPins, FILAS, COLUMNAS);
#endif
#if defined(USE_Z21) || defined(USE_ECOS) || defined(USE_LNWIFI) || defined(USE_XNWIFI)
Keypad_I2C keypad ( makeKeymap(keys), filaPins, colPins, FILAS, COLUMNAS, I2C_ADDRESS_KEYPAD);
#endif
#endif

byte keyValue;                                              // valor tecla pulsada
bool keyOn;

byte dirValue;                                              // valor interruptor direccion
bool dirChange;

////////////////////////////////////////////////////////////
// ***** ENCODER *****
////////////////////////////////////////////////////////////

byte outA, outB, copyOutA, copyOutB;                        // encoder input used by ISR
volatile byte encoderValue;                                 // encoder shared values (ISR & program)
volatile byte encoderMax;
volatile bool encoderChange;

byte statusSwitch;
bool switchOn;
const unsigned long timeoutButtons = 50;                    // temporizador antirebote
unsigned long timeButtons;


////////////////////////////////////////////////////////////
// ***** OLED *****
////////////////////////////////////////////////////////////

#if defined(USE_LNWIRE) || defined(USE_XNWIRE)
SSD1306AsciiAvrI2c oled;                                    // Pantalla principal
AvrI2c i2c;
#endif
#if defined(USE_Z21) || defined(USE_ECOS) || defined(USE_LNWIFI) || defined(USE_XNWIFI)
SSD1306AsciiWire oled;                                      // Pantalla principal
#endif

enum Screen { SCR_LOGO, SCR_ENDLOGO, SCR_MENU, SCR_SPEED, SCR_LOCO, SCR_DISPATCH, SCR_TURNOUT, SCR_ERROR, SCR_TURNTABLE,
              SCR_CV, SCR_CFG, SCR_WAIT, SCR_SELCV, SCR_DIRCV, SCR_SSID, SCR_PASSWORD, SCR_IP_ADDR, SCR_PORT, SCR_GAME,
              SCR_SHUTTLE, SCR_PHONE, SCR_STATION, SCR_PHONEBOOK, SCR_PHONE_NUM, SCR_LNCV, SCR_DEVICE,
              SCR_AUTO_SELECT, SCR_AUTO_NAME, SCR_AUTO_EDIT, SCR_AUTO_DELETE, SCR_TIME,
            };

#ifdef USE_LOCONET
enum Option { OPT_SPEED, OPT_LOCO, OPT_DISPATCH, OPT_TURNOUT, OPT_TURNTABLE, OPT_SHUTTLE,
#ifdef USE_AUTOMATION
              OPT_AUTOMATION,
#endif
              OPT_CV, OPT_CFG, MENU_ITEMS
            };
#endif
#ifdef USE_XPRESSNET
enum Option { OPT_SPEED, OPT_LOCO, OPT_TURNOUT, OPT_TURNTABLE, OPT_SHUTTLE,
#ifdef USE_AUTOMATION
              OPT_AUTOMATION,
#endif
              OPT_CV, OPT_CFG, MENU_ITEMS
            };
#endif
#ifdef USE_Z21
enum Option { OPT_SPEED, OPT_LOCO, OPT_TURNOUT, OPT_TURNTABLE, OPT_SHUTTLE,
#ifdef USE_AUTOMATION
              OPT_AUTOMATION,
#endif
              OPT_CV, OPT_CFG, MENU_ITEMS
            };
#endif
#ifdef USE_ECOS
enum Option { OPT_SPEED, OPT_LOCO, OPT_TURNOUT, OPT_TURNTABLE, OPT_SHUTTLE,
#ifdef USE_AUTOMATION
              OPT_AUTOMATION,
#endif
              OPT_CV, OPT_CFG, MENU_ITEMS
            };
#endif

enum Err {ERR_OFF, ERR_STOP, ERR_SERV};
enum PosDigit {UNITS, TENS, CENTS, THOUSANDS};

bool updateOLED, updateAllOLED, updateExtraOLED;
byte scrOLED, errOLED, optOLED, cfgOLED, prgOLED, fileOLED;
byte scrSpeed, scrFunc;
byte scrHour, scrMin, scrRate, scrPosTime;
byte clockHour, clockMin, clockRate;
unsigned long clockTimer, clockInterval;                    // Internal fast clock calculation
unsigned int scrLoco, scrPort;
unsigned long timeOLED, timeoutOLED;
#define ONE_DAY 86400000UL

union numInput {                                            // Entrada numerica 4 digitos
  byte digit[4];
  unsigned long packed;
} myInput;

byte diezMiles;

const byte posPuntos [8][2] = {{80, 4}, {64, 6}, {48, 6}, {32, 4}, {32, 2}, {48, 0}, {64, 0}, {80, 2}};
byte estadoPuntos;
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
void loop() {
#ifdef USE_LOCONET
  lnetProcess();                                            // Loconet comunications
#ifdef USE_PHONE
  doPhoneLine();
#endif
#endif
#ifdef USE_XPRESSNET
  xpressnetProcess();                                       // Xpressnet comunications
#endif
#ifdef USE_Z21
  z21Process();                                             // Z21 comunications
#endif
#ifdef USE_ECOS
  ECoSProcess();                                            // ECoS comunications
#endif
  hidProcess();                                             // HID: Human Interface Device
  if (activeShuttle)
    mainShuttle();                                          // Shuttle train
#ifdef USE_AUTOMATION
  processAutomation();
#endif
}


////////////////////////////////////////////////////////////
// ***** SOPORTE *****
////////////////////////////////////////////////////////////

void initVariables() {
  byte pos;
#if defined(USE_Z21) || defined(USE_ECOS) || defined(USE_LNWIFI) || defined(USE_XNWIFI)
  EEPROM.begin(EEPROM_SIZE);
#endif
  timeOLED = millis();
  keypad.setDebounceTime(20);
  encoderValue = 0;
  encoderMax = 2;
#if (CHANGE_DIR == SWITCH_3P)
  dirValue = readDirSwitch();
#endif
  scrOLED = SCR_LOGO;
  optOLED = OPT_SPEED;
  prgOLED = PRG_PTRK;
  cfgOLED = CFG_CONTR;
  estadoPuntos = 0;
#if  (FUNC_SIZE == BIG)
  scrFunc = FNC_0_4;
#endif
#if  (FUNC_SIZE == SMALL)
  scrFunc = FNC_0_9;
#endif
  scrSpeed = 0;
  myTurnout = 1;
  myPosTurnout = NO_MOVIDO;
  lastPosTurnout = DESVIADO;
  accEnviado = false;
  CVdata = 0;                                               // CV programming
  CVaddress = 0;
  modeProg = false;
  progFinished = false;
  progStepCV = PRG_IDLE;
  clockRate = 0;                                            // fast clock internal
  clockHour = 0;
  clockMin = 0;
  clockInterval = ONE_DAY;
  showBigClock = false;
  for (pos = 0; pos < LOCOS_IN_STACK; pos++)                // borra loco stack
    locoStack[pos] = 0;
#ifdef USE_ECOS
  pos = readEEPROM (EE_ADRH);                               // Ultima locomotora controlada
  myLocoID = readEEPROM (EE_ADRL) + (pos << 8);
  pushLoco(myLocoID);
#else
  myLoco.adr[1] = readEEPROM (EE_ADRH);                     // Ultima locomotora controlada
  myLoco.adr[0] = readEEPROM (EE_ADRL);
  checkLocoAddress();
  pushLoco(myLoco.address);
#endif
  pos = readEEPROM(EE_CONTRAST);
#ifdef USE_SSD1309
  cfgMenu[CFG_CONTR_VAL].value = (pos > 100) ? 100 : pos;
#else
  cfgMenu[CFG_CONTR_VAL].value = pos;                       // Configuracion menu
#endif
  stopMode = readEEPROM(EE_STOP_MODE);
  cfgMenu[CFG_STOP_VEL0].value = (stopMode == 0) ? 1 : 0;
  cfgMenu[CFG_STOP_EMERG].value = (stopMode != 0) ? 1 : 0;
  shuntingMode = (readEEPROM(EE_SHUNTING) > 0) ? true : false;
  cfgMenu[CFG_SHUNTING].value = (shuntingMode == true) ? 1 : 0;
  changeCfgOption = false;
  modeTurntable = false;                                    // Turntable options
  destTrack = 1;
#if defined(USE_XPRESSNET) || defined(USE_Z21)
  baseOffset = (readEEPROM(EE_ROCO) > 0) ? 4 : 0;
  cfgMenu[CFG_TT_ROCO].value = (baseOffset == 0) ? 0 : 1;
#endif
  typeTurntable = readEEPROM(EE_TT_TYPE);
  switch (typeTurntable) {
    case TT_7686_KB14:
      cfgMenu[CFG_TT_KB14].value = 1;
      cfgMenu[CFG_TT_KB15].value = 0;
      cfgMenu[CFG_TT_TCTRL].value = 0;
      baseAdrTurntable = 209;
      break;
    case TT_F6915:
      cfgMenu[CFG_TT_KB14].value = 0;
      cfgMenu[CFG_TT_KB15].value = 0;
      cfgMenu[CFG_TT_TCTRL].value = 1;
      baseAdrTurntable = 200;
      break;
    default:
      cfgMenu[CFG_TT_KB14].value = 0;
      cfgMenu[CFG_TT_KB15].value = 1;
      cfgMenu[CFG_TT_TCTRL].value = 0;
      baseAdrTurntable = 225;
      break;
  }
#ifdef USE_SET_TIME
#ifdef USE_LOCONET
  cfgMenu[CFG_SYNC].value = 0;
#endif
#endif
  lockOptions = readEEPROM(EE_LOCK);
  cfgMenu[CFG_LOCK_LOCO].value = (bitRead(lockOptions, LOCK_SEL_LOCO)) ? 1 : 0;
  cfgMenu[CFG_LOCK_TURNOUT].value = (bitRead(lockOptions, LOCK_TURNOUT)) ? 1 : 0;
  cfgMenu[CFG_LOCK_PROG].value = (bitRead(lockOptions, LOCK_PROG)) ? 1 : 0;
  activeShuttle = false;                                    // shuttle
  shuttleConfig = false;
  suttleCurrentState = DEACTIVATED;
  Shuttle.moduleA = readEEPROM (EE_MOD_A);
  Shuttle.inputA = readEEPROM (EE_CONT_A);
  Shuttle.moduleB = readEEPROM (EE_MOD_B);
  Shuttle.inputB = readEEPROM (EE_CONT_B);
  Shuttle.time = readEEPROM (EE_TIME);
#ifdef USE_AUTOMATION
  initAutomation();
  fileCount = getFileCount();
  fileOLED = 0;
#endif
#ifdef USE_LOCONET
  typeCmdStation = readEEPROM(EE_CMD_STA);
  cfgMenu[CFG_CMD_DR].value = (typeCmdStation == CMD_DR) ? 1 : 0;
  cfgMenu[CFG_CMD_ULI].value = (typeCmdStation == CMD_ULI) ? 1 : 0;
  cfgMenu[CFG_CMD_DIG].value = (typeCmdStation > CMD_ULI) ? 1 : 0;
  mySlot.num = 0;
  mySlot.trk = 0x01;                                        // Power on
  doDispatchGet = false;
  doDispatchPut = false;
  accStateReq = false;
  lnetProg = false;
  ulhiProg = UHLI_PRG_END;
#ifdef USE_PHONE
  for (pos = 0; pos < MAX_STATION; pos++)                   // lee listin telefonico
    phoneBook[pos] = readEEPROM(EE_PHONE_ME + pos);
  myStation = phoneBook[PHONE_ME] + PHONE_BASE;
  lastStationPickUp = 0;
  //phonePBX = 0;                                             // all RED
  doPhoneStatus = false;
  phonePhase = PHONE_IDLE;
#endif
#if defined(USE_LNWIFI)
  EEPROM.get (EE_WIFI, wifiSetting);
  if (wifiSetting.ok != 0x464D) {
    snprintf (wifiSetting.ssid, 32, "");
    snprintf (wifiSetting.password, 64, "12345678");
    wifiSetting.CS_IP = IPAddress(192, 168, 0, 111);
    wifiSetting.port = 1234;
    wifiSetting.type = true;
    wifiSetting.ok = 0x464D;
    EEPROM.put(EE_WIFI, wifiSetting);
    EEPROM.commit();
    //DEBUG_MSG("Set default WiFi");
  }
  cfgMenu[CFG_WIFI_PORT].value = wifiSetting.port;
  cfgMenu[CFG_BINARY].value = (wifiSetting.type == false) ? 1 : 0;
  cfgMenu[CFG_LBSERVER].value = (wifiSetting.type == true) ? 1 : 0;
  isLBServer = wifiSetting.type;
#endif
#endif
#ifdef USE_XPRESSNET
#if defined(USE_XNWIRE)
  miDireccionXpressnet = readEEPROM(EE_XBUS);
  if ((miDireccionXpressnet > 31) || (miDireccionXpressnet == 0)) {   // Si no es valido inicializa direccion bus en EEPROM
    miDireccionXpressnet = DEFAULT_XNET_ADR;
    updateEEPROM (EE_XBUS, miDireccionXpressnet);
  }
  cfgMenu[CFG_XBUS_DIR].value = miDireccionXpressnet;
#endif
#if defined(USE_XNWIFI)
  EEPROM.get (EE_WIFI, wifiSetting);
  if (wifiSetting.ok != 0x464D) {
    snprintf (wifiSetting.ssid, 32, "");
    snprintf (wifiSetting.password, 64, "12345678");
    wifiSetting.CS_IP = IPAddress(192, 168, 0, 200);
    wifiSetting.ok = 0x464D;
    EEPROM.put(EE_WIFI, wifiSetting);
    EEPROM.commit();
    //DEBUG_MSG("Set default WiFi");
  }
#endif
  mySteps = bit(2);                                         // default 128 steps
  csStatus = csNormalOps;                                   // Power on
  infoTimer = millis();
  getResultsSM = false;
  askMultimaus = false;
  highVerMM = 0;
  lowVerMM = 0;
#endif
#ifdef USE_Z21
  lowBATT = false;
#if (CHANGE_DIR == BUTTON_ENC)
  battery = ESP.getVcc ();                                  // Read VCC voltage
#endif
  infoTimer = millis();
  pingTimer = 0;
  waitResultCV = false;
  shortAddress = readEEPROM(EE_SHORT);
  if ((shortAddress != 99) && (shortAddress != 127))
    shortAddress = 99;
  cfgMenu[CFG_SHORT_99].value = (shortAddress == 99) ? 1 : 0;
  cfgMenu[CFG_SHORT_127].value = (shortAddress == 127) ? 1 : 0;
  EEPROM.get (EE_WIFI, wifiSetting);
  if (wifiSetting.ok != 0x464D) {
    snprintf (wifiSetting.ssid, 32, "");
    snprintf (wifiSetting.password, 64, "12345678");
    wifiSetting.CS_IP = IPAddress(192, 168, 0, 111);
    wifiSetting.ok = 0x464D;
    EEPROM.put(EE_WIFI, wifiSetting);
    EEPROM.commit();
    //DEBUG_MSG("Set default WiFi");
  }
#endif
#ifdef USE_ECOS
  lowBATT = false;
#if (CHANGE_DIR == BUTTON_ENC)
  battery = ESP.getVcc ();                                  // Read VCC voltage
#endif
  infoTimer = millis();
  timeout = millis();
  csStatus = 0;                                             // Stop
  typeCmdStation = T_ECOS;
  requestedCV = false;
  msgDecodePhase = MSG_WAIT;
  EEPROM.get (EE_WIFI, wifiSetting);
  if (wifiSetting.ok != 0x464D) {
    snprintf (wifiSetting.ssid, 32, "");
    snprintf (wifiSetting.password, 64, "12345678");
    wifiSetting.CS_IP = IPAddress(192, 168, 0, 100);
    wifiSetting.ok = 0x464D;
    EEPROM.put(EE_WIFI, wifiSetting);
    EEPROM.commit();
    //DEBUG_MSG("Set default WiFi");
  }
  clearRosterList();
  //myLocoID = 0;
#endif
}
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

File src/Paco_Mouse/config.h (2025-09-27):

/*    Paco Mouse -- F. Cañada 2022-2025 --  https://usuaris.tinet.cat/fmco/
*/


////////////////////////////////////////////////////////////
// ***** USER OPTIONS *****
////////////////////////////////////////////////////////////

// Seleccione el idioma de los menus - Select menu language: ENGLISH/SPANISH/CATALAN/PORTUGUESE/GERMAN/FRENCH/ITALIAN/NEDERLANDS/CZECH
#define LANGUAGE                  SPANISH


// Selecione la version hardware de PacoMouse - Select the hardware version of PacoMouse: XNET/LNET/Z21/ECOS
#define HW_VERSION                XNET


// Seleccione el chip controlador del display 128x64 OLED - Select the 128x64 OLED display controller chip:  SSD1306/SH1106/SSD1309
#define OLED_CHIP                 SSD1306


// Direccion I2C del display OLED - I2C address of the OLED display (OLED I2C address - 0x3D: Adafruit I2C OLED, 0x3C: Clone I2C OLED)
#define I2C_ADDRESS_OLED          0x3C


// Seleccione el tipo de teclado - Select the type of keypad: KEYPAD/TOUCHPAD
#define KEYPAD_TYPE               KEYPAD


// Direccion I2C del PCF8574 para el keypad - I2C address of the PCF8574 for keypad (0x20..0x27)
#define I2C_ADDRESS_KEYPAD        0x20


// Descomentar la siguiente linea si se usa el touchpad TTP229 por detras - Uncomment next line if using rear side of touchpad TTP229
#define REAR_TOUCH                1


// Selecion tipo cambio direccion - Select change direction type: BUTTON_ENC/SWITCH_3P
#define CHANGE_DIR                BUTTON_ENC


// Mostrar pasos de velocidad - Show speed steps: LEFT/RIGHT/NONE
#define SHOW_STEPS                RIGHT


// Seleccione tamaño de las funciones a mostrar - Select size of functions: BIG/SMALL
#define FUNC_SIZE                 SMALL


// Selecciona iconos estado desvio - Select turnout status icons: ONLY_TURN/TURN_SIGNAL/BUTTON_IB
#define TURNOUT_ICON              TURN_SIGNAL


// Max. locomotoras guardadas en stack - Max. locomotives saved in stack:
#define LOCOS_IN_STACK            24


/*      Keypad 3x4                      Keypad 4x4

    |-----+-----+-----|         |-----+-----+-----+-----|
    |     |     |     |         |     |     |     |     |
    |  1  |  2  |  3  |         |  1  |  2  |  3  |STOP |
    |     |     |     |         |     |     |     |     |
    |-----+-----+-----|         |-----+-----+-----+-----|
    |     |     |     |         |     |     |     |     |
    |  4  |  5  |  6  |         |  4  |  5  |  6  |LOCO |
    |     |     |     |         |     |     |     |     |
    |-----+-----+-----|         |-----+-----+-----+-----|
    |     |     |     |         |     |     |     |     |
    |  7  |  8  |  9  |         |  7  |  8  |  9  | UP  |
    |     |     |     |         |     |     |     |     |
    |-----+-----+-----|         |-----+-----+-----+-----|
    |     |     |     |         |     |     |     |     |
    |MENU |  0  |ENTER|         |MENU |  0  |ENTER|DOWN |
    |     |     |     |         |     |     |     |     |
    |-----+-----+-----|         |-----+-----+-----+-----|

*/

// Descomentar la siguiente linea si se usa un teclado 4x4 - Uncomment next line if using 3x4 keypad
#define USE_KEYPAD_4x4            1

// Descomentar la siguiente linea para mayor sensibilidad del encoder. No recomendado - Uncomment next line for more encoder sensibility. Not recomended. 
//#define SENSITIVE                 1


// Direccion Xpressnet por defecto de Paco Mouse - Default Xpressnet address for PacoMouse (1..31)
#define DEFAULT_XNET_ADR          8


// Descomentar la siguiente linea para alimentar el touchpad desde pines (solo placa PacoMouse) - Uncomment next line to power touchpad from pins (only PacoMouse board)
//#define POWER_TOUCH                1


////////////////////////////////////////////////////////////
// ***** END OF USER OPTIONS *****
////////////////////////////////////////////////////////////


#if  (HW_VERSION == XNET)  
#define USE_XPRESSNET             1                           // Xpressnet  - Arduino Nano & ESP8266 Wemos D1 mini
#endif
#if  (HW_VERSION == LNET) 
#define USE_LOCONET               1                           // Loconet    - Arduino Nano & ESP8266 Wemos D1 mini
#endif
#if  (HW_VERSION == Z21) 
#define USE_Z21                   1                           // Z21        - ESP8266 Wemos D1 mini
#endif
#if  (HW_VERSION == ECOS) 
#define USE_ECOS                  1                           // ECoS/CS1   - ESP8266 Wemos D1 mini
#endif


#ifdef USE_Z21
#define GAME_EXTRA
#define USE_AUTOMATION
#define USE_SET_TIME
#endif

#ifdef USE_ECOS
#define GAME_EXTRA
#define USE_AUTOMATION
#endif

#ifdef USE_XPRESSNET
#if defined(__AVR__)
#define USE_XNWIRE
//#define GAME_EXTRA
#define USE_AUTOMATION
//#define USE_SET_TIME
#endif
#if defined(ESP8266)
#define USE_XNWIFI
#define GAME_EXTRA
#define USE_AUTOMATION
#define USE_SET_TIME
#endif
#endif
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

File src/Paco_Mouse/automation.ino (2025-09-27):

/*    Paco Mouse -- F. Cañada 2022-2025 --  https://usuaris.tinet.cat/fmco/

      This software and associated files are a DIY project that is not intended for commercial use.
      This software uses libraries with different licenses, follow all their different terms included.

      THE SOFTWARE IS PROVIDED "AS IS", WITHOUT WARRANTY OF ANY KIND, EXPRESS OR IMPLIED.

      Sources are only provided for building and uploading to the device.
      You are not allowed to modify the source code or fork/publish this project.
      Commercial use is forbidden.

      Very basic Disk emulation on EEPROM for PacoMouse
      Simple automation for PacoMouse similar to Märklin CS3
*/

#ifdef USE_AUTOMATION

////////////////////////////////////////////////////////////
// ***** EDIT BUFFER *****
////////////////////////////////////////////////////////////

void insertBufEdit (byte pos, byte value) {                         // insert byte on cursor position in edit buffer
  byte n;
  n = EDIT_BUF_SIZE - 1;
  while (n > pos) {
    bufferEdit[n] = bufferEdit[n - 1];
    n--;
  }
  bufferEdit[pos] = value;
}


void deleteBufEdit(byte pos) {                                      // delete byte at cursor position in edit buffer
  while (pos < (EDIT_BUF_SIZE - 1)) {
    bufferEdit[pos] = bufferEdit[pos + 1];
    pos++;
  }
  bufferEdit[EDIT_BUF_SIZE - 1] = OPC_AUTO_END;
}


void newAutoSequence(char *buf) {                                   // creates empty auto sequence leading by name
  byte len, n;
  len = strlen(buf);
  if (len > AUTO_NAME_LNG)
    len = AUTO_NAME_LNG;
  bufferEdit[0] = OPC_AUTO_NAME + len;
  for (n = 0; n < len; n++)
    bufferEdit[n + 1] = buf[n];
  if (!(len & 0x01)) {                                              // space padded if needed
    len++;
    bufferEdit[len] = ' ';
  }
  bufferEdit[len + 1] = OPC_AUTO_END;
  bufferEdit[len + 2] = OPC_AUTO_END;
}


void getNameSequence(char *buf) {                                   // get name from edit buffer
  byte cnt, n;
  buf[0] = 0;
  cnt = bufferEdit[0];
  if (cnt < 16) {
    for (n = 0; n < cnt; n++) {
      buf[n] = bufferEdit[n + 1];
    }
    buf[cnt] = 0;
  }
}


void renameSequence (char *buf) {                                   // rename
  byte bufLen, editLen, len, n;
  len = strlen(buf);
  if (len > AUTO_NAME_LNG)
    len = AUTO_NAME_LNG;
  bufLen = (len | 0x01);
  editLen = bufferEdit[0] | 0x01;
  if (editLen > 15)                                                 // rename only if name exist
    return;
  while (bufLen != editLen) {
    if (editLen > bufLen) {
      deleteBufEdit(0);
      editLen--;
    }
    else {
      insertBufEdit(0, 0);
      editLen++;
    }
  }
  bufferEdit[0] = OPC_AUTO_NAME + len;
  for (n = 0; n < len; n++)
    bufferEdit[n + 1] = buf[n];
  if (!(len & 0x01)) {                                              // space padded if needed
    bufferEdit[len + 1] = ' ';
  }
}


bool isOpcodeEnd (byte pos) {
  if ((bufferEdit[pos] == OPC_AUTO_END) && (bufferEdit[pos + 1] == OPC_AUTO_END))
    return true;
  else
    return false;
}


void setPosEdit(byte num) {
  byte pos;
  editPos = 0;
  if ((bufferEdit[0] & OPC_AUTO_MASK) == OPC_AUTO_NAME)             // skip name
    editPos += (((bufferEdit[0] & 0x0F) | 0x01) + 1);               // padding
  editPos += (num * 2);
}


byte getOpcodeCount() {                                             // get opcode count in the edit buffer
  byte pos, cnt, data;
  pos = 0;
  cnt = 0;
  while (pos < EDIT_BUF_SIZE) {
    if (isOpcodeEnd(pos)) {
      cnt++;
      pos = EDIT_BUF_SIZE;
    }
    else {
      if ((bufferEdit[pos] & OPC_AUTO_MASK) == OPC_AUTO_NAME)
        pos += (((bufferEdit[pos] & 0x0F) | 0x01) + 1);             // padding
      else {
        cnt++;
        pos += 2;
      }
    }
    //DEBUG_MSG("Pos %d: %d", pos, cnt);
  }
  //DEBUG_MSG("Opc cnt: %d", cnt);
  return cnt;
}


////////////////////////////////////////////////////////////
// ***** EEPROM DISK *****
////////////////////////////////////////////////////////////

byte getFileCount() {                                               // get count of files in the disk
  byte n, cnt;
  cnt = 0;
  for (n = 0; n < FAT_SIZE; n++)
    if (!(EEPROM.read(FAT_INI + n) & 0x80))
      cnt++;                                                        // start of file found
  return cnt;
}


byte getEditSectorCount () {                                        // get count of sectors used by edit buffer
  byte pos, cnt;
  pos = 0;
  cnt = 0;
  while (pos < EDIT_BUF_SIZE) {
    //if ((bufferEdit[pos] == OPC_AUTO_END) && (bufferEdit[pos + 1] == OPC_AUTO_END))
    if (isOpcodeEnd(pos))
      pos = EDIT_BUF_SIZE;
    pos += 2;
    cnt += 2;
  }
  return (((cnt - 1) / SECTOR_SIZE) + 1);
}


byte getFileSectorCount (byte posFAT) {                             // get count of sectors used by file
  byte data, nxtSector, cnt;
  cnt = 0;
  data = EEPROM.read(posFAT + FAT_INI);
  while (data != FREE_SECTOR) {
    nxtSector = data & 0x7F;
    cnt++;
    data = (nxtSector == END_SECTOR) ? FREE_SECTOR : EEPROM.read(nxtSector + FAT_INI);
  }
  return cnt;
}
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

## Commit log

2025-07-11 Initial commit
    v0.29
    Firmware for a throttle on the Arduino Nano or Wemos D1 Mini (ESP8266) platform.
    Versions for Loconet, Loconet over TCP/IP, Xpressnet, Xpressnet LAN, ECoS or Z21 protocols
2025-07-20 added gerber
2025-09-13 stl files added
    [PacoMouse_ConsoleLittle-Botones.stl, PacoMouse_ConsoleLittle-Knob.stl, PacoMouse_ConsoleLittle_v2-Bottom Cover.stl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]
2025-12-07 PacoMouse console archives
    [PacoMouse Fondo.stl, PacoMouse OLED 154.stl, PacoMouse OLED 242.stl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]
2025-12-09 stl updated
    [PacoMouse OLED 096.stl, PacoMouse OLED 13.stl, Tapa LNET.stl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]
2026-03-10 Corrected bug using 3 position switch on ESP8266
    [Paco_Mouse.ino, ecos.ino, encoder.ino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]
